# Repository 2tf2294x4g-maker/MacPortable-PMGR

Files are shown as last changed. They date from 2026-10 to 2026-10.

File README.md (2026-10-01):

# Macintosh Portable PMGR replacement

An open replacement for the **Mitsubishi M50753 power manager (PMGR)** in the Macintosh Portable.
The original chip is irreplaceable when it fails; this is a small two-board stack that solders onto
its footprint and runs open firmware on a Microchip **AVR128DB64**, reproducing the original's
behaviour toward the Mac.

| | |
|---|---|
| **Interposer** | 16.3 mm square, castellated — solders onto the M50753's footprint on the logic board |
| **MCU board** | 20.0 × 23.5 mm — carries the AVR, plugs onto the interposer through a Hirose DF12 connector |
| **J21 breakout** *(optional)* | sits between the two for development, bringing every PMGR signal out to 2.54 mm Dupont headers |

## Photos

<table>
<tr>
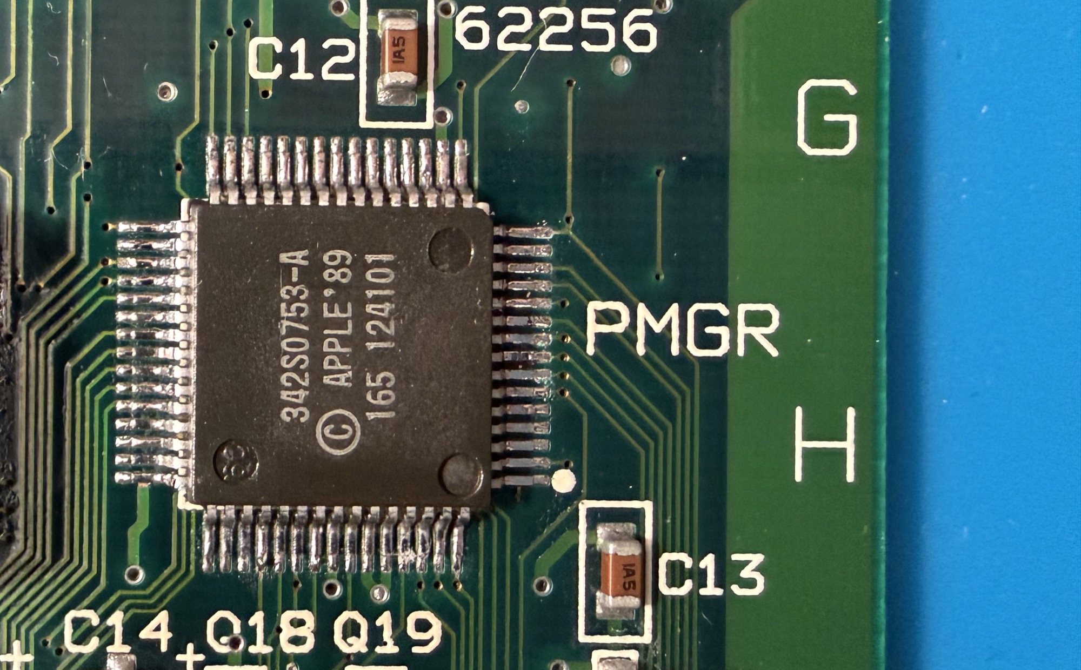
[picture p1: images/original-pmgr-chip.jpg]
The original M50753 power manager on the logic board
<td width="50%"><br><b>Before:</b> the original M50753 (Apple 342S0753-A) at the PMGR position.</td>
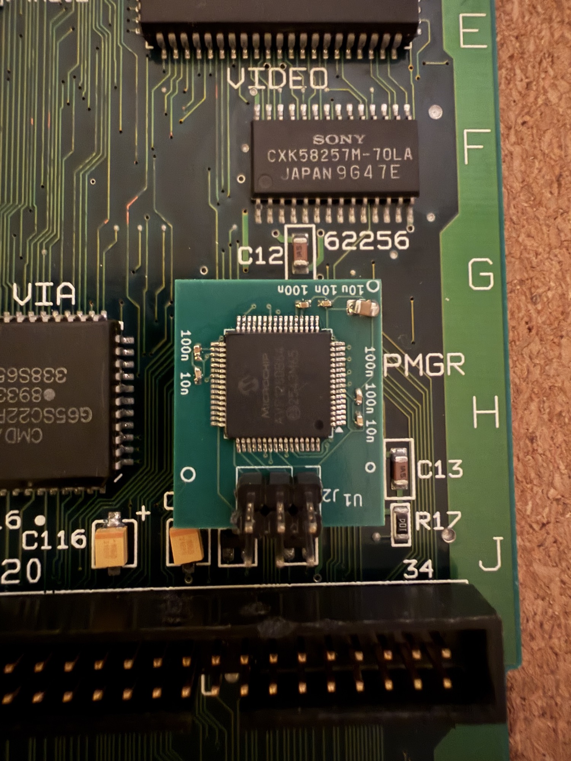
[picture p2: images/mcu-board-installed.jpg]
The replacement MCU board installed at the PMGR position
<td width="50%"><br><b>After:</b> the replacement stack at the same position.</td>
</tr>
<tr>
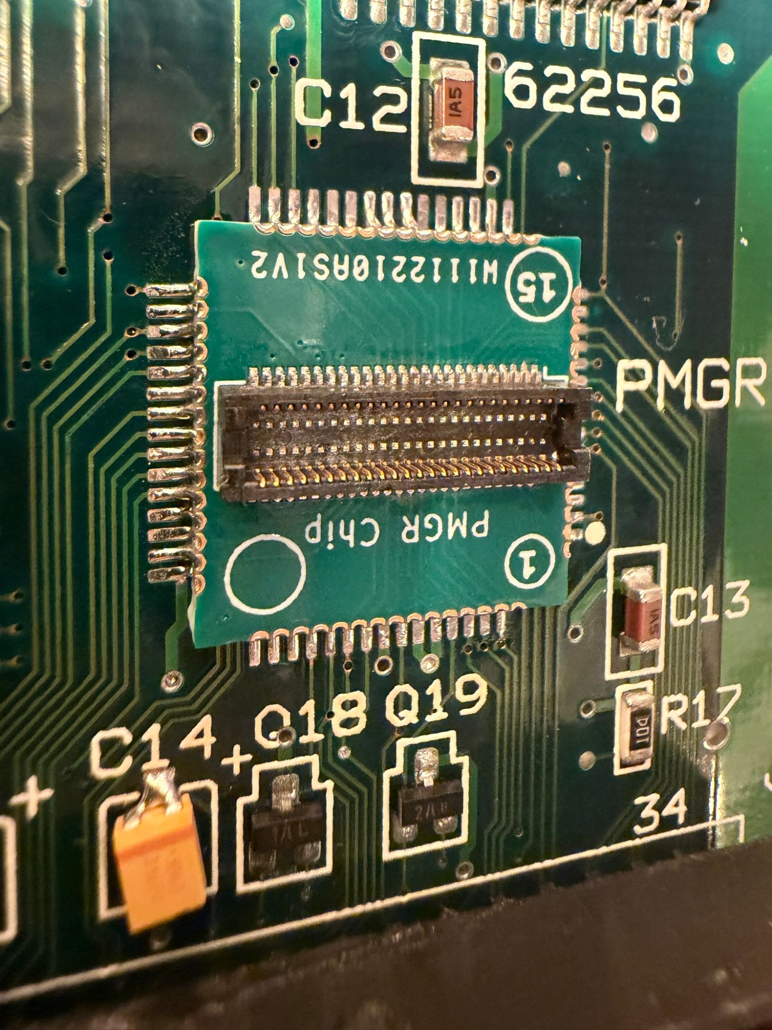
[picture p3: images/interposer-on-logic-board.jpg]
The interposer soldered to the M50753 footprint
<td><br>The interposer soldered to the original footprint. This first batch is labelled <code>PMGR Chip</code>; boards made from the current files say <code>J1</code>.</td>
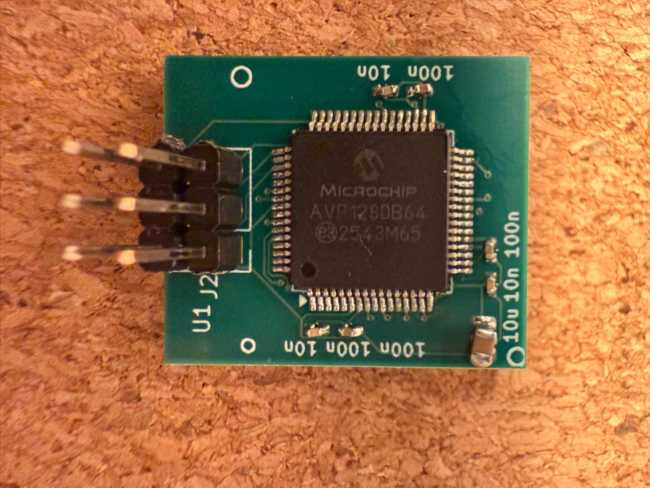
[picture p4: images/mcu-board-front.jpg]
MCU board, top side
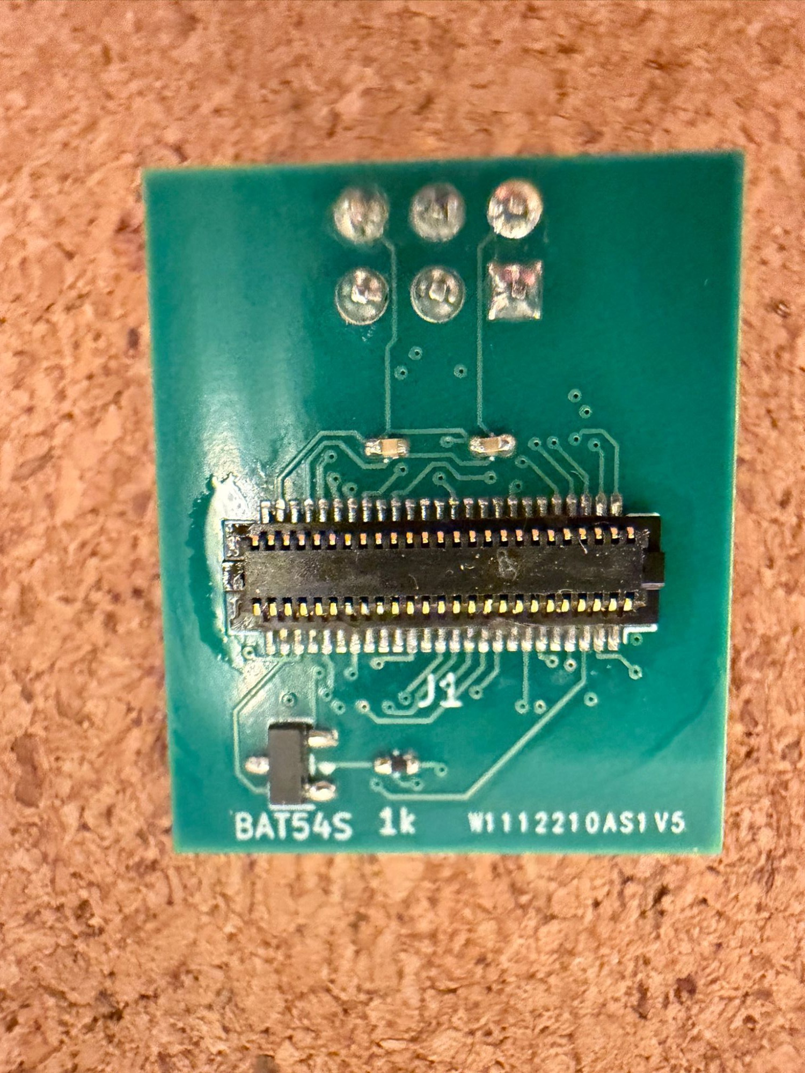
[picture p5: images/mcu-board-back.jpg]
MCU board, underside
<td><br>MCU board, top: the AVR128DB64 and the UPDI programming header <code>J2</code>.<br><br><br>Underside: the DF12 socket <code>J1</code>, and the <code>BAT54S</code> + 1 kΩ clamp on the battery-sense line.</td>
</tr>
</table>

## Status — version 0.1, prototype

**Working in a Macintosh Portable.** It boots, sleeps and wakes, shuts down and honours the reset
switch under System 6.0.8 and 7.5.3, and a supervised fast charge terminates correctly.

It has **only been installed and tested in a Macintosh Portable M5120** (the original, non-backlit
model), with a second, unmodified Portable kept as the reference. **The backlit Portable (M5126) has not
been tried.**

It is a **prototype**. Some parts of the charging behaviour have not been characterised on
hardware yet, and the PowerBook 100 (which uses the same PMGR) has not been tried. Read
[`docs/VERIFIED.md`](docs/VERIFIED.md) for exactly what has and has not been shown — before relying
on it unattended.

## Before you start: this is fine-pitch soldering

Building and fitting this needs **experienced surface-mount work** — it is not a beginner's kit:

- a **0.5 mm-pitch TQFP-64** (the AVR) and two **50-pin, 0.5 mm-pitch** Hirose DF12 connectors;
- **0402** resistors and capacitors (about 1 × 0.5 mm), several on the board's **underside**;
- removing the original **60-lead power manager** from the Mac's logic board, then soldering the
  interposer's **castellated edges** onto that footprint.

You'll want a hot-air station with preheat, a fine-tip iron, flux, solder wick, and magnification —
a stereo microscope makes this far easier. Having the fab assemble the MCU board removes most of the
0.5 mm work; removing the original chip and fitting the interposer still has to be done by hand.
See [`docs/BUILD.md`](docs/BUILD.md).

## ⛔ Safety — read before you start

- **The battery-sense input of an ORIGINAL M50753 is unprotected.** On a machine still carrying
  the original chip, never put more than **6.5 V** on the battery input while probing; over-driving
  that pin is a documented way to destroy the chip. (This design adds a clamp on that line.)
- **Never take power from the floppy connector (J15)** for accessories such as an LCD controller.
  It destroyed a PMGR during development.
- **Supervise the first charge.** The charger was designed for the original Gates/EnerSys Cyclon
  cells, which accept an unlimited initial current. Many modern substitute packs are rated far lower.
- **Every flash must re-write the calibration record** (see [`docs/BUILD.md`](docs/BUILD.md)).
  Without it the firmware deliberately refuses to fast-charge.
- **After any programmer operation — flash, fuses, even just reading the device ID — unplug the
  programmer and power-cycle the machine** (supply or battery disconnected) before expecting it to
  start. Otherwise a machine that is shut down may not wake from the keyboard. While the programmer
  is connected it **back-feeds the board**, so switching off is not a power cycle.

## Repository

```
docs/BUILD.md             start here: order, assemble, program, calibrate, install
docs/PROGRAMMING.md       building the firmware and flashing the AVR, step by step
docs/VERIFIED.md          what has been shown on hardware, and what has not
docs/REFERENCE-MEASUREMENTS.md  known-good voltages and pin references to check against
docs/ASSEMBLY.md          the detailed, bench-tested assembly procedure
docs/PINOUT.md            M50753 pin -> interposer -> AVR mapping
docs/MCU-BOARD-SCHEMATIC.md
docs/BOM.md, ORDER-LIST.md
hardware/mcu-board/       KiCad board + Gerbers
hardware/interposer-v2/   KiCad board + Gerbers
hardware/breakout-j21/    KiCad board + Gerbers + assembly files
firmware/                 AVR firmware, host-side unit tests, fuse policy
tools/                    flashing and calibration scripts
```

## The ROM image

The M50753 carries a small program ROM that the Mac can read back. **The default build contains a
synthetic image — no Apple code anywhere in this repository.** A byte-exact build is possible if you
supply your own dump of the original ROM; see [`firmware/README.md`](firmware/README.md). Never
commit that dump.

## Licences

- Hardware (`hardware/`): **CERN Open Hardware Licence v2 — Strongly Reciprocal** (`LICENSE`)
- Firmware and tools (`firmware/`, `tools/`): **MIT** (`LICENSE-MIT`)

This repository is the clean release. The full development record — every measurement, the
mistakes and their corrections — is kept separately. Questions and results from other machines are
welcome as issues; readings from original, un-modified Portables are especially useful.

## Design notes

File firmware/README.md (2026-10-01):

# Firmware — AVR128DB64

Open replacement firmware for the Macintosh Portable's M50753 power manager. It serves the Mac's
host protocol, runs the battery and charging logic autonomously, handles sleep, wake and reset, and
keeps PRAM in EEPROM.

## Build

```bash
brew trust osx-cross/avr                       # Homebrew gates third-party taps
brew install osx-cross/avr/avr-gcc@14
export PATH="/opt/homebrew/opt/avr-gcc@14/bin:$PATH"   # keg-only
make
```

`avr128db64` is supported natively by avr-gcc 14 — no Microchip device pack needed. The image size
depends on the compiler version (avr-gcc 14.3.0 builds 10715 bytes); never treat a size difference
between toolchains as a regression.

| target | |
|---|---|
| `make` | build `pmgr.hex` |
| `make fuses` | write and verify the fuses — **once per board, before the first flash** (see `FUSES.md`) |
| `make flash PORT=/dev/tty.…` | flash over SerialUPDI. ⚠️ This does **not** write the calibration record; prefer `../tools/pmgr_flash_with_pram.py` (see `../docs/BUILD.md` §7) |
| `make clean` | |

For wiring the programmer and flashing step by step, see [`../docs/PROGRAMMING.md`](../docs/PROGRAMMING.md).

## Host-side tests

The protocol, PRAM save, ADC handling, calibration and charging logic are compiled natively and
tested on your computer — no hardware needed:

```bash
make -C test run_save run_latch run_adb_latch run_deadline run_adc run_charging run_calib run_calib_cross
```

## Layout

```
src/            main.c and one file per subsystem: bus, proto, handlers, adb, adc, calib,
                pram, pwm, rom, selftest
include/        headers. pmgr_pins.h is GENERATED from the MCU board by gen_pins.py
test/           native test harness and the eight suites
gen_pins.py     regenerates include/pmgr_pins.h from hardware/mcu-board/pmgr_mcu.kicad_pcb
tools_rom2h.py  converts YOUR OWN ROM dump to a header, for the byte-exact build (below)
FUSES.md        the fuse configuration pmgr.hex assumes, and why
```

## The ROM image

The Mac can read back the M50753's program ROM. **The default build uses a synthetic image; there
are no Apple bytes in this repository.** For a byte-exact build, supply your own dump:

```bash
python3 tools_rom2h.py /path/to/pmuv1.bin > include/pmgr_rom_image.h
make EXTRA_CFLAGS=-DPMGR_FAITHFUL_ROM
```

⛔ `include/pmgr_rom_image.h` **is** the ROM image. It is gitignored; never commit or publish it.

## Debug pads

| pad | meaning when high |
|---|---|
| `DBG2` (PF3) | the ADC scale self-check passed. ⚠️ Low until the machine has been switched on once |
| `DBG1` (PF4) | an ADC conversion **timed out** — latched, never cleared until reset |
| `DBG0` (PF5) | the RTC/PIT synchronisation timed out |

`DBG2` high with `DBG1` low is a healthy ADC.

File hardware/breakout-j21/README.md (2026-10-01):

# J21 breakout (development only)

A DF12 pass-through that sits between the interposer and the MCU board and brings every PMGR signal
out to **two 1×25 2.54 mm headers labelled with the Portable's J21 pin numbers** — ready for Dupont
leads, a logic analyser or a scope. Take it out before closing the machine.

| | |
|---|---|
| Size | 27 × 88 mm |
| Fab | 2 layer · 1.6 mm · HASL |
| Parts | `J1` DF12 socket (`DS`, bottom), `J2` DF12 header (`DP`, top), two 1×25 2.54 mm headers |
| Fabrication files | `gerbers/` (with BOM, placement and assembly drawings for a PCBA order) |
| Design | `pmgr_breakout_j21.kicad_pcb` (KiCad 9) — see `BOM.md` |

⚠️ **Vias are 0.20 mm drill with a 0.125 mm annular ring.** PCBWay builds that on their standard
order; JLCPCB's standard process needs 0.30 mm / 0.13 mm.

Hand assembly: **solder `J2` (top) first, `J1` (bottom) last**, with the board raised on standoffs —
they sit back to back. Mate each DF12 pair by hand before soldering: every stack height shares the
footprint, and these must be 3.0 mm.

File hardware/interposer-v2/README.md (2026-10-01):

# Interposer

Solders onto the M50753's footprint on the logic board by 60 castellated half-holes, and carries the
DF12 header (`J1`) the MCU board plugs into. It remaps the original chip's pins to the connector —
see [`../../docs/PINOUT.md`](../../docs/PINOUT.md).

| | |
|---|---|
| Size | 16.3 × 16.3 mm |
| Fab | 4 layer · 1.6 mm · **ENIG (required)** · castellated plating on all 60 half-holes |
| Layers | F.Cu / In1.Cu GND / In2.Cu GND / B.Cu |
| Fabrication files | `gerbers/`, `pmgr_interposer_v2_gerbers.zip` |
| Design | `pmgr_interposer_v2.kicad_pcb` (KiCad 9) |

The Gerbers here were regenerated from the board file. Copper, outline and drill are identical to
the boards built and tested in development; only the silkscreen differs — the connector is labelled
`J1`, where the first batch read `PMGR Chip`.

Assembly: [`../../docs/ASSEMBLY.md`](../../docs/ASSEMBLY.md), Steps 2 and 4.

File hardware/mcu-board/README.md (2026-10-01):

# MCU board

Carries the AVR128DB64, its decoupling, a clamp on the battery-sense input, the DF12 socket that
mates with the interposer (`J1`, bottom), and a 2×3 UPDI programming header (`J2`).

| | |
|---|---|
| Size | 20.0 × 23.5 mm |
| Fab | 4 layer · 1.6 mm · ENIG · two-sided stencil |
| Fabrication files | `gerbers/`, `pmgr_mcu_gerbers.zip` |
| Design | `pmgr_mcu.kicad_pcb` (KiCad 9) |

The Gerbers here are the ones the tested boards were made from, and are checked against
`pmgr_mcu.kicad_pcb` on every layer each time this repository is generated. Assembly: [`../../docs/ASSEMBLY.md`](../../docs/ASSEMBLY.md), Step 1. Connections:
[`../../docs/MCU-BOARD-SCHEMATIC.md`](../../docs/MCU-BOARD-SCHEMATIC.md).

⚠️ For a PowerBook 100, `J2` must not be a vertical header — there is only 9–10 mm of clearance.

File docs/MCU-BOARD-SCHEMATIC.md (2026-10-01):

# PMGR MCU Board — Schematic Specification

Everything needed to draw the MCU board in KiCad. All library names verified present in KiCad 9.

---

## Components

| Ref | Value | KiCad symbol | Footprint |
|---|---|---|---|
| **U1** | AVR128DB64-I/PT | `MCU_Microchip_AVR_Dx:AVR128DB64x-xPT` | `Package_QFP:TQFP-64_10x10mm_P0.5mm` *(already set in the symbol)* |
| **J1** | Hirose DF12C3.0-50DS-0.5V | `Connector_Generic:Conn_02x25_Odd_Even` | `Connector_Hirose:Hirose_DF12_DF12C3.0-50DS-0.5V_2x25_P0.50mm_Vertical` — **stock KiCad 9, no custom lib** |
| **J2** | UPDI header 2×3 | `Connector_Generic:Conn_02x03_Odd_Even` | `Connector_PinHeader_2.54mm:PinHeader_2x03_P2.54mm_Vertical` |
| C1–C4 | 100 nF | `Device:C` | 0402 or 0603 |
| C5–C7 | 10 nF | `Device:C` | 0402 or 0603 |
| C8 | 10 µF | `Device:C` | 0805 |
| R1 | 1 kΩ | `Device:R` | 0402/0603 — A/D series resistor |
| D1 | BAT54S | `Diode:BAT54S` | SOT-23 — A/D clamp |

---

## AVR128DB64 pin numbers (TQFP-64, from the KiCad symbol)

| Port | Pin numbers |
|---|---|
| **PORTA** | PA0=**62** PA1=**63** PA2=**64** PA3=**1** PA4=**2** PA5=**3** PA6=**4** PA7=**5** |
| **PORTB** | PB0=8 PB1=9 PB2=10 PB3=11 PB4=12 PB5=13 PB6=14 PB7=15 |
| PORTC | PC0=16 PC1=17 PC2=18 PC3=19 PC4=22 PC5=23 PC6=24 PC7=25 |
| **PORTD** | PD0=26 PD1=27 PD2=28 PD3=29 PD4=30 PD5=31 PD6=32 PD7=**33** *(VREFA/PD7)* |
| **PORTE** | PE0=36 PE1=37 PE2=38 PE3=39 PE4=40 PE5=41 PE6=42 PE7=43 |
| PORTF | PF0=**44** PF1=**45** PF2=46 PF3=47 PF4=48 PF5=49 PF6=**50** *(RESET, input only)* |
| **PORTG** | PG0=52 PG1=53 PG2=54 PG3=55 PG4=58 PG5=59 PG6=60 PG7=61 |
| Power | VDD=**6** GND=**7** AVDD=**34** AGND=**35** VDDIO2=**20** |
| Program | UPDI=**51** |

⚠️ **PA0/PA1 (62/63) are the XTALHF pins** and **PF0/PF1 (44/45) are XTAL32K** — all fine as GPIO here since we use the internal oscillator, but don't fit crystals.

---

## Net list

> **Connector positions updated 2026-08-25** for the routing remap (`ROUTING-ANALYSIS.md`). AVR port grouping is unchanged — it is preserved by MCU-board routing, not by connector numbering. Previous version: `MCU-BOARD-SCHEMATIC.md.bak-perimeter`.

### Data bus — PORTA

**All eight on one port — required.** The protocol handshake depends on reading the bus in a single instruction.

| Net | AVR pin | TQFP | J1 |
|---|---|---|---|
| VIAD0 | PA0 | 62 | **30** |
| VIAD1 | PA1 | 63 | **29** |
| VIAD2 | PA2 | 64 | **28** |
| VIAD3 | PA3 | 1 | **27** |
| VIAD4 | PA4 | 2 | **26** |
| VIAD5 | PA5 | 3 | **33** |
| VIAD6 | PA6 | 4 | **34** |
| VIAD7 | PA7 | 5 | **35** |

### Handshake and control — PORTB

| Net | AVR pin | TQFP | J1 |
|---|---|---|---|
| PMREQ_N | PB0 | 8 | **31** |
| PMACK_N | PB1 | 9 | **32** |
| PMINT_N | PB2 | 10 | **1** |
| SYS_RST_N | PB3 | 11 | **5** |
| RESET_N | PB4 | 12 | **6** |
| PMGR_RESET_N | PB5 | 13 | **8** |
| VIA_TEST | PB6 | 14 | **4** |
| ONESEC_N | PB7 | 15 | **2** |

### Power control — PORTG

| Net | AVR pin | TQFP | J1 |
|---|---|---|---|
| SYS_PWR_N | PG0 | 52 | **17** |
| MINUS5_EN | PG1 | 53 | **16** |
| SOUND_PWR_N | PG2 | 54 | **46** |
| SERIAL_PWR_N | PG3 | 55 | **45** |
| MODEM_PWR_N | PG4 | 58 | **44** |
| HD_PWR_N | PG5 | 59 | **43** |
| SCC_CNTRL | PG6 | 60 | **42** |
| IWM_CNTRL | PG7 | 61 | **41** |

### Status inputs — PORTE

| Net | AVR pin | TQFP | J1 |
|---|---|---|---|
| AKD | PE0 | 36 | **18** |
| STOP_CLK | PE1 | 37 | **19** |
| CHRG_ON_N | PE2 | 38 | **20** |
| KBD_RST_N | PE3 | 39 | **21** |
| HICHG | PE4 | 40 | **22** |
| RING_DETECT | PE5 | 41 | **15** |
| MODEM_AB | PE6 | 42 | **14** |

### ADB, display, misc — PORTD

| Net | AVR pin | TQFP | J1 |
|---|---|---|---|
| PMGR_ADB | PD1 | 27 | **13** |
| FDB | PD2 | 28 | **12** |
| DISP_BLANK_N | PD3 | 29 | **11** |
| MODEM_INS_N | PD4 | 30 | **10** |
| SOUND_OFF | PD5 | 31 | **3** |
| PMGR_PWM | PD6 | 32 | **36** |

### Analogue and remaining — PORTD/PORTC

> `PMGCLK_F` is **monitor-only**. It is M50753 pin 19 (Xin) and the AVR runs from its internal 24 MHz oscillator. It is wired to PC4 so firmware can observe it, but the AVR accepts an external clock **only on PA0**, which is VIAD0 — so it can never be used as a clock source.

| Net | AVR pin | TQFP | J1 |
|---|---|---|---|
| AD_FILTER | PD0 | 26 | **38** |
| PMGR_IN0 | PD7 | 33 | **37** |
| SOUND_LATCH | PC0 **⚠️ MVIO** | 16 | **39** |
| OFF_HOOK | PC1 **⚠️ MVIO** | 17 | **40** |
| SIXTYHZ | PC2 **⚠️ MVIO** | 18 | **7** |
| PMGCLK_F | PC4 **⚠️ MVIO** | 22 | **9** |

### Debug indicators — PORTF ⭐ ADDED 2026-08-28

| Net | AVR pin | TQFP | J1 |
|---|---|---|---|
| DBG0 | PF5 | 49 | *(test pad)* |
| DBG1 | PF4 | 48 | *(test pad)* |
| DBG2 | PF3 | 47 | *(test pad)* |

⚠️ **These were missing from this document while the firmware already drove
them.** Found by cross-checking `firmware/include/pmgr_pins.h` against this net
list, 2026-08-28. PF3-PF5 are free (only PF0/PF1 and PF6 are reserved), so there
is no conflict — but there were no PADS, and that defeats the purpose.

**They must be brought out to test pads.** The whole design intent is that they
are readable with a DMM the instant the AVR is programmed — no host, no
analyser, no ADB (see the header comment in `firmware/src/pmgr_adc.c`). On a
20 x 23.5 mm board inside a closed Portable, an un-padded TQFP pin cannot be
probed, so the diagnostic path simply does not exist.

What they report in the NORMAL build:

| Pin | HIGH means |
|---|---|
| DBG2 | ADC scale self-check PASSED (`ref5V_Level` ≈ **113**) |
| DBG1 | ⛔ an ADC conversion TIMED OUT — every reading since is a stand-in |
| DBG0 | ⛔ RTC/PIT sync timed out |

⛔ **DBG2 is LOW until the machine has been switched on at least once**, and
that is correct, not a fault. AD_Ref sits on the switched `(5/0)` rail and reads
~0 V while the machine is off, so the scale cannot be verified at power-on — the
check is deferred to the 1 Hz tick and latches its pass the first time the rail
is up. ⚠️ This supersedes the claim that the check is *"measurable the instant
the AVR is programmed"*: with no machine attached, DBG2 stays low forever.
`MEASUREMENTS.md` 2.56.

DBG2 high with DBG1 low is a healthy ADC. The SELFTEST build reuses all three as
a 3-bit result code instead — see `pmgr_selftest.h`.

1 mm round pads on the top side are enough; they are probed with a meter tip,
not clipped.

### Power — plane connections

**GND is a plane on both inner layers** — each pad simply vias down to it. **+5V is routed as ordinary traces** (only five connection points on the interposer).

| Net | J1 positions | How carried |
|---|---|---|
| +5V | **47, 48** | routed traces |
| GND | **23, 24, 25, 49** | In1.Cu + In2.Cu planes |
| *spare* | **50** | — |

---

## Power supply

```
+5V (always-on rail, from J1 pins 47/48)
 ├── VDD    (pin 6)   ── C1 100nF ── GND    + C5 10nF
 ├── AVDD   (pin 34)  ── C2 100nF ── GND    + C6 10nF
 ├── VDDIO2 (pin 20)  ── C3 100nF ── GND    + C7 10nF
 └── bulk             ── C8 10µF  ── GND
GND ── AGND (pin 35), GND (pin 7)
```

**Datasheet requirements (§4.2, §5.3):**
- All VDD/AVDD pins at the **same voltage**; AVDD must **ramp with VDD**
- In single-supply mode **VDDIO2 must rise with VDD** — tie it to +5V even though PORTC is lightly used
- One decoupling pair **per supply pin**, same side of the board, shortest possible traces, capacitors first in the power chain

---

## A/D clamp — the one improvement over Apple's design

The M50753 dies when the battery-sense line exceeds Vcc+0.3 V. Protect the input:

```
J1 pin 38 (AD_FILTER) ──[ R1 1k ]──┬── PD0 (pin 26, ADC)
                                    │
                                 D1 BAT54S
                              (dual Schottky)
                     pin 1 GND · pin 2 +5V · pin 3 ADC_IN
                     (one diode GND→ADC_IN, one ADC_IN→+5V)
```

R1 limits fault current; the BAT54S clamps to the rails. ⛔ Corrected 2026-09-14: this drawing said "anode→+5V, cathode→GND",
which is the reverse of a clamp; the layout was always right (MEASUREMENTS 2.192 correction). Measured the same day: pin 40 and the
reported level agree within 1 level, so R1 and D1 cost nothing. Sized so a hybrid swinging toward battery voltage can't damage the ADC input.

---

## UPDI header (J2, 2×3)

Datasheet §4.4.1 recommends a 2×3 100-mil header even though only three pins are used, because programming tools ship with 2×3 connectors.

| J2 pin | Net |
|---|---|
| 1 | UPDI → U1 pin 51 |
| 2 | +5V |
| **3** | ⭐ **`DBG0`** → U1 pad **49** (`PF5`) |
| **4** | ⭐ **`DBG1`** → U1 pad **48** (`PF4`) |
| **5** | ⭐ **`DBG2`** → U1 pad **47** (`PF3`) |
| 6 | GND |

> ⛔⛔ **CORRECTED 2026-09-09 FROM THE FABRICATED BOARD FILE.** This table said
> *"3, 4, 5 — no connect"*. **It was wrong.** `mcu-board/pmgr_mcu.kicad_pcb`
> routes all three to the `DBG` nets, pad for pad.
>
> ⚠️ **The error propagated the wrong way.** `ASSEMBLY.md` correctly said *"`J2`
> carries UPDI plus `DBG0/1/2`"*, and on 2026-09-08 that correct statement was
> **overridden** on the strength of this table — sending the operator to hunt for
> test pads that do not exist. ⭐ There are **no `TP` footprints on this board**;
> the header *is* the debug access.
>
> ⛔ **The lesson: the board file outranks the prose.** Both were available; the
> prose was believed.

Pins 2 and 6 are the standard VCC/GND positions on the AVR 6-pin header. **Confirm pin 1 for UPDI against your programmer** — Atmel-ICE and SNAP differ, and some tools expect UPDI on pin 5 (the RESET position).

---

## Not fitted

- **No crystal.** Internal oscillator does 24 MHz. Leave PA0/PA1 and PF0/PF1 as GPIO or unused.
- **No external RESET pull-up** — internal pull-up is sufficient (§4.3). Add a switch only if wanted: 330 Ω in series, 100 nF to GND.
- **PF6 (50) is RESET, input only** — leave it.

---

## J1 — board-to-board connector (RESOLVED 2026-08-25)

**Hirose DF12(3.0) series, 0.5 mm pitch, 50 position, 3.0 mm mated stack height.**

| Board | Part | KiCad footprint |
|---|---|---|
| **MCU board** (J1) | **DF12C3.0-50DS-0.5V** — socket | `Connector_Hirose:Hirose_DF12_DF12C3.0-50DS-0.5V_2x25_P0.50mm_Vertical` |
| **Interposer** (J1) | **DF12E3.0-50DP-0.5V** — header | `Connector_Hirose:Hirose_DF12_DF12E3.0-50DP-0.5V_2x25_P0.50mm_Vertical` |

Both footprints ship with KiCad 9 — nothing to source or draw.

### Land pattern — verified against the Hirose datasheet (doc A306, p.10)

Read directly from the *Recommended PCB Footprint* drawing and cross-checked against the KiCad footprints; **every value agrees**:

| Dimension | Datasheet | KiCad |
|---|---|---|
| Pitch (P) | 0.5 ± 0.02 | 0.5 ✓ |
| Pad width | 0.3 ± 0.02 | 0.3 ✓ |
| Pad length | 1.6 ± 0.02 | 1.6 ✓ |
| Gap between rows | 2.0 ± 0.05 | (3.6 − 1.6) = 2.0 ✓ |
| Row centre-to-centre | 3.6 (derived) | 3.6 ✓ |
| Contact span (B) | 12.0 | 12.0 ✓ |
| Body length (A) | 14.6 (DS) / 14.7 (DP) | — |
| Boss holes | ⌀0.6 +0.05/−0.03, D = 14.1 apart | not present — **these variants have no guide boss** |

### Pin numbering — confirmed

**Pins 1–25 run along one row, 26–50 along the other** (not odd/even staggered). The DP footprint is mirrored relative to DS, so when the two boards are stacked the pins mate **1↔1 … 50↔50** with no renumbering. The net list above can be used verbatim on both boards.

### Height budget — OK

DF12(3.0) adds **3.0 mm** between the two board faces. Total stack above the logic board:

```
interposer PCB (0.8–1.6) + 3.0 mm connector + MCU PCB (0.8–1.6)  ≈ 4.6–6.2 mm
```

The M50753 it replaces is ~2.0 mm tall, so this adds ~3–4 mm over stock.

**Available clearance = 15 mm — measured.** Datum: **logic board surface → the underside of the keyboard / top plastic** on the Macintosh Portable. That is the same datum the stack above is built from, so the comparison is direct:

```
                    Portable   PowerBook 100
available            15.0 mm      10.4 mm     <- measured 2026-09-06
needed                6.2 mm       6.2 mm     (worst case, 1.6 mm boards)
margin                8.8 mm       4.2 mm
                       2.4x         1.7x
```

⭐ **Both machines measured.** The PowerBook 100 is the **binding** one vertically
and still clears by 1.7×.

**Height is not a constraint on this design.** DF12(3.0) confirmed **on both
machines**; no need to consider the shorter stack heights. ⭐⭐ That matters beyond
height: `CLEARANCE-MEASUREMENTS.md` notes the Portable's 4.1 mm VIA clears by only
0.5 mm at DF12(3.0) and **collides at every shorter stack**, so a PB100 that had
needed a 2.5 or 2.0 mm connector would have forced the outline in on that side.
It does not.

*(If a future revision ever does need to come down, DF12 is made in 2.0 and 2.5 mm stack heights with an **identical land pattern** — part number only, never the layout.)*

---

## Checks before ordering

1. ~~Verify **J1 pin numbering**~~ — **done**, see above
2. Confirm the **AIN channel number for PD0** in the ADC chapter (needed for firmware, not layout)
3. ~~Re-check M50753 pin numbers on the interposer side against sheet 12~~ —
   ✅ **ALREADY DONE 2026-08-26, on two independent sources.** Castellation
   numbering validated against the **PowerBook 100 silkscreen**; signal names
   from the annotated photograph of the actual M50753 **cross-checked against
   Apple sheet 12** and the firmware disassembly. See `PIN-MAPPING-PERIMETER.md`
   and `PIN-AUDIT.md`.
   ⚠️ This box sat unticked and on 2026-08-28 sent someone to re-verify it. See
   the warning in `PORT-AUDIT.md`: **a document can be stale even when the
   project's knowledge is not — before treating an item here as open, check
   whether another file has since closed it.**
5. ⭐ **Add test pads for DBG0/DBG1/DBG2 (PF5/PF4/PF3)** — see the net list
   above. Without them the power-on diagnostics cannot be read on an assembled
   board, which is the only reason they exist.
6. ✅ **Firmware pin map cross-checked against this net list 2026-08-28** — all
   43 shared nets agree on port, bit and TQFP number, and all 39 J1 positions
   agree with `PIN-MAPPING-PERIMETER.md`. Re-run that check if either file
   changes; it is the mapping the firmware silently depends on
4. ~~Measure vertical clearance over the U15H footprint~~ — **done: 15 mm measured vs 6.2 mm needed**, 2.4× margin

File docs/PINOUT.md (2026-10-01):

> ⚠️ **2026-08-26:** `FDB` (M50753 pin 27) is **`ADB_In`** — Port 4 bit 1, the ADB
> receive line. ADB is two pins: `ADB_Out` (P40, our `PMGR_ADB`) and `ADB_In`
> (P41, our `FDB`). See `PORT-AUDIT.md`.

# Interposer Pin Mapping

M50753 footprint pin → signal → interposer connector position → AVR port.

Chip pin numbers from Apple schematic 050-0219 sheet 12. Signal names and unused pins confirmed against the PMU firmware disassembly.

> ⚠️ **Verify every chip pin number against sheet 12 before routing.** These were transcribed from a scan.

---

## Design principles

**VIAD0–7 must land on one complete AVR port, in bit order.** The data bus is read and written as a whole byte in the hottest path of the handshake; splitting it across ports costs instructions on every transfer.

**PMREQ must be on an interrupt-capable pin** — the host asserting PMREQ is what drives the whole exchange.

**Group the handshake outputs** (PMACK, PMINT) on one port so they can be updated without read-modify-write races.

**Connector positions are grouped by function**, not by chip pin order — it makes both the interposer routing and the MCU board routing cleaner than a straight 1:1 mapping.

---

> ⛔ **2026-08-28 — THE PER-GROUP TABLES BELOW ARE STALE IN TWO COLUMNS.**
> Only the **Chip pin** and **Signal** columns are current. Both the **Conn** and
> the **AVR** columns are superseded drafts and will send you to the wrong pad and
> the wrong AVR pin:
>
> | Column | Superseded by | Example of the error |
> |---|---|---|
> | **AVR** | the *Revised assignment (final)* table further down this file, and `firmware/include/pmgr_pins.h` | handshake + control is on **PORTB**, not PORTC. PORTC is the **MVIO** port and is left spare. VIA_TEST is **PB6**, not PC6 |
> | **Conn** | `PIN-MAPPING-PERIMETER.md` / `ROUTING-ANALYSIS.md` ("Conn (new)") | VIA_TEST is connector position **4**, not 15 |
>
> The file already warns, below the final table, that *"two earlier drafts of this
> table were wrong."* These are those drafts. They are kept because the chip-pin ↔
> signal transcription against sheet 12 is still the record; the routing is not.
> **`firmware/include/pmgr_pins.h` is authoritative for AVR pins.**

## Signals to route (45 of 60)

### Data bus — 8 lines · AVR PORTA (contiguous, bit order)
⛔ **`Conn` and `AVR` below are STALE DRAFTS** — see the warning at the top. Current: connector = `PIN-MAPPING-PERIMETER.md`, AVR pin = `MCU-BOARD-SCHEMATIC.md`.

| Chip pin | Signal | Conn | AVR |
|---|---|---|---|
| 5 | VIAD0 | 1 | PA0 |
| 4 | VIAD1 | 2 | PA1 |
| 3 | VIAD2 | 3 | PA2 |
| 2 | VIAD3 | 4 | PA3 |
| 1 | VIAD4 | 5 | PA4 |
| 60 | VIAD5 | 6 | PA5 |
| 59 | VIAD6 | 7 | PA6 |
| 58 | VIAD7 | 8 | PA7 |

### Handshake and system control — 8 lines · AVR PORTC
⛔ **`Conn` and `AVR` below are STALE DRAFTS** — see the warning at the top. Current: connector = `PIN-MAPPING-PERIMETER.md`, AVR pin = `MCU-BOARD-SCHEMATIC.md`.

| Chip pin | Signal | Dir | Conn | AVR | Note |
|---|---|---|---|---|---|
| 6 | PMREQ* | in | 9 | **PC0** | **interrupt-capable pin required** |
| 7 | PMACK* | out | 10 | PC1 | |
| 8 | PMINT* | out | 11 | PC2 | pulsed, not held |
| 12 | SYS_RST* | out | 12 | PC3 | releases CPU + gates ROM overlay |
| 13 | RESET* | out | 13 | PC4 | |
| 18 | PMGR_RESET* | in | 14 | PC5 | system can reset the PMGR |
| 11 | VIA_TEST | — | 15 | PC6 | |
| 9 | 1SEC* | out | 16 | PC7 | → VIA CA2 |

### Power control outputs — 8 lines · AVR PORTD
⛔ **`Conn` and `AVR` below are STALE DRAFTS** — see the warning at the top. Current: connector = `PIN-MAPPING-PERIMETER.md`, AVR pin = `MCU-BOARD-SCHEMATIC.md`.

| Chip pin | Signal | Conn | AVR |
|---|---|---|---|
| 37 | **SYS_PWR*** | 17 | PD0 |
| 38 | −5_EN | 18 | PD1 |
| 39 | SOUND_PWR* | 19 | PD2 |
| 40 | SERIAL_PWR* | 20 | PD3 |
| 41 | MODEM_PWR* | 21 | PD4 |
| 42 | HD_PWR* | 22 | PD5 |
| 43 | SCC_CNTRL | 23 | PD6 |
| 44 | IWM_CNTRL | 24 | PD7 |

### Status inputs — 7 lines · AVR PORTE/F
⛔ **`Conn` and `AVR` below are STALE DRAFTS** — see the warning at the top. Current: connector = `PIN-MAPPING-PERIMETER.md`, AVR pin = `MCU-BOARD-SCHEMATIC.md`.

| Chip pin | Signal | Conn | Note |
|---|---|---|---|
| 35 | AKD | 25 | any key down |
| 34 | STOP_CLK | 26 | |
| 33 | CHRG_ON* | 27 | charger present |
| 32 | KBD_RST* | 28 | resets keyboard M50740 |
| 31 | HICHG | 29 | |
| 30 | RING_DETECT | 30 | |
| 29 | MODEM_A/B | 31 | |

### ADB, display, misc — 6 lines
⛔ **`Conn` and `AVR` below are STALE DRAFTS** — see the warning at the top. Current: connector = `PIN-MAPPING-PERIMETER.md`, AVR pin = `MCU-BOARD-SCHEMATIC.md`.

| Chip pin | Signal | Conn |
|---|---|---|
| 28 | PMGR_ADB (out) | 32 |

> ⛔⛔ **MEASURED 2026-09-05 (`MEASUREMENTS.md` 2.48): `PMGR_ADB` is INVERTED,
> ~1 V, and OUTPUT-ONLY.**
>
> | `PMGR_ADB` | ADB bus |
> |---|---|
> | **LOW (0 V)** | **RELEASED** (high) — also the state while listening |
> | **HIGH (~0.6–1.0 V)** | **PULLED LOW** |
>
> ⭐ The ~1 V maximum is not a valid CMOS high: pin 28 drives a **transistor base
> or open-drain stage**, not a logic input. Confirmed output-only — when the
> keyboard drives the bus low, pin 28 stays at **0.00 V** rather than following
> it.
>
> ⛔ **Driving this push-pull with active-high = bus-high holds the ADB line low
> permanently.** That presents as a dead keyboard and mouse, with no obvious
> electrical fault to find.
| 27 | FDB (ADB in) | 33 |
| 26 | DISP_BLANK* | 34 |
| 25 | MODEM_INS* | 35 |
| 10 | SOUND_OFF | 36 |
| 57 | PMGR_PWM | 37 |

### Analogue and clocks — 6 lines
⛔ **`Conn` and `AVR` below are STALE DRAFTS** — see the warning at the top. Current: connector = `PIN-MAPPING-PERIMETER.md`, AVR pin = `MCU-BOARD-SCHEMATIC.md`.

| Chip pin | Signal | Conn | Note |
|---|---|---|---|
| 52 | **A/D_FILTER** | 38 | **ADC pin. Clamp on MCU board.** |
| 54 | PMGR_IN0 | 39 | |
| 51 | SOUND_LATCH | 40 | |
| 50 | OFF_HOOK | 41 | |
| 15 | 60HZ | 42 | → INT1 |
| 19 | PMGCLK_F | 43 | original Xin — **not needed**, AVR uses internal osc |

### Power — 2 lines
| Signal | Conn |
|---|---|
| VCC (always-on 5V) | 44, 45 |
| GND | 46, 47, 48 |

Spare / unrouted: 49, 50

---

## Pins deliberately NOT routed (15)

| Chip pin | Why |
|---|---|
| 36 (P10) | Firmware comments it **"NC — not connected, probably for testing"** |
| 49 (IN4) | PMGR_IN4 — unused by firmware |
| 48, 47, 46 (IN5–7) | unused |
| 20 (Xout) | crystal out — AVR uses internal oscillator |
| 22 (RSTout) | not needed |
| 14 (CNTR), 21, 24 (2PH) | timer/counter pins, unused in this application |
| 16 (INT2) | tied to RESET*, already routed as pin 13 |
| 23, 45, 53, 55, 56 | Vcc/Vss duplicates and no-connects — **verify against sheet 12** |

⚠️ **Route the castellation pads for these anyway** (mechanically they still land on the Mac's footprint) — just leave them unconnected on the interposer. Do **not** omit the physical pads.

---

## Connector

**50 positions used of 50.** Suggests the **0.4 mm Hirose DF40** (10 mm long) over the 0.5 mm part, since it opens the routing channel from 1.9 mm to 3.15 mm — enough for 15 traces per side on two layers at standard 6/6 mil rules.

Order positions so each functional group is contiguous, as above. That keeps interposer routing short and makes the MCU board's port assignment fall out naturally.

---

## AVR port assignment — REVISED against the datasheet (2026-08-24)

Verified from AVR128DB28/32/48/64 datasheet DS40002247B.

**AVR128DB64 ports:** PA[7:0], PB[7:0], PC[7:0], PD[7:0], PE[7:0], PF[6:0], PG[7:0] — **55 GPIO** (54 usable as outputs).

### Three datasheet findings that change the plan

**1. "External interrupt on all general purpose pins."** Any pin can take PMREQ — no constraint at all. My earlier note about needing an interrupt-capable pin was wrong.

**2. PF7 is dedicated UPDI, not a GPIO.** The port list is PF[**6**:0], so PF7 never appears as I/O. Nothing to "reserve" — it simply isn't available. **PF6 is RESET and is input-only.**

**3. ⚠️ PORTC is the MVIO port** — powered from a separate **VDDIO2** pin. If VDDIO2 is not connected, **PORTC does not work.** The datasheet requires it to be treated as a full supply pair with its own decoupling.

**4. ⚠️ The ADC is on PORTD.** The Power Domain Overview (datasheet Figure 5-1, §5.1) shows **PD[7:0] → ADC**. PE[7:0] feeds the DAC / AC / OPAMP block; PF[1:0] goes to XOSC32K. So the analogue input must land on **PORTD**, not PORTF.

### Revised assignment (final)

| AVR port | Use | Notes |
|---|---|---|
| **PORTA[7:0]** | **VIAD0–7** | contiguous, bit order — whole-byte bus access |
| **PORTB[7:0]** | **handshake + control** | PMREQ, PMACK, PMINT, SYS_RST, RESET, PMGR_RESET, VIA_TEST, 1SEC. VDDIO domain — no MVIO dependency |
| **PORTG[7:0]** | power control outputs | written as a group |
| **PORTE[7:0]** | status inputs | AKD, STOP_CLK, CHRG_ON, KBD_RST, HICHG, RING_DETECT, MODEM_A/B |
| **PD0** | **A/D_FILTER** | **ADC input — PORTD is the ADC port.** Confirm the AIN channel number in the ADC chapter |
| PD1–PD7 | ADB, display, misc | PMGR_ADB, FDB, DISP_BLANK, MODEM_INS, SOUND_OFF, PMGR_PWM |
| PORTC | **spare** | MVIO port — usable, but requires VDDIO2 |
| PF[6:0] | mostly unused | PF[1:0] = XOSC32K, PF6 = RESET (input only) |
| PF7 | UPDI | not GPIO |

⚠️ Two earlier drafts of this table were wrong: the handshake was on PORTC (MVIO) and then on PORTD (the ADC port). **This version is the one to build from.**

**45 signals into 55 GPIO** — comfortable margin, and PORTC stays free as spare.

### Hardware requirements from §4 of the datasheet

- **Decoupling per supply pin pair:** 100 nF primary + 1–10 nF HF, optional 1 µF. Same side of the board as the MCU, traces as short as possible, capacitors first in the power chain.
- **All VDD pins are internally connected** and must all see the same voltage.
- **AVDD** is internally tied to VDD on this device but still needs its own decoupling.
- **VDDIO2** — tie to VDD (5V) and decouple it, even if PORTC is unused. The datasheet is explicit (§5.3): *"If the device is configured in single-supply mode, the VDDIO2 voltage must also rise closely to VDD."*
- **AVDD must ramp with VDD** (§5.3): *"The AVDD voltage must ramp up closely with the VDD voltage during power-up to ensure proper operation."* Tie them together at the board level.
- GND is common to VDD, AVDD and VDDIO2.
- **RESET** has an internal pull-up; an external one is not required. If you fit a reset switch, use 330 Ω in series with the switch and 100 nF to ground.
- ⚠️ **UPDI can be enabled via a high-voltage pulse on RESET** — so keep anything fragile off that pin.

### UPDI header

The datasheet recommends **UPDI Connection v1: a 2×3 100-mil header**, even though only three pins are used, because most programming tools ship with 2×3 connectors. On a 25–30 mm MCU board that fits easily — use it rather than bare pads.

(UPDI v2 adds RESET to the connection; v1 is fine for this.)

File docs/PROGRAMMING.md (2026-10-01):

# Programming the AVR

How to build the firmware, connect a programmer, and flash the AVR128DB64 on the MCU board — on the
bench, or later with the stack fitted in the Mac.

## What you need

- **A USB-serial adapter used as a "SerialUPDI" programmer.** UPDI is a one-wire serial protocol, so
  any USB-UART adapter works if its **TX and RX are joined through a resistor**. Use a **5 V-capable**
  adapter: the board runs at 5 V, and a 3.3 V-only adapter is marginal.
- **A resistor of 470 Ω to 1 kΩ** (1 kΩ is a good default). ⚠️ The widely copied 4.7 kΩ is too
  high. ⚠️ Adapters such as the Tigard have **no** built-in UPDI resistor — fit one.
- **`pymcuprog`** (Microchip's programming tool): `pip3 install pymcuprog`
- **avr-gcc 14** to build the firmware — see [`../firmware/README.md`](../firmware/README.md).

## The programming header, J2

`J2` is the 2 × 3 header on the MCU board:

```
  J2-1  UPDI      J2-2  +5 V      J2-3  DBG0
  J2-4  DBG1      J2-5  DBG2      J2-6  GND
```

⛔ **`J2-2` is the board's +5 V, and it connects through the stack to the Mac's +5 V always-on
rail.** So:

| situation | power the board from | connect |
|---|---|---|
| **MCU board on its own**, on the bench | the programmer | UPDI (J2-1), +5 V (J2-2), GND (J2-6) |
| **Stack fitted in the Mac** | **the Mac** (bench supply or battery at the battery input) | **UPDI (J2-1) and GND (J2-6) only — leave J2-2 off** |

Never let the programmer try to power the Mac's always-on rail through `J2`.

## Wiring the adapter

```
  adapter TX ──[ 1 kΩ ]──┬── J2-1  UPDI
  adapter RX ────────────┘
  adapter GND ───────────── J2-6  GND
  adapter 5 V ───────────── J2-2  +5 V      (bench only — see the table above)
```

⚠️ **On a dual-port adapter (FT2232-based, e.g. the Tigard), use the FIRST port.** It appears as
two serial ports; only the first (channel A) answers. The second reports "UPDI initialisation failed".

## Step by step

**1. Build.**
```bash
make -C firmware
```

**2. Read the device ID first — before writing anything.**
```bash
pymcuprog ping -t uart -u /dev/tty.usbserial-XXXX -d avr128db64
```
It must answer **`1E970B`**. That one reply proves the chip is alive, is the right part, and that
UPDI, power and ground are all connected. If it fails here, nothing has been written yet.

**3. Fuses — once per board, before the first flash.**
```bash
make -C firmware fuses PORT=/dev/tty.usbserial-XXXX
```
See [`../firmware/FUSES.md`](../firmware/FUSES.md) for what is set and why.

**4. Flash.** Use the flash tool, so the board's calibration record is written at the same time:
```bash
export PMGR_UPDI_PORT=/dev/tty.usbserial-XXXX
python3 tools/pmgr_flash_with_pram.py firmware/pmgr.hex <md5-prefix> - calib.args
```
- `<md5-prefix>` is the first 8 characters of `md5 -q firmware/pmgr.hex` (on Linux: `md5sum`). The
  tool **refuses** a hex whose checksum doesn't match, so you can't flash the wrong file.
- `-` means "write no PRAM image"; the Mac initialises PRAM itself.
- `calib.args` is the board's calibration record — see [`BUILD.md`](BUILD.md) §7. On a brand-new
  board without one yet, leave the last argument off; the firmware then simply won't fast-charge.
- ⭐ **The tool checks every input file before it erases anything** — the record's length, checksum
  and values. A missing or bad file stops it with "NOTHING HAS BEEN FLASHED", so the board keeps its
  existing record.
- Look for **`write: OK | verify: matches`** and **`calibration record at 464 read back identical:
  True`**.

`make -C firmware flash PORT=…` also works, but it **does not** write the calibration record.
⛔ **Every flash erases the EEPROM**, so flashing that way leaves the board without its record.

**5. Unplug the programmer and do a real power cycle.** Disconnect the supply or battery, wait a
few seconds, reconnect. ⛔ Do this after **any** programmer operation — even step 2's ID read. Without
it, a machine that is shut down may not wake from the keyboard (seen 7 times out of 7; cause not
established). A programmer left plugged in back-feeds the board, so switching off alone is not
enough.

## Resetting PRAM

**Pulling the battery does not reset PRAM on this board** — PRAM is kept in the AVR's EEPROM and
survives power removal. Try `Cmd-Opt-P-R` at startup first. If PRAM holds settings that stop the
Mac booting at all, **re-flash through the flash tool** (step 4), with the same `calib.args`:

- every flash **erases the whole EEPROM**, which clears PRAM, and the Mac writes fresh defaults on
  the next start;
- the tool then **writes the calibration record back**.

⛔ **Don't erase the EEPROM any other way.** The calibration record lives there too (bytes 464–479),
and losing it silently disables fast charge. Then unplug the programmer and power-cycle, as always.

## Troubleshooting

| symptom | likely cause |
|---|---|
| `UPDI initialisation failed` | **The board isn't powered.** A connected programmer back-feeds only about 1.65 V, below the AVR's 2.85 V brown-out, so it can't be programmed that way. Power it properly. |
| `UPDI initialisation failed`, board powered | Wrong port on a dual-port adapter (use the first); TX/RX not joined through the resistor; UPDI not reaching `J2-1`. |
| Ping answers, but not `1E970B` | Wrong part fitted. |
| The flash tool refuses the file | The MD5 prefix doesn't match the hex — rebuild, or check you're flashing the file you meant. |
| Boots normally but never fast-charges | No valid calibration record — flash again through the tool with `calib.args`. |
| Machine won't wake from the keyboard after flashing | No real power cycle yet — unplug the programmer and disconnect power. |
| Bad settings survive pulling the battery | Expected — PRAM is kept in EEPROM. See "Resetting PRAM" above. |

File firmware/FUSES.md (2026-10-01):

# Fuse policy — the configuration `pmgr.hex` assumes

> ⛔⛔ **Written 2026-09-07 after review. Nothing here has been programmed yet.**
> `make flash` writes the flash image and **nothing else**, so every board built
> before this document runs on **factory fuse defaults** — which are wrong for
> this design in at least one way that would be hard to diagnose.

⭐ **All values below are taken from the device header shipped with the
toolchain** (`avr/ioavr128db64.h`, avr-gcc 14.3.0), not from memory — the enum
names and shifts are quoted so any reader can re-derive the bytes.

---

## ⛔⛔⛔ `SYSCFG0` WAS `0x08` AND WOULD HAVE BRICKED THE BOARD

> ⛔ **Caught by review 2026-09-07, before any hardware existed to suffer it.**
> The first version of this document specified `SYSCFG0 = 0x08`.

```
  CRCSRC is bits [7:6]      CRCSRC_NOCRC_gc = (0x03<<6) = 0xC0
  so leaving them ZERO   =  CRCSRC_FLASH_gc = CRC over the ENTIRE flash,
                            checked at every reset
```

⛔⛔ **`pmgr.hex` carries no such checksum.** The CRCSCAN would fail and the part
would be held before it ever reached `main()`. ⚠️ **The board would have looked
completely dead** — and on a first article the first suspect is a `DF12` joint or
`U1` alignment, so this would have cost a rework of a perfectly good board.

### ⭐⭐ Root cause, which matters more than the fix

Each byte was composed **from the bits being set**, leaving every other field at
zero on the assumption that zero is the neutral value. ⛔ For `CRCSRC`, zero is
the **enabled** value.

⭐⭐⭐ **The factory default is `0xC0`, which already selects `CRCSRC_NOCRC`.**
This project deliberately changes **only `RSTPINCFG`**, producing **`0xC8`**.

```
  0xC0   factory default   CRCSRC = NOCRC, reset pin = GPIO, EESAVE clear
  0xC8   ours              the same, plus RSTPINCFG = RST
  0x08   what was written  ⛔ CRCSRC CLEARED to 00 = CRC on full flash
```

⛔⛔ **So the defect was writing a byte that silently *undid* a safe default.**
Leaving the fuse completely alone would have booted; the hand-composed
"deliberate" value would not. ⚠️ This document argues that a fuse left at its
default is an unmade decision — still true — and the correction is that a
hand-composed value which clears an unrelated field is worse than either.

> ⛔ **The rule that follows: start from the factory default and change only the
> fields you intend.**

⭐ **`RSTPINCFG = RST` is a real choice, not a leftover.** `PF6` is reserved as
`RESET` on this board and is **not used as a GPIO** — `MCU-BOARD-SCHEMATIC.md`:31
lists it as *"RESET, input only"*. The default would leave it a floating input
pin with no reset function.

⚠️ **This section said the default was `0xC8` until 2026-09-07.** The conclusion
was right and the number was wrong — which is its own small lesson, since the
number was the part that could have been checked and was not. ⭐ The datasheet
states it directly (DS40002247, the `SYSCFG0` fuse table: default `0xC0`), along
with the failure mode: *"Normal code execution does not start. The CPU will hang
executing no code."*

### ✅ The other four were audited when this was found

| fuse | is zero neutral for every unset field? |
|---|---|
| `WDTCFG` | ✅ `PERIOD`/`WINDOW` are both `OFF` at 0 |
| `BODCFG` | ✅ default `SAMPFREQ` (128 Hz) is 0, intended; `SLEEP` is set explicitly (`SAMPLED`, since 2026-09-14) |
| `SYSCFG1` | ✅ only `MVSYSCFG` and `SUT`; both explicitly set |
| `CODESIZE`/`BOOTSIZE` | ✅ 0 means no boot/app split |

⭐⭐ **And the arithmetic is now executed, not trusted.** `tools/check_docs.py`
`check_fuses()` names **every field of every fuse** and recomputes each byte; a
value that does not equal the OR of its named fields fails the build, and so does
a `FUSES.md` that disagrees with the Makefile. ⛔ That check exists because this
defect was arithmetic done in prose.

---

## ⛔⛔ THE ONE THAT WOULD ACTUALLY BITE IN THE FIELD: `MVSYSCFG`

```
  MVSYSCFG_DUAL_gc   = (0x01<<3)     <- FACTORY DEFAULT
  MVSYSCFG_SINGLE_gc = (0x02<<3)     <- what this board is
```

⭐ **This board is single-supply.** `MCU-BOARD-SCHEMATIC.md`:187 already says so
and ties `VDDIO2` (pin 20) to +5 V with its own decoupling pair. ⛔ **The
hardware was done right and the fuse was never chosen** — it is still at the
factory `DUAL` value, which tells the MVIO block to treat `VDDIO2` as an
independent supply with its own detection.

⛔⛔ **`PORTC` is not spare on this board.** It carries four real signals:

| pin | signal | why it matters |
|---|---|---|
| **PC2** | ⛔⛔ **`SIXTYHZ`** | **the 60 Hz tick** — the heartbeat behind `pmgr_tick_1s()`, the battery logic, and the two-edge wait in `pmgr_system_release()` |
| **PC4** | `PMGCLK_F` | the host clock input |
| PC0 | `SOUND_LATCH` | |
| PC1 | `OFF_HOOK*` | |

⚠️⚠️ **The failure mode is "boots but subtly wrong", which is the worst kind.**
The firmware has a *nominal-period fallback if `SIXTYHZ` is absent*, so a
`PORTC` problem does not stop the machine — it silently degrades the timebase,
and the 1 Hz tick that drives all battery behaviour goes with it. ⛔ No amount of
solder inspection finds a fuse.

⭐ **Set it deliberately.** Even if `DUAL` happens to work with `VDDIO2` tied to
`VDD`, leaving a supply-topology fuse at a value that contradicts the schematic
is an unmade decision on the port carrying the heartbeat.

---

## The full policy

| fuse | offset | value | why |
|---|---|---|---|
| `WDTCFG` | `0x00` | **`0x00`** | ⛔ **watchdog OFF, deliberately** — see below |
| `BODCFG` | `0x01` | **`0x66`** | BOD on at **2.85 V while active**, and **sampled (128 Hz) in sleep** - the park sleeps since 2026-09-14 (MEASUREMENTS 2.199). ⛔ Was `0x64` (disabled in sleep) until then |
| `OSCCFG` | `0x02` | *leave* | the design runs from the internal high-frequency oscillator configured in software; no fuse dependency |
| `SYSCFG0` | `0x05` | **`0xC8`** | ⛔⛔ **`CRCSRC = NOCRC`** (the `0xC0`), reset pin = `RST`, ⭐ `EESAVE` **clear** on purpose |
| `SYSCFG1` | `0x06` | **`0x14`** | ⛔ **`MVSYSCFG = SINGLE`** + **8 ms startup** |
| `CODESIZE` | `0x07` | **`0x00`** | no boot/app split; single application section |
| `BOOTSIZE` | `0x08` | **`0x00`** | same |

### How each byte is built

```
  BODCFG  0x66 = LVL_BODLEVEL3_gc (0x03<<5 = 0x60)   2.85 V
               | ACTIVE_ENABLE_gc  (0x01<<2 = 0x04)   continuous while running
               | SLEEP_SAMPLED_gc  (0x02<<0 = 0x02)   sampled while the park sleeps - see the note below

  SYSCFG0 0xC8 = CRCSRC_NOCRC_gc   (0x03<<6 = 0xC0)  ⛔⛔ NO startup CRC scan
               | RSTPINCFG_RST_gc  (0x02<<2 = 0x08)   PF6 is RESET, not GPIO
               | CRCSEL            (bit 5)            don't-care once NOCRC
               | EESAVE clear      (bit 0 = 0)        chip erase WIPES EEPROM

  SYSCFG1 0x14 = MVSYSCFG_SINGLE_gc (0x02<<3 = 0x10)  single supply
               | SUT_8MS_gc        (0x04<<0 = 0x04)   8 ms startup delay
```

---

## ⛔ Watchdog: OFF, and this is a decision, not a default

⭐⭐ **A watchdog reset turns the Macintosh off.** `SYS_PWR*` is released on
reset, so a WDT firing while the machine is running and healthy is
indistinguishable to the user from the power switch being pulled.

⚠️ And the firmware's parked loop is **an intentional busy loop polling 60 Hz
edges**, so a watchdog would have to be petted from inside it — meaning any
legitimate long operation risks a reset that costs the user their session.

⛔ **The trade is bad in this application.** A hung PMGR leaves a machine that
will not respond; a spurious WDT reset powers off a machine mid-use. ⭐ Revisit
only with a specific hang in evidence, and then with the pet points chosen
against a captured trace, not by inspection.

## ⭐⭐ Brownout: ON — and here is why it is NOT the same trade as the watchdog

⚠️ The obvious objection is that a BOD reset also turns the machine off. ⭐ **It
does not, in the case that matters**, and the distinction is clean:

```
  WATCHDOG fires   while VDD is perfectly healthy   -> causes a shutdown that
                                                       would NOT have happened
  BOD fires        only when VDD < 2.85 V           -> the machine's own 5 V
                                                       rail has already failed
```

⭐⭐⭐ **At 2.85 V the Macintosh is going off regardless.** What BOD buys is that
the AVR stops executing rather than running undefined code while driving
`SYS_PWR*`, the rail-enable lines and `PMGR_ADB` — outputs that reach transistor
bases directly (2.58). ⛔ **Undefined execution on a collapsing rail is the one
state where this chip can do something the original never would.**

⚠️ **What BOD does NOT buy, stated so nobody over-reads it:** 24 MHz operation
requires **VDD ≥ 4.5 V**. A BOD at 2.85 V is far below that, so there is a band
between 2.85 V and 4.5 V where the part is out of spec and BOD is silent. ⛔ BOD
is protection against *collapse*, not a guarantee of valid operation.

✅ **REVISITED 2026-09-14 (MEASUREMENTS 2.199):** the park now sleeps in POWER-DOWN between 60 Hz ticks, so `BODCFG` is
`0x66` - `SLEEP_SAMPLED`. Written and verified on Portable #1's board the same day (was `0x64`); the text below is the original
reasoning, kept. ⚠️ A board still carrying `0x64` runs the sleeping park with no brownout detection while parked - reprogram the fuse.

~~⭐ `SLEEP_DISABLE` is chosen because **the firmware does not yet sleep**~~ — the
parked loop ran at full speed. ⛔⛔ **This is the fuse to revisit the moment real
sleep lands** (see the parked-current stage in `BRING-UP.md`): with a genuine
Power-Down mode, `SLEEP_SAMPLE_gc` (`0x02`) trades a little current for keeping
brownout coverage while parked, and leaving `DISABLE` there would remove
protection during the state the PMGR spends most of its life in.

## ⭐ Startup delay: 8 ms, and it is board-specific

⛔ Factory default is `SUT_0MS`. ⭐ At power-on this AVR starts driving the
Macintosh's control lines as soon as it executes, and `pmgr_handlers_init()`
establishes rail states immediately. **8 ms gives the +5 V always-on rail time to
settle before the PMGR begins asserting anything into the machine.**

⚠️ Not a large number and not a magic one — it is one oscillator-settling
multiple above the smallest useful value. ⛔ **If first power-on shows anything
odd in the first instants, this is a knob**, and a captured `SYS_PWR*` trace
should set it rather than taste.

## ⭐ `EESAVE`: clear, on purpose

⚠️ Clearing it means **a chip erase takes EEPROM with it**, so `make flash`
wipes PRAM. ⭐ That is deliberate and already reasoned in `ROADMAP-V2.md`:
because our PRAM lives in EEPROM rather than volatile RAM, **"reflash the
firmware" is the PRAM-zap of last resort** — the replacement for pulling the
battery, which no longer clears anything.

⛔ Setting `EESAVE` would preserve settings across a firmware update and
**remove the only recovery path** from a PRAM state that prevents booting. The
two cannot both be true; this is the side chosen.

---

## Programming, with verification

⛔⛔ **Write-then-verify, never write-and-assume.** A fuse that did not take is
silent, and every consequence above is a silent one.

### ⛔⛔ IF YOU PROGRAM WITH THE XGecu / Xgpro INSTEAD, EVERY GUARD HERE IS BYPASSED

⭐ The `T48` is a legitimate second path and is the **known-good** programmer of
the two — worth having when a Tigard-as-UPDI rig is improvised. ⚠️ But it does not
go through `make fuses`, and therefore not through **any** of the protection this
project built:

| guard | protects the Makefile path | protects Xgpro |
|---|---|---|
| `check_docs.py` `check_fuses()` — recomputes every byte from named fields | ✅ | ⛔ **no** |
| `make fuses` write-then-**verify** with a non-zero exit | ✅ | ⛔ **no** |
| `FUSES.md` and the Makefile forced to agree | ✅ | ⛔ **no** |

⛔⛔ **AND THE P0 LIVES IN A FUSE FIELD A GUI WILL PRESENT AS A DROPDOWN.**
`SYSCFG0`'s `CRCSRC` must be **`NOCRC`**. Left at the value a tool happens to
default to, it selects **CRC over the entire flash**, `pmgr.hex` carries no such
checksum, and the part **hangs before `main()`** — a board that looks completely
dead while every joint is perfect.

⭐⭐ **So if you set fuses in Xgpro, read back the raw bytes and compare them to
this table by eye**, whatever the GUI calls the fields:

```
  WDTCFG   0x00        SYSCFG0  0xC8      <- the 0xC0 is CRCSRC=NOCRC. NOT optional.
  BODCFG   0x66        SYSCFG1  0x14
  CODESIZE 0x00        BOOTSIZE 0x00
```

⚠️ A GUI that shows "CRC: enabled/disabled" is doing the same arithmetic this
document does — but nothing checks that your reading of it matches.

### First, the tool

```bash
pip3 install --user pymcuprog
```

⚠️ **pip installs the script somewhere that is usually NOT on `PATH`** — on this
Mac, `~/Library/Python/3.11/bin` — and says so in a warning most people scroll
past. ⭐ `make fuses` and `make flash` both check for it first and print the fix,
because a bare *"command not found"* reads like a broken Makefile.

```bash
pymcuprog --version        # confirm before you need it
```

### Then

```bash
make -C firmware fuses PORT=/dev/tty.wchusbserial-XXXX
make -C firmware flash PORT=/dev/tty.wchusbserial-XXXX
```

⭐ `fuses` writes each value, then verifies **each one against the device** and
fails loudly on any mismatch, then prints all nine fuse bytes for the record.
Run it **once per board, before `make flash`**, and paste the output into that
board's bring-up notes.

⚠️ **Order matters:** fuses first, then flash. `make flash` performs a chip erase,
which does not clear fuses — but doing fuses first means the very first code the
part ever runs is running under the intended configuration.

### ⛔ How the verification works, and one way it was already wrong

⭐⭐ Verification uses **`pymcuprog verify -l`**, which reads the device and
compares in-tool — `utils.compare()` raises on mismatch and the process exits
non-zero. ⛔ **No output parsing is involved, deliberately.**

⚠️ **The first version of this target parsed `pymcuprog read` output and was
broken.** `showdata()` prints:

```
  0x001280: xx 64 xx xx xx xx ...
```

⛔ The **address** carries the `0x` prefix; the **data byte does not**. A regex
looking for `0x` followed by two hex digits matches `0x00` out of the *address*,
so every fuse would have reported a mismatch — a verify step that always fails is
as useless as one that always passes. ⭐ Found 2026-09-07 by rendering
`showdata()` directly, since there is no hardware here to run it against.

---

## ⛔ What has and has not been executed

| | |
|---|---|
| `pymcuprog` installed, runs, version reported | ✅ 3.19.4.61 |
| `-m fuses`, `-o`, `-l`, `-b` are real flags | ✅ checked against its own `--help` |
| non-zero exit on failure, so `\|\| exit 1` works | ✅ verified |
| `verify -l` raises on a wrong value | ✅ verified against `utils.compare()` |
| the target aborts on a failed write | ✅ verified with an absent device |
| both guard paths (no tool, no adapter) | ✅ verified |
| ⛔ **the happy path, against a real AVR** | ⛔⛔ **NEVER RUN — there is no hardware yet** |

⚠️ **Treat the first real `make fuses` as part of bring-up, not as a tested
step.** Everything above is verified as far as it can be without a chip on the
end of the wire, and no further.

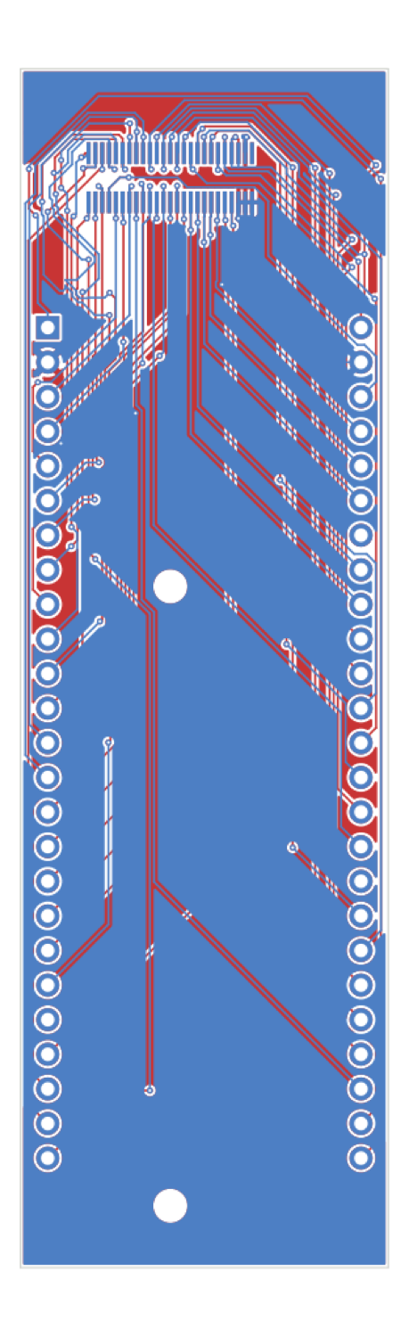
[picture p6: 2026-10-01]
hardware/breakout-j21/copper-preview.png

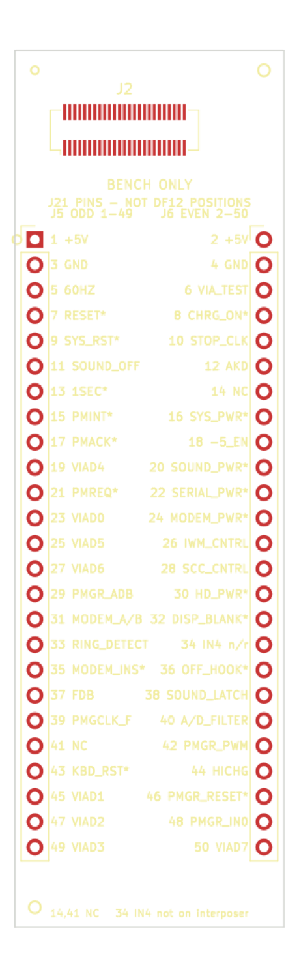
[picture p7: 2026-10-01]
hardware/breakout-j21/silk-preview.png

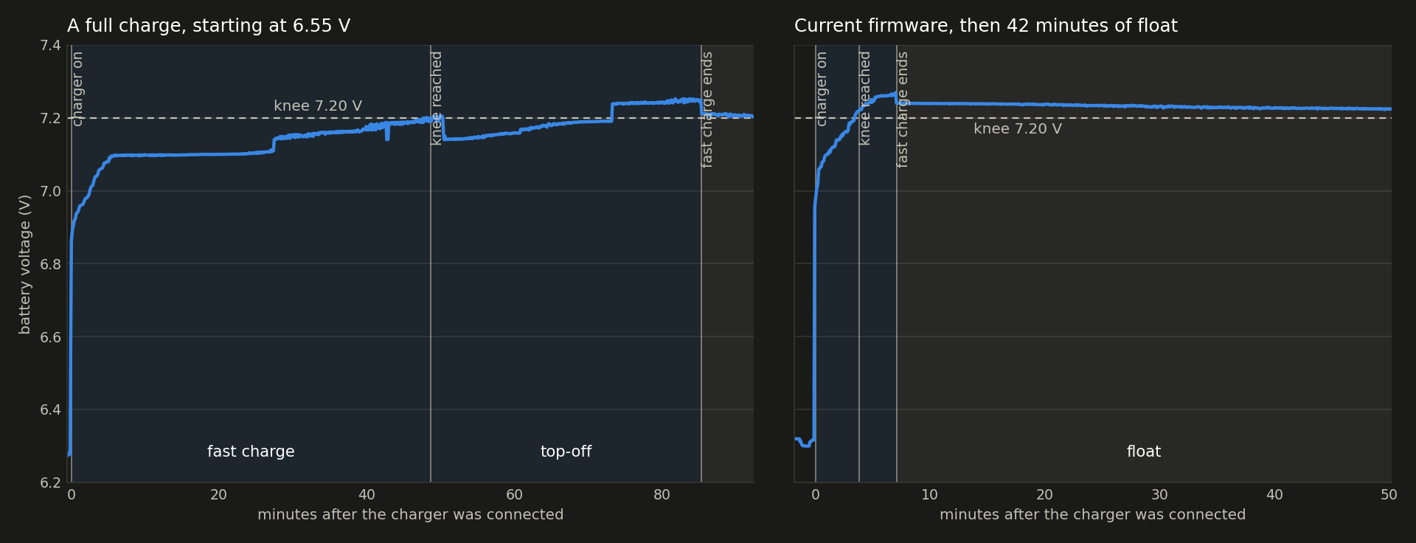
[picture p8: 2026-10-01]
images/charge-curve-dark.png

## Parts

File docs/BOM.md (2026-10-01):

# PMGR Recreation — Bill of Materials

Generated from the board files, not from the design docs — `pmgr_mcu.kicad_pcb`, `pmgr_breakout.kicad_pcb`, `pmgr_interposer_v2.kicad_pcb`. Reference designators, packages and side-of-board are what will actually be fabricated.

Quantities are **per board** and **for 3 assemblies** (PowerBook 100 bring-up, Portable, spare).

---

## Board 1 — MCU board (`pmgr_mcu`)

4 layer · 1.6 mm · ENIG · 20.0 × 23.5 mm · two-sided assembly

| Ref | Value | Package | Side | Qty/bd | Qty ×3 | Note |
|---|---|---|---|---|---|---|
| U1 | AVR128DB64-I/PT | TQFP-64 10×10 P0.5 | Top | 1 | **4** | DigiKey 12807611. Order a spare — awkward to rework. |
| J1 | **DF12NC(3.0)-50DS-0.5V(51)** | Hirose DF12N 50-pos | **Bottom** | 1 | **3** | Socket. Mates the interposer header. Original DF12C is obsolete — see Connectors below. |
| J2 | 2×3 header 2.54 mm THT | PinHeader_2x03 | Top | 1 | **3** | UPDI + DBG0/1/2. **Trim pins after soldering.** |
| D1 | BAT54S | SOT-23 | **Bottom** | 1 | **3** | Dual Schottky, ADC clamp. |
| R1 | 1 kΩ | 0402 | **Bottom** | 1 | 3 | |
| C1, C2, C3 | 100 nF X7R | 0402 | Top | 3 | 9 | Decoupling |
| C4 | 100 nF X7R | 0402 | **Bottom** | 1 | 3 | Decoupling |
| C5, C6, C7 | 10 nF X7R | 0402 | Top | 3 | 9 | Decoupling |
| C9 | 10 nF X7R | 0402 | **Bottom** | 1 | 3 | Added after the pin audit found pins 56/57 unconnected |
| C8 | 10 µF X5R | 0805 | Top | 1 | 3 | Bulk |

**14 placements per board, 5 of them on the bottom side** — the board needs a two-sided stencil and two reflow passes, or bottom-side hand work. C4, C9, D1, R1 and the DF12 socket are all underneath.

**Four decoupling pairs, not three.** The AVR128DB64 has two VDD/GND pairs (6/7 and 56/57) plus AVDD and VDDIO2 — four supply pins.

---

## Board 2 — Interposer (`pmgr_interposer_v2`)

4 layer · 1.6 mm · ENIG · 16.3 × 16.3 mm · **castellated plating on all 60 half-holes**

| Ref | Value | Package | Side | Qty/bd | Qty ×3 | Note |
|---|---|---|---|---|---|---|
| J1 | **DF12NC(3.0)-50DP-0.5V(51)** | Hirose DF12N 50-pos | Top | 1 | **3** | Header. Mates the MCU board socket. |
| U1 | — (land pattern only) | PMGR_Castellation_60 | Top | 0 | 0 | Not a part. The 60 castellations that solder to the Portable's PMGR pads. |

> ℹ️ **Reference designator fixed 2026-08-26.** It was `PMGR Chip` (invalid — contains a space) and is now `J1`. The change was made AFTER the boards were ordered, so **boards from this run are silkscreened `PMGR Chip`**; a future run will read `J1`. Nothing electrical differs. The as-fabricated files are frozen in `interposer-v2/as-built-2026-08-26/`.

Only **one part** is placed on the interposer. Everything else about it is copper.

---

## Board 3 — Debug breakout (`pmgr_breakout`) — bench tool, optional

**2 layer** · 1.6 mm · **HASL** · 27 × 40 mm

> ⭐ **Order this one HASL, not ENIG.** The 2026-08-27 order specified ENIG and
> paid **$42.41** instead of **$5.00** — specifying it dropped the board out of
> PCBWay's $5-for-5 promotional tier. Nothing on this board needs ENIG: no
> fine-pitch parts, only through-hole 1.27 mm headers. See `ORDER-LIST.md`.

| Ref | Value | Package | Side | Qty/bd | Qty ×1 | Note |
|---|---|---|---|---|---|---|
| J1 | **DF12NC(3.0)-50DS-0.5V(51)** | Hirose DF12N 50-pos | **Bottom** | 1 | **1** | Socket — receives the interposer |
| J2 | **DF12NC(3.0)-50DP-0.5V(51)** | Hirose DF12N 50-pos | Top | 1 | **1** | Header — receives the MCU board |
| J3 | **FTS-113-01-L-D** | 2×13 1.27 mm **THT** | Top | 1 | **1** | Signals at positions 1–26 |
| J4 | **FTS-113-01-L-D** | 2×13 1.27 mm **THT** | Top | 1 | **1** | Signals at positions 27–50 (24 used, 2 spare) |
| H1 | 2.2 mm mounting hole | — | — | 1 | — | Not a part |

Build **one**. It comes out before the machine is closed.

---

## Consolidated order

### Semiconductors
| Qty | Part | Package |
|---|---|---|
| 4 | AVR128DB64-I/PT | 64-TQFP |
| 3 | BAT54S | SOT-23 |

### Connectors — order the mated pair together
| Qty | Part | Goes on |
|---|---|---|
| **4-5** | Hirose **DF12NC(3.0)-50DP-0.5V(51)** — header | Interposer ×3, breakout ×1 |
| **4-5** | Hirose **DF12NC(3.0)-50DS-0.5V(51)** — socket | MCU board ×3, breakout ×1 |
| 3-5 | **PRPC003DAAN-RC** 2×3, 2.54 mm THT (DK `35-PRPC003DAAN-RC-ND`) | MCU board J2 |
| 2 | **FTS-113-01-L-D** 2×13, 1.27 mm THT (Mouser `200-FTS11301LD`) | Breakout J3, J4 |
| — | 1.27 mm → 0.1″ IDC cables | Logic analyser |

> ⚠️ **Stack height must match on both halves, and must be (3.0).** The land pattern is identical across 3.0/3.5/4.0/5.0, so a wrong-height part solders down perfectly and silently fails to mate. **Mate one socket to one header by hand before reflowing anything** — while they are still two loose parts.

### Passives — buy in 100s, they cost nothing
| Qty | Value | Package |
|---|---|---|
| 12 | 100 nF X7R | 0402 |
| 12 | 10 nF X7R | 0402 |
| 3 | 10 µF X5R | 0805 |
| 3 | 1 kΩ | 0402 |

### Not a part, but required before first fit
**Kapton tape**, cut to the interposer outline — the third mitigation against shorting to the logic board, and the only one not solved in the PCB itself. The Portable's U15H footprint has live traces and vias inside it.

### Programming
One of: USB-serial adapter + 4.7 kΩ (cheapest, `Makefile` flash target already uses `pymcuprog`), MPLAB SNAP, or Atmel-ICE.

> ⚠️ Confirm your programmer's UPDI pin position against J2: **pin 1 = UPDI, pin 2 = +5 V, pin 6 = GND.** Pins 2 and 6 are standard; tools differ on UPDI — some expect pin 5.

---

## ⚠️ Connectors — RESOLVED 2026-08-26, do not re-derive

The original Hirose parts are **obsolete**. Ordering these three, and only these three:

| Role | Part | Distributor | Qty |
|---|---|---|---|
| Socket — MCU ×3, breakout J1 | **DF12NC(3.0)-50DS-0.5V(51)** | Mouser | 4-5 |
| Header — interposer ×3, breakout J2 | **DF12NC(3.0)-50DP-0.5V(51)** | Mouser | 4-5 |
| Breakout J3, J4 | **FTS-113-01-L-D** (Mouser 200-FTS11301LD) | Mouser | 2 |

### Why DF12**NC** and not DF12**NB**

`DF12C(3.0)-50DS-0.5V(81)` and `DF12E(3.0)-50DP-0.5V(81)` both went obsolete. General sources name **DF12NB** as the DF12 successor. **That is wrong for these boards.**

- **NB = *with* metal fitting** — its recommended pattern adds two lands (`0.8`, `1.8`). Our footprint has 50 copper pads and nothing else, so the fitting legs would land on bare soldermask.
- **NC = *without* metal fitting** — matches exactly. The obsolete parts were specified "W/O BOS,**FIT**" (without boss, without fitting), so NC is the true equivalent.

Verified against the DF12N catalog's *Recommended PCB mounting pattern*, "without metal fitting" variant:

| | Board (from `pmgr_mcu.kicad_pcb`) | DF12N w/o fitting |
|---|---|---|
| Pitch | 0.50 mm | 0.5 ±0.02 |
| Pad size | 0.30 × 1.60 mm | 0.3 ±0.02 × 1.6 ±0.02 |
| Row spacing | 3.60 mm | 2 + 1.6 = 3.6 |
| Span | 12.00 mm | B = 12.0 |
| Extra lands | none | none |

Keep **(3.0)** stack height — every clearance figure in `CLEARANCE-MEASUREMENTS.md` assumes it. 4.0 mm would also fit vertically (and improves VIA clearance from 0.5 to 1.5 mm) but invalidates the measured numbers.

### Why FTS-113-01-**L-D**

J3/J4 are **through-hole** (0.65 mm drills; the 113 PTH holes in the drill file are 61 vias + 26 + 26). Two wrong turns worth recording:

- **FTSH series is SMT-only** — its catalog is titled *Surface Mount Micro Header*. `-DV`/`-DH`/`-MT` are tail *orientations*, not mounting types.
- **In FTS, the Row Option decides mounting**: `-D` = Double **Through-hole**, `-DV` = Double Vertical **SMT**. `-P` (Pick & Place Pad) is an SMT-assembly option and indicates a surface-mount part.

Lead style matters too: **-01 = 3.05 mm post, mates FFSD** (the 1.27 mm IDC ribbon socket a logic analyser uses). `-03` = 1.65 mm mates CLP, a board-mounted socket strip — too short to hold a cable.

> Confirm your analyser's cable is an FFSD-style IDC socket. If it uses flying leads with micro-clips, post length is irrelevant and `-03` would do.

---

## Actual spend — PAID 2026-08-27

Not an estimate. What it cost.

| | |
|---|---|
| Boards (5 pcs each, 3 designs, ENIG 1U) | $175.91 |
| Freight | $6.04 |
| Bank handling | $10.97 |
| **Duty & tax** | **$48.38** |
| **PCBWay total** (order YH1796480) | **$241.30** |
| Parts — Mouser, 9 lines | $84.39 |
| **PROJECT TOTAL** | **$325.69** |

### Why the original "$80-150" estimate was wrong

It counted board and part prices only. Three things it missed:

1. **Duty & tax ~25%** — $48.38. The single largest omission.
2. **Bank handling fee** — $10.97 on an international order.
3. **ENIG** — the finish was originally quoted HASL. Correcting it added ~$94 to the
   products line. The breakout jumped 8x ($5.00 to $42.41) not because ENIG is expensive
   on 2 layers, but because specifying it dropped the board out of PCBWay's $5-for-5
   promotional tier.

**For future boards: budget roughly 2x the raw board+parts figure** once ENIG, duty,
freight and bank fees are included.

### What the money bought

5 pcs of each board rather than 3 — enough for the Portable, the PowerBook 100, a spare,
and two assembly failures without re-ordering. Worth having, given a hand-placed 0.5 mm
pitch TQFP-64 is the hardest step in the build.

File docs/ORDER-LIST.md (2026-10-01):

# PMGR Recreation — What To Order

Everything needed to build the PMGR replacement — two boards for the machine, plus an optional bench breakout. Quantities assume **3 assemblies** (one for the PowerBook 100 bring-up, one for the Portable, one spare).

---

## 1. PCBs — PCBWay

| Board | Spec | File |
|---|---|---|
| **Interposer** | 4 layer · 1.6 mm · ENIG · 16.3 × 16.3 mm · **castellated plating on all 60 half-holes** | `interposer-v2/pmgr_interposer_v2_gerbers.zip` |
| **MCU board** | 4 layer · 1.6 mm · ENIG · 20.0 × 23.5 mm · two-sided stencil | `mcu-board/pmgr_mcu_gerbers.zip` |
| **Debug breakout** | **2 layer** · 1.6 mm · **HASL** · 27 × 40 mm · two-sided stencil | `breakout/pmgr_breakout_gerbers.zip` |

The breakout is a **bench tool** — it sits between the interposer and the MCU board so a logic analyser can reach all 50 signals, and comes out before the machine is closed. Optional, but it is the only way to see the bus.

Minimum order is usually 5 of each.

### ⭐ Do not copy this order verbatim — ENIG only matters on two of the three

**The breakout above is specified HASL, and the 2026-08-27 order got this wrong.**
Ordering it in ENIG cost **$42.41** instead of **$5.00** — an 8× jump, and not
because ENIG is expensive on a 2-layer board. Specifying it simply dropped the
board out of PCBWay's $5-for-5 promotional tier.

| Choice | Boards line |
|---|---|
| All three ENIG (what was actually paid) | $175.91 |
| **Breakout in HASL** | **~$138.50** |
| Breakout omitted entirely | ~$133.50 |

⭐ **So the breakout costs about $5 if you order it in HASL — omitting it saves
almost nothing.** Order it. It has no fine-pitch parts, only through-hole
1.27 mm headers, and no long-term contact-reliability requirement, so ENIG buys
it nothing.

⛔ **ENIG is NOT optional on the interposer.** 0.40 mm castellated half-holes at
the fab's stated minimum, alongside a 0.5 mm-pitch TQFP-64 pad ring, is exactly
what ENIG exists for. This is the one board in the set with no process margin.

**Building just one set?** You still pay for 5 of each — the minimum dominates,
the marginal board is nearly free. Budget **~$140–150 of boards**, before
freight and duty. Duty is jurisdictional (it was ~25%, $48.38, on this order)
and is the single largest cost nobody estimates.

### ⚠️ Two questions to send with the interposer

1. **The 0.40 mm castellated hole sits exactly at PCBWay's stated minimum** — no margin. Most likely thing to come back as an engineering query.
2. **How do they want traces approaching castellation pads handled?** Three were rerouted perpendicular to satisfy edge clearance; worth confirming that matches their preference.

The MCU board needs no such conversation — nothing on it is near a process limit.

---

## 2. Semiconductors

| Qty | Part | Package | Note |
|---|---|---|---|
| **4** | **AVR128DB64-I/PT** | 64-TQFP 10×10 | DigiKey **12807611**. 1.8–5.5 V native, so no level shifters. |
| **3** | **BAT54S** | SOT-23 | Dual Schottky, ADC clamp. Any manufacturer. |

Order a spare AVR — it is the one part that is awkward to rework off a 0.5 mm TQFP if a joint goes bad.

---

## 3. Connectors — the mated pair

**These must be ordered together and they are not interchangeable.**

| Qty | Part | Goes on |
|---|---|---|
| **4** | **Hirose DF12E(3.0)-50DP-0.5V(81)** — header | **Interposer** top face ×3, **breakout** top face ×1 |
| **4** | **Hirose DF12C(3.0)-50DS-0.5V(81)** — socket | **MCU board** bottom ×3, **breakout** bottom ×1 |

The breakout needs one of each — a socket underneath to mate the interposer, a header on top to receive the MCU board.

3.0 mm mated stack height. Both footprints came from KiCad's stock library and the land pattern was verified against Hirose datasheet A306.

⚠️ **Verify the pair physically mates before assembling anything.** The `(81)` suffix is the variant KiCad's footprint cites; confirm the distributor's suffix matches on both halves.

| Qty | Part | Note |
|---|---|---|
| **3** | 2×3 pin header, 2.54 mm, through-hole | UPDI + 3 debug outputs. **Trim the pins after soldering** — 1.6 mm clearance untrimmed vs 3.6 mm trimmed. |
| **2** | 2×13 pin header, **1.27 mm**, through-hole | Breakout debug headers (positions 1–26 and 27–50) |
| — | 1.27 mm → 0.1″ IDC cables | for the analyser |

---

## 4. Passives — MCU board

Per board; buy in 10s or 100s, they cost nothing.

| Qty/board | Value | Package | Ref |
|---|---|---|---|
| 4 | 100 nF | 0402 | C1–C4 |
| 4 | 10 nF | 0402 | C5–C7, C9 |
| 1 | 10 µF | 0805 | C8 |
| 1 | 1 kΩ | 0402 | R1 |

X7R or better for the decoupling. C8 can be X5R.

**Four pairs, not three.** The AVR128DB64 has **two** VDD/GND pairs (pins 6/7 and 56/57) plus AVDD and VDDIO2 — four supply pins, so four 100 nF + 10 nF pairs. C9 exists because pins 56/57 were found unconnected during the pin audit.

---

## 5. Programming — ✅ ORDERED

**USB UPDI programming adapter, CH340E** — ordered 2026-08-27, **$18.35**,
in transit. (Shenzhen Module Studio; ref 8213565528431578.)

⛔ **It enumerates as `/dev/tty.wchusbserial*`, not `/dev/tty.usbserial-*`.**
The `flash` target originally hard-coded the FTDI pattern, which would have
failed in a way that looks like a dead programmer. `firmware/Makefile` now
auto-detects CH340, FTDI, CP210x and CDC names and prints what it can see if
none match. Override with `make flash PORT=/dev/tty.something`.

⚠️ macOS 11+ carries a built-in CH34x driver, so no vendor kext should be
needed. If the device never appears, that is the first thing to check.

Alternatives, if it disappoints: MPLAB SNAP (official, UPDI capable),
Atmel-ICE (more than needed), or an AVR128DB48 Curiosity Nano — which would
also allow firmware work without the PCBs.

⚠️ **Confirm your programmer's UPDI pin position** against the board's J2: pin 1 = UPDI, pin 2 = +5V, pin 6 = GND. Pins 2 and 6 are standard, but tools differ on where UPDI sits — some expect pin 5.

---

## 6. ✅ On hand — needed before first fit

**Kapton tape** — already in the collection (confirmed 2026-09-01). Cut to the
interposer outline. This is the third of the three mitigations against shorting to the logic board, and the only one not solved in the PCB design itself. The Portable's U15H footprint has live traces and vias inside it.

---

## Total new spend

**ACTUAL, paid 2026-08-27: $325.69** — PCBWay $241.30 (incl. $48.38 duty, $10.97 bank fee), Mouser $84.39.

The earlier "$80-150" estimate was wrong: it omitted ~25% duty, the international bank fee, and the ENIG correction. See `BOM.md` for the breakdown. **Budget ~2x raw board+parts cost on future orders.**

---

## Elsewhere in the collection (separate orders, unrelated to PMGR)

- **PowerBook 100 recap — second order for the SMD positions.** The through-hole order (DigiKey #100885534) is complete, but several board positions are surface-mount. Two values still need a live parametric search: **10 µF 16 V SMD** (the obvious Nichicon part is obsolete) and **3.3 µF 35 V low-profile**. See `project_powerbook100_repair` memory.
- **Newark NFS-26A-0110BF** — LCD cable, logic-board end. Ordered; shipped 2026-09-15 (qty 4), ahead of the ~Nov 2026 estimate. The scarce part.

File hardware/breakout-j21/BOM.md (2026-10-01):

# breakout-j21 — BOM

Build **one**. It is a bench jig and comes out before the machine is closed.

| Ref | Value | Package | Side | Qty | Note |
|---|---|---|---|---|---|
| J1 | **DF12NC(3.0)-50DS-0.5V(51)** | Hirose DF12N 50-pos, 0.5 mm | **Bottom** | 1 | Socket — receives the interposer |
| J2 | **DF12NC(3.0)-50DP-0.5V(51)** | Hirose DF12N 50-pos, 0.5 mm | Top | 1 | Header — receives the MCU board |
| J5 | 1×25 **2.54 mm** pin header | THT | Top | 1 | J21 **ODD** 1–49 |
| J6 | 1×25 **2.54 mm** pin header | THT | Top | 1 | J21 **EVEN** 2–50 |
| H1, H2 | 2.2 mm mounting hole | — | — | — | Not parts |

⚠️ **The footprints say `DF12C` / `DF12E`; the parts to buy are `DF12N`.** The
KiCad footprint names are inherited from `../breakout`, and `design/BOM.md`
records that **the original DF12C is obsolete** — the DF12N series is the
replacement. Same 0.5 mm pitch, same 50 positions, same 3.0 mm stack height, so
the footprint is unchanged; only the ordering part number differs. ⛔ Confirm
the `(51)` suffix matches on BOTH halves before ordering, and verify the pair
physically mates — `design/ORDER-LIST.md` raises the same warning.

⭐ The 2.54 mm headers are the whole point of this board: `../breakout` uses
1.27 mm, which will not take Dupont jumpers. Ordinary 0.1 in strip works; you
can cut two 25-way lengths from a 40-way strip.

## Board spec

```
  2 layer · 1.6 mm · HASL · 27 × 88 mm · two-sided stencil
```

⭐ **2 layers is what shipped** (ordered from PCBWay 2026-09-28, quoted at the
$5.00 promo PCB tier, which confirms the 2-layer entry). The board routed on two
layers with 594 segments, 89 vias and DRC 0/0. Its one deviation is the via
annular ring — see README.md's SHIPPING section. ⚠️ **This block previously said
4 layer**, describing the alternative in README.md's "⬜ The 4-layer alternative
— available, NOT built" rather than the board that was actually cut and ordered.

⚠️ **HASL, not ENIG.** `design/ORDER-LIST.md` records that specifying ENIG on
the original breakout cost **$42.41 instead of $5.00**, purely by dropping out
of PCBWay's promotional tier. Nothing here needs ENIG: no castellations, and no
long-term contact-reliability requirement.

## Assembly

```
  J1   BOTTOM   0.5 mm pitch, 50 pads   <- machine placement earns its money here
  J2   TOP      0.5 mm pitch, 50 pads   <- and here
  J5   TOP      THT, 25 pins            <- trivial by hand
  J6   TOP      THT, 25 pins            <- trivial by hand
```

⚠️ J1 and J2 are on **opposite faces**, so machine assembly of both is
**double-sided** — two reflow passes, and the dominant cost. The stencil data is
present and correct: `F.Paste` and `B.Paste` carry 50 apertures each, for the
two DF12s only. The THT headers correctly have no paste.

Files for a PCBA quote are in `gerbers/`:

```
  pmgr_breakout_j21_gerbers.zip     fabrication
  pmgr_breakout_j21-cpl.csv         placement (centroid), both sides
  this file                         BOM
```

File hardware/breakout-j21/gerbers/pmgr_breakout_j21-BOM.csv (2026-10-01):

Designator | Qty | Manufacturer Part Number | Manufacturer | Description | Package | Mount | Side | Assembly | Notes
J1 | 1 | DF12NC(3.0)-50DS-0.5V(51) | Hirose | Board-to-board SOCKET, 50 position, 0.5mm pitch, 3.0mm stack height | DF12N 50-pos | SMD | BOTTOM | PLACE | SOCKET = DS. BOTTOM side. See assembly drawing for pin 1. Do not substitute the DP header.
J2 | 1 | DF12NC(3.0)-50DP-0.5V(51) | Hirose | Board-to-board HEADER, 50 position, 0.5mm pitch, 3.0mm stack height | DF12N 50-pos | SMD | TOP | PLACE | HEADER = DP. TOP side, directly above J1. See assembly drawing for pin 1. Do not substitute the DS socket.
J5 | 1 | 1x25 2.54mm pin header | - | Pin header, 1x25, 2.54mm, vertical | 1x25 P2.54mm | THT | TOP | DO NOT POPULATE | Customer-fitted. Do not source or place.
J6 | 1 | 1x25 2.54mm pin header | - | Pin header, 1x25, 2.54mm, vertical | 1x25 P2.54mm | THT | TOP | DO NOT POPULATE | Customer-fitted. Do not source or place.

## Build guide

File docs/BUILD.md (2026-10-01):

# Building one

This is the route from bare boards to a working machine. Each step points to the detailed
document; **[`ASSEMBLY.md`](ASSEMBLY.md) is the bench-tested procedure and wins wherever the two
disagree.** Some detailed documents mention entries in the development log, which is not part of
this repository.

Read the safety notes in the top-level [`README`](../README.md) first.

## 0. Skills and tools

This is **fine-pitch surface-mount work on an irreplaceable machine.** Be comfortable with:

| part | where | what it takes |
|---|---|---|
| AVR128DB64, TQFP-64, **0.5 mm** pitch | MCU board, top | drag soldering with plenty of flux; inspect every side for bridges |
| Hirose DF12, 50 pins, **0.5 mm** pitch | one on each board — the MCU board's is on the **underside** | no mechanical key: verify rotation with a meter before soldering |
| **0402** passives (×8) and a SOT-23 diode | MCU board, both sides | tweezers and magnification |
| the original M50753, 60 leads | the Mac's logic board | **removal** with hot air and preheat, without lifting pads or overheating the board |
| interposer, 60 castellated edges, 0.8 mm | onto that footprint | aligning and soldering all four sides in place |

**Tools:** hot-air station with preheat, fine-tip iron, flux, solder wick, tweezers, a multimeter,
and magnification — a stereo microscope is strongly recommended.

⭐ **Ordering the MCU board assembled** (two-sided, from the files in `hardware/mcu-board/`) takes the
0.5 mm and 0402 work off your bench. Removing the original chip and fitting the interposer can't be
outsourced. If you haven't removed a fine-pitch QFP from a board you care about before, practise on
scrap first.

## 1. Order the boards

| Board | Specification | Files |
|---|---|---|
| Interposer | 4 layer · 1.6 mm · **ENIG** · 16.3 × 16.3 mm · **castellated plating on all 60 half-holes** | `hardware/interposer-v2/` |
| MCU board | 4 layer · 1.6 mm · ENIG · 20.0 × 23.5 mm · two-sided stencil | `hardware/mcu-board/` |
| J21 breakout *(optional)* | 2 layer · 1.6 mm · HASL · 27 × 88 mm | `hardware/breakout-j21/` |

- ⛔ **ENIG is not optional on the interposer** — its 0.4 mm castellated half-holes need it.
- The breakout is only for development. Ordering it in HASL keeps it in most fabs' cheapest tier.
- ⚠️ The breakout's vias are 0.20 mm drill with a 0.125 mm annular ring. PCBWay builds that on their
  standard order; **JLCPCB's standard process does not** (0.30 mm / 0.13 mm minimum).

## 2. Order the parts

[`BOM.md`](BOM.md) and [`ORDER-LIST.md`](ORDER-LIST.md). Three things catch people out:

- **The two halves of each DF12 connector are not interchangeable.** The socket (`DS`) and header
  (`DP`) go on specific boards — see "Which part goes where" in [`ASSEMBLY.md`](ASSEMBLY.md).
- **Both halves must be the 3.0 mm stack height.** Every height shares the same footprint, so a
  wrong-height part solders down perfectly and then won't mate. **Mate a pair by hand before
  soldering either.**
- Order a spare AVR128DB64. Reworking a 0.5 mm TQFP-64 is the hardest repair on this board.

## 3. Assemble the MCU board — [`ASSEMBLY.md`](ASSEMBLY.md), Gate 0 and Step 1

- ⛔ **Resolve orientation (Gate 0) before any solder.**
- **Read the AVR's device ID before fitting the programming header `J2`** (step 4 below). A dead
  part and a bad joint look identical; this separates them while rework is still easy.
- `J1` (the DF12) has **no mechanical key** — verify its rotation with a meter.
- **Three adjacent pin pairs are supposed to be shorted.** Don't "fix" them when hunting bridges.

## 4. Program the AVR — before it goes anywhere near a machine

**Full step-by-step guide: [`PROGRAMMING.md`](PROGRAMMING.md).** The short version:

1. Build: `make -C firmware`.
2. Programmer: any USB-UART adapter used as SerialUPDI, with a **1 kΩ series resistor** on the
   data line.
3. ⭐ **First, read the device ID** — not a flash:
   `pymcuprog ping -t uart -u <port> -d avr128db64` must answer `1E970B`.
   ⚠️ If it reports "UPDI initialisation failed", check the board is actually powered: a programmer
   alone back-feeds only ~1.65 V, below the AVR's brown-out, so it cannot be programmed that way.
4. **Fuses, once per board, before the first flash:** `make -C firmware fuses`
   (see [`../firmware/FUSES.md`](../firmware/FUSES.md)).
5. Flash — see step 7 for why it should go through the flash tool once a record exists.
6. ⛔ **Then unplug the programmer and do a real power cycle** — supply or battery disconnected.
   This applies after **any** programmer operation, even a device-ID read with nothing written:
   without it, a machine that is shut down failed to wake from the keyboard every time it was
   tried (7 of 7). A power-on start always works. The cause has not been established.

⛔ **`J2` pin 2 is +5 V and it reaches the machine.** Mind it when wiring the programmer.

## 5. Fit the interposer — [`ASSEMBLY.md`](ASSEMBLY.md), Steps 2 and 4

The original M50753 has to come off the logic board first. **Keep it** — it is irreplaceable, and
the reference for everything this replaces. Then solder the interposer to the footprint by its
castellated edges, and check it before stacking.

## 6. Stack and first power-on — [`ASSEMBLY.md`](ASSEMBLY.md), Steps 5 and 6

Interposer on the logic board, then (optionally) the J21 breakout, then the MCU board.
Bench power first, at a modest voltage, with the battery out.
Check the voltages and pin references in [`REFERENCE-MEASUREMENTS.md`](REFERENCE-MEASUREMENTS.md).

## 7. Calibrate the battery reading

Each machine's hybrid reads the battery slightly differently. The firmware uses a **per-unit
calibration record** (16 bytes, EEPROM address 464) to correct for it, and **refuses to fast-charge
without a valid one.** The machine works without a record — it just charges slowly.

1. **Collect pairs from an UNCALIBRATED board.** Flash the firmware **without** a record first
   (leave `calib.args` off — see [`PROGRAMMING.md`](PROGRAMMING.md)). Only then is the level the PMGR
   reports the raw, uncorrected reading. ⛔ Readings taken from a board that already has a record are
   corrected values, and fitting them would undo the correction.
   Record the pack voltage (DMM, at the pack terminals) against that level, across **at least
   0.80 V** — roughly 5.8–7.2 V — in both directions.
2. **Fit and judge it**: `python3 tools/pmgr_calib_fit.py <pairs.csv>`. It **refuses**, with a
   non-zero exit, a fit whose worst residual exceeds **2 counts** or whose span is under **0.80 V** —
   the same limits the firmware enforces. When it passes, it prints the exact command for step 3,
   with the slope, intercept, residual and span filled in.
3. **Build the record** with that command, adding the +5 V rail you measured at J21-1 and any
   pairing number for this hybrid/board pair:
   `python3 tools/pmgr_calib_image.py --a <slope> --b <offset> --resid <worst> --span <volts> --rail <+5V> --id <n> > calib.args`
4. **Flash with it**:
   `tools/pmgr_flash_with_pram.py firmware/pmgr.hex <md5-prefix> - calib.args`
   — it refuses a hex whose MD5 doesn't match, writes the record and reads it back.

⛔ **Every flash erases EEPROM.** Always flash through the tool with the record, or the board
silently returns to "no fast charge".
As after any programmer operation, **unplug the programmer and power-cycle** before starting the
machine (step 4).

⚠️ **Honest limitation:** step 1 currently needs the level the PMGR reports, which in development
was read by decoding the PMGR's battery reply with a logic analyser. A simpler way to read it is
an open problem — contributions welcome.

## 8. First charge — supervised

Pack voltage on a DMM, the machine in sight, and a limit you will act on. The original 3-cell Cyclon
pack should stay below **7.5 V**; abort at 7.6 V. See [`VERIFIED.md`](VERIFIED.md) for what charging
behaviour has and has not been measured.

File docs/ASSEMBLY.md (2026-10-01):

# Assembly — from bare boards to a stack ready for `BRING-UP.md`

Boards arrive **bare**. This is the order to put them together in, what to check
between steps, and where the irreversible mistakes are.

> ⚠️ **Written 2026-09-07, before the boards arrived. Being performed for the
> first time from 2026-09-08.**
>
> | step | status |
> |---|---|
> | **Step 2 — interposer** | ✅ **ONE COMPLETE, 2026-09-08** — the first assembled board in this project |
> | Step 1 — MCU board | ⏳ in progress |
> | Steps 3–6 | ⛔ not started |
>
> ⭐ Every step is derived from this repository's own measurements and board files
> — none of it is generic SMD advice. ⛔ **Treat a surprise as evidence about the
> procedure, not only about the hardware**, and amend the text as you go: three
> corrections already came from the bench on day one (the Gate 0 circles, the
> `DF12` naming, and the legitimate adjacent shorts).

---

## ⛔⛔ GATE 0 — ORIENTATION. Resolve this BEFORE any solder.

**This is the one mistake that cannot be undone.** The pad ring is symmetric, so
a wrongly-rotated interposer fits perfectly and is wrong by 90° or 180°.

> ⛔⛔ **CORRECTED 2026-09-08, ON THE DELIVERED BOARDS (2.76).** The section
> below describes **three circles with the smallest at pin 1**. ⚠️ **That is not
> what was fabricated.** The interposer carries **two NUMBERED circles — ① and
> ⑮ — plus one large plain circle.**
>
> ⭐⭐ **Use the numbers.** On the PowerBook 100 they read directly against
> Apple's own silkscreen: interposer **①** to `U22`'s **1** (bottom edge),
> interposer **⑮** to its **15**. Confirmed by placement on the real footprint.
>
> ⭐ **The delivered scheme is the better one** — a number cannot be mistaken for
> another number, where "smallest of three" needs all three in view and
> comparable. ⛔ Kept below because the *reasoning* about Apple's marks still
> holds; only the description of **our** board was wrong.

### ⭐⭐ THE CIRCLES ARE THE METHOD — ours match the chip's and the board's

⭐ The three circles on our boards were placed **deliberately, to match the ones
on the M50753 package and on Apple's `U15H`/`U22` footprint**. So aligning
circle-to-circle is correct, and it is the intended way to seat the interposer.

⭐⭐ **Three marked corners with the fourth blank is not rotationally symmetric**,
so the pattern alone fixes the orientation — there is no 90° or 180° ambiguity
left once the circles line up. ⭐ `interposer-v2/README.md` adds a second,
independent check: the **smallest** circle sits at pin 1.

> ⚠️ **An earlier draft of this section had this backwards.** It claimed ours and
> Apple's were two different systems that merely looked alike, and warned against
> aligning them — the opposite of the truth. Recorded because a procedure that
> invents a hazard wastes as much attention as one that misses a real one.

⭐ What 2.63 established still holds and is worth knowing, because it explains
*why* the circles work: Apple's three are an **orientation key matching the chip's
mould marks**, and pin 1 is separately marked by a **filled white dot**. Two
independent markings, both usable.

### ⛔ THE TWO MACHINES MARK IT DIFFERENTLY — use the right check for each

⚠️ **They are complementary: each has what the other lacks.** Do not carry a
method from one board to the other.

| machine | what the footprint carries | how to verify the interposer |
|---|---|---|
| **PowerBook 100 `U22`** | ⭐⭐ **pin numbers printed right around the pad ring, every 5 pins on all four sides** — `1 5 10 15` · `16 20 25 30` · `31 35 40 45` · `46 50 60` — plus a **pin-1 mark**. ⛔ **NO circles** | ⭐ verify from **any** edge, and cross-check on a second — four-sided numbering means orientation is over-determined, not a single mark to find. ⛔ Do not look for circles to align; there are none |
| **Macintosh Portable `U15H`** | ⭐ **three circles** + the **filled pin-1 dot**. ⛔ **NO printed numbers** — a plain box marked `V15H` with `PMGR` beside it | **circles line up**, and the smallest sits at the dot |

⭐⭐ **Confirm on the PB100 first even though the Portable is fitted first.** Its
four-sided numbering is the strongest reference either machine offers — you can
read the answer off two independent edges — and checking there tells you what
"correct" looks like before doing it on a board that prints nothing at all.

⭐ **And buzz it either way before committing:** interposer castellation **1**
carries net `VIAD4`, and chip pin 1 is `P24`/`VIAD4` on Apple sheet 12 — an
electrical check that needs no silkscreen at all.

---

## Step 1 — MCU board (`pmgr_mcu`), 20.0 × 23.5 mm

**14 placements, 5 of them bottom-side.**

| side | parts |
|---|---|
| **Top** | `U1` AVR128DB64 TQFP-64 · `J2` 2×3 UPDI header · `C1–C3` 100 nF · `C5–C7` 10 nF · `C8` 10 µF 0805 |
| **Bottom** | `J1` DF12 socket · `D1` BAT54S · `R1` 1 kΩ · `C4` 100 nF · `C9` 10 nF |

### ⭐ Hand assembly — the chosen route for the first article

⛔ **BOTTOM SIDE FIRST**, and for hand work the reason is mechanical: once `U1`
and the top-side passives are on, working the bottom means resting the board on
them. Do the bottom while the top is still flat and bare.

⭐⭐⭐ **AND DO `J1` BEFORE ANYTHING ELSE IF AN INTERPOSER IS ALREADY BUILT** —
a second reason, learned 2026-09-08 once interposer #1 was finished (2.78). With
its header in hand you can **mate the two immediately**, which is the only way to
catch a stack-height mismatch: the land pattern is identical across
3.0/3.5/4.0/5.0 mm, so a wrong-height part solders down perfectly and fails
silently. ⭐ Catch it with **one part** on the board rather than fourteen.

⭐ Practical: it is also the **same joint you have just done**, 50 pins at 0.5 mm,
so do it while the technique is warm rather than after a break. ⚠️ Expect it to be
harder to *inspect* — the socket's contacts are recessed where the header's sit on
the outside of its box.

**Within each side, hardest first, while nothing is in the way:**

```
  BOTTOM   1. J1  DF12 socket    50 pins at 0.5 mm — the hardest joint here
           2. D1  BAT54S SOT-23
           3. R1, C4, C9         0402
  TOP      4. U1  AVR128DB64     TQFP-64, 0.5 mm — drag-solder, flux, wick
           5. C1-C3, C5-C7, C8   0402 and one 0805
           6. J2  2x3 header     LAST — through-hole and the tallest thing
```

⚠️ **`J2` last, and trim its pins after** (`BOM.md`). It is through-hole on a
board with a 3.0 mm gap beneath, so untrimmed pins foul the stack.

### ⭐⭐⭐ CHECKPOINT — read the device ID at step 5, BEFORE fitting `J2`

⛔ **Do not wait until the board is finished to find out whether `U1` is alive.**
Once `U1` and the top-side passives are on, the chip has everything it needs to
answer: `VDD`, `GND`, decoupling, and `UPDI` on pin 51.

```
  clip test leads onto the J2 PADS  (through-hole, easy to reach while empty)
     J2-1  UPDI     J2-2  +5V     J2-6  GND
  read the device ID
```

⭐⭐ **One response proves the hardest part of the build:**

| ✅ | |
|---|---|
| `U1` survived the drag-solder | the 0.5 mm joints conduct |
| it is the right part | signature reads `AVR128DB64` |
| `UPDI` reached pin 51 | that trace and joint are good |
| power and ground are sound | it could not answer otherwise |

⚠️ **This matters more without a socket adapter** (none is on hand — see below):
there is no way to pre-screen a chip, so this is the *first* moment the part can
be shown alive. ⛔ **A dead chip and a bad drag-solder look identical**, and
finding out here — with `J2` not yet committed and the board otherwise finished —
is the cheapest place to start telling them apart.

⚠️ **`C9` is easy to miss.** It was added late, after the pin audit found
AVR pins **56/57** unconnected — it is not in older BOM prints.

### ⭐ WHICH PART GOES WHERE — `DS` vs `DP`

#### ⭐⭐⭐ TELLING THEM APART BY EYE — observed on the parts, 2026-09-08

```
  HEADER  (DP)   an OPEN BOX, with the contacts on the OUTSIDE of the box
  SOCKET  (DS)   contacts in the MIDDLE, which reach out and meet the box's
                 outside when the two are placed together
```

⭐ **That is the reliable identification** — it needs no part number and no
male/female vocabulary, both of which mislead here. ⚠️ Neither part looks like the
usual "posts vs holes" picture, which is why two earlier attempts to describe them
in this document were wrong.

⭐ **One inference worth having, flagged as inference:** the header's contacts sit
on the *outside* of its box and are therefore the more visible and reachable of
the two. ⛔ The **MCU board gets the socket** — the recessed one — **on its
underside**, so that is the joint that is hardest to inspect *and* the one you
cannot see once the top is populated. Budget the magnification accordingly.

⛔⛔ **PLACEMENT STILL GOES BY THE PART-NUMBER SUFFIX, NOT BY APPEARANCE.**
`DS` and `DP` are **Hirose's suffixes**, not a description of the physical form —
observed at the bench 2026-09-08, the part called the *header* is the one with the
**opening the other sits into**, which is the opposite of the usual mental image.
⚠️ An earlier version of this table glossed them as *"receptacle"* and *"posts"*
and that gloss is **withdrawn**; it would have someone sorting parts by eye
against the wrong picture.

```
  MCU board     J1   ...-50DS-...   BOTTOM, facing DOWN
  interposer    J1   ...-50DP-...   TOP,    facing UP
  breakout      J1   ...-50DS-...   bottom   (receives the interposer)
                J2   ...-50DP-...   top      (receives the MCU board)
```

⭐⭐⭐ **And the check that settles it without any naming at all: MATE THEM BY
HAND.** If the two parts you are about to fit click together, you have the right
pair *and* the right stack height. ⭐ That test does not care what anything is
called, which is exactly why it is the one to trust.

⭐⭐ **The rule in one line: every board presents `DP` upward and `DS` downward.**
The interposer is the bottom of the stack, so it carries only the up-facing `DP`;
the MCU board is the top, so it carries only the down-facing `DS`; the breakout is
an insert and has both.

⛔⛔ **THE EXPENSIVE MISTAKE IS NOT `DS` vs `DP` — IT IS THE STACK HEIGHT.**
`BOM.md`: the land pattern is **identical across 3.0 / 3.5 / 4.0 / 5.0 mm**, so a
wrong-height part solders down perfectly and **silently fails to mate**.

```
  confirm (3.0) AND the (51) suffix on BOTH halves
  MATE ONE SOCKET TO ONE HEADER BY HAND      <- while they are still loose parts
```

⚠️ Thirty seconds, and it is the only check that catches a height mismatch
**before it is permanent**.

### ⛔⛔ `J1` HAS NO MECHANICAL KEY — VERIFY THE ROTATION WITH A METER

⚠️ **`DF12NC` means "without boss, without fitting"** (`BOM.md`). ⛔ **Nothing
physically prevents soldering it 180° round.** The obsolete `DF12C`/`DF12E` parts
were specified the same way, so there is no guide boss to seat and no metal
fitting to align — the **footprint's pin-1 marking is the only guide**, on the
board's hardest joint, on the side you cannot see once the top is populated.

⭐⭐⭐ **So check it electrically, right after tacking and before soldering all
50 pins.** Power and ground make this trivial and need **no chip fitted**:

```
  CORRECT     GND at 23, 24, 25, 49      +5V at 47, 48
  180 deg     GND at  2, 26, 27, 28      +5V at  3,  4
```

⭐ A 180° rotation maps pin **N → 51−N**, so the two cases share no pins at all —
there is no ambiguous middle. ⚠️ **Buzz `23`, `24`, `25` and `49` to the ground
plane.** Four pins, one meter setting, and the answer is yes or no.

⛔ **Do this while only two corners are tacked.** Reworking a 50-pin 0.5 mm
connector after all 50 are down, on the underside of a board you then have to
rebuild, is the most expensive mistake available in Step 1.

### ⛔⛔⛔ HUNTING BRIDGES: THREE ADJACENT PAIRS ARE *SUPPOSED* TO BE SHORTED

⚠️ **Reported from the bench 2026-09-08: this joint is slow and produces plenty
of bridges.** That is expected — the table above already calls bridges *"normal,
expected, not rework"*. ⛔ **But do not go looking for them with a meter without
knowing this first:**

```
  23 - 24    both GND     <- reads as a dead short, and is CORRECT
  24 - 25    both GND     <- correct
  47 - 48    both +5V     <- correct
```

⭐⭐⭐ **Every OTHER adjacent pair should be open.** Without this list an operator
finds three "shorts", concludes the joint failed, and reworks pins that were
perfect — adding heat cycles to a 4-layer board to fix nothing.

⭐ **Technique, in the order that usually works:** more **flux**, not more heat —
nearly every fine-pitch bridge is a flux problem, and flux that has already been
through a heat cycle has spent its activator. **Flux the braid too**; dry wick
needs more dwell and dwell is what lifts pads. **Work a whole edge in one pass**
rather than chasing bridges individually. ⛔ **Let the board cool between
passes** — cumulative heat on a ground-planed 4-layer board is what does damage,
not any single pass.

### ✅ WHAT "DONE" MEANS FOR `J1`

```
  [ ] no adjacent shorts  EXCEPT  23-24, 24-25, 47-48
  [ ] GND present at 23, 24, 25, 49        (also the rotation check)
  [ ] +5V rail at 47, 48
  [ ] inspect under magnification NOW, while the top side is still bare
```

⭐ The last line is free at this moment and impossible once `U1` is on.

⛔ **`D1` BAT54S is the ADC clamp**, and `BOARD-DESIGN-BRIEF.md` calls it *"the
design's one genuine improvement over Apple's"*. ⚠️ It is a bottom-side part, so
it goes on in step 2 and is invisible afterwards. Do not defer it.

### ⛔ `U1` — prevention, because rework on this board is genuinely bad

`U1` is the **AVR128DB64-I/PT**, TQFP-64, 10×10 mm, **0.5 mm pitch**, top side.
`BOM.md` says "order a spare — awkward to rework". Here is why, and what to do
instead.

⛔ **Why removal is worse here than on a typical board:** by the time `U1` goes
on, the **bottom side is already populated** — `J1`, `D1`, `R1`, `C4`, `C9`. Hot
air on the top means the board resting on those parts, heat conducting through a
**4-layer 1.6 mm board with ground plane**, and a real chance of shifting or
losing bottom-side 0402s you cannot see. ⭐ Expect to lose neighbouring top-side
passives too.

⭐⭐ **So the plan is prevention, in this order:**

```
  1. tack pin 1 and the DIAGONALLY OPPOSITE pin only
  2. STOP. Inspect alignment under magnification, all four sides
  3. only then drag-solder the rest
```

⭐ Two tacked corners can be reflowed and nudged freely. Sixty-four cannot.

**If it does go wrong, by severity:**

| symptom | response |
|---|---|
| **bridges** | ⭐ flux and wick — normal, expected, not rework |
| **one or two lifted/unwetted pins** | more flux, re-drag that edge |
| **misaligned by a pin, or rotated** | ⛔ full removal. Hot air with **preheat**, plenty of flux, lift straight up. Budget the spare `U1` and expect passive collateral |
| **chip dead** | replace with a spare. ⛔ **With no socket adapter you cannot pre-verify the replacement either**, so this is where the 3 spares matter more than any tool |

✅ **Four `U1` on hand** — Mouser `579-AVR128DB64-I/PT`, $2.31 ea, shipped
2026-08-31. That matches `BOM.md`'s quantity for three boards plus a spare.
⚠️ Note the BOM cites a **DigiKey** part number (12807611); same MPN, different
distributor — no issue, but the BOM is not the only source used.

⭐⭐ **BUILD ONE FIRST, not the whole lot** — the chosen approach, and it is the
right one twice over:

```
  build all at once   1 spare across 3 boards    thin
  build ONE first     3 spares for that board    generous
```

⭐ It also means learning the process — drag-soldering a 0.5 mm TQFP, the
bottom-side `DF12` — on an article you can afford to lose, before committing
parts to the rest. ⚠️ An earlier note here warned that "one spare across the
build" left no margin. That assumed building all of them at once; it does not
apply to building one.

⛔⛔ ~~**Verify the chips in the `T48` before the boards arrive**~~ — **NOT
AVAILABLE. Corrected 2026-09-08: there is NO TQFP-64 socket adapter.** This said
*"the socket adapter is on hand"*, which was never true, and the pre-screen was
recommended repeatedly on that basis.

⭐ **It changes less than it sounds like.** The pre-screen was insurance against
a **DOA part from an authorised distributor** — a low-probability event. What
replaces it costs nothing:

| | |
|---|---|
| ⭐⭐ **build ONE board first** | already the plan, and now load-bearing rather than merely sensible: 4 chips, 1 board, **3 spares** |
| ⭐⭐⭐ **device ID as the FIRST command** | before fuses, before flash — see Step 3 |
| ⚠️ the failure you must not make | a dead chip **looks exactly like a bad drag-solder**. With three spares you can afford to find out which |

⭐ A socket adapter is still worth owning eventually — it is the only way to
prove a part *before* committing it — but it is **not** a prerequisite and should
not hold up Step 1.

> ⭐ *If you later move to stencil and reflow: same bottom-first order, for the
> different reason that the DF12 is the alignment-critical part and should not be
> reflowed while the board sits on top-side components.*

⚠️ `J2`'s pins must be **trimmed after soldering** (`BOM.md`) — it is a
through-hole header on a board with a 3.0 mm stack gap beneath it.

⛔ `D1` **BAT54S is the ADC clamp** and the design's one genuine improvement over
Apple's (`BOARD-DESIGN-BRIEF.md`). Do not omit it "for now" — it is what protects
the ADC input the original had no margin on.

### Check before moving on

- ⛔ **`+5V` to `GND` not shorted.** Four decoupling pairs and two 0.5 mm-pitch
  parts make a bridge easy and invisible
- ⭐⭐ **Meter every `J1` pin against its neighbour**, not just eyeball it. 50 pins
  at 0.5 mm hand-soldered is where a bridge will be, and it is underneath where
  you cannot see it once stacked
- `U1` pin 1 orientation against the silkscreen
- ⚠️ **`C9` placed** — the late addition above
- ⭐ Continuity `J1` → `U1` on a couple of known pairs, using the generated map in
  `README.md` (e.g. `PMGR_IN0` → `PD7`, `SYS_PWR*` → `PG0`). Catches a rotated or
  shifted connector before it reaches a machine

---

## Step 2 — Interposer (`pmgr_interposer_v2`), 16.30 mm square

⭐ **One part only.** `J1`, the **`DF12NC(3.0)-50DP-0.5V(51)` header** (`DP` =
posts), on the **top**, facing **up**. ⚠️ Older text here said `DF12E(3.0)` —
that part is **obsolete** and is not what is in the bag (`BOM.md`). Everything
else on this board is copper: 60 castellations and the connector pads.

⚠️ ⛔ **Boards from this run are silkscreened `PMGR Chip`, not `J1`** — the
designator was fixed after ordering (`BOM.md`). Nothing electrical differs.

### ✅✅ ~~DO THIS BEFORE THE BOARDS ARRIVE~~ — **MEASURED 2026-09-07, IT FITS**

> ✅ **CLOSED by `MEASUREMENTS.md` 2.73.** Caliper across the PowerBook 100's
> **bare `U22` pad ring**: **16.3 mm**, landing on the **middle of the pads**, with
> a **13 × 13 mm** body. The fabricated interposer is right. ⭐ Everything below is
> kept as the reasoning, and the 14-gap check is now **optional** — an independent
> route to the same number, not a prerequisite.

⚠️ **The interposer's geometry traced to a design-time assumption that was
flagged for confirmation and never confirmed.** `BOARD-DESIGN-BRIEF.md`:44 reads
*"matches the M50753 pad ring (~17–18 mm square **if 0.8 mm pitch / 14 mm body —
confirm by measurement**)"*, and the fabricated board is **16.3 mm square, 15
castellations per side at 0.8 mm**.

⛔ **The "it lands on the pad ring" check is circular for SIZE.**
`CLEARANCE-MEASUREMENTS.md` says so plainly — *"reference and subject are the same
object"*. The photogrammetry took 16.30 mm as its scale, so it confirms
**squareness** (axes agree to 0.1 %) and cannot confirm **magnitude**.

⭐⭐⭐ **One caliper measurement settles it, and a chip is on the bench now.**

| measure | expect | why |
|---|---|---|
| ⭐⭐ **lead 1 tip → lead 15 tip, one side** | **11.20 mm** | ⭐ **the sharpest test — 14 gaps, so caliper error divides by 14.** At 0.65 mm pitch this reads **9.10 mm** |
| lead tip → lead tip, across the package | ~**16.3 mm** | the pad-ring figure the interposer is built to |
| body only, across the plastic | ~**13 mm** | `breakout/README.md`'s datum — ⚠️ from a *silkscreen* outline, not a datasheet |

⛔⛔ **Measure across 14 gaps, not one pitch.** A single 0.8 mm gap is inside
caliper reading error; 11.20 mm is not, and it discriminates 0.8 from 0.65 by
**2.1 mm** — unmissable.

⭐ **If it reads 11.2 mm, the interposer fits and this closes.** ⚠️ **If it reads
9.1 mm, the fabricated boards do not fit the chip at all** — and finding that now
rather than with a soldering iron in hand is the entire point of doing it before
they land.

---

## Step 3 — Program the AVR BEFORE it goes near a machine

⭐ **Flash and verify on the bench, with the MCU board unmated.** Reaching `J2`
is easy now and awkward once the stack is in a Mac.

```
  firmware   firmware/pmgr.hex     text 10715 bytes, avr-gcc 14.3.0
             ⭐ byte-identical to baselines/2026-09-30-charging-adc-interlock/
```

### ⛔⛔ BEFORE YOU WIRE ANYTHING — `J2` PIN 2 IS +5V, AND IT REACHES THE MACHINE

⚠️ `J2` pin 2 is the board's **VDD**, which runs through the `DF12` to the
interposer and onto the Macintosh's **`+5V ALWAYS ON`** rail.

⛔⛔ **So powering the board through `J2` while the stack is fitted energises the
Mac's always-on rail from the programmer.** ⭐ Step 3 avoids this by programming
**unmated** — but the risk is not step 3's, it is **later**: the first time you
want to reflash during bring-up, the stack will be in a machine.

```
  reflashing with the stack FITTED:
     power the board from the MACHINE, not the programmer
     -> connect UPDI (J2-1) and GND (J2-6) only.  LEAVE J2-2 OFF.
```

⚠️ A Tigard set to 5 V will happily try to drive a Macintosh's rail through a
0.5 mm connector. It will not source the current, and what happens instead is not
worth finding out empirically.

### ⭐⭐ THE FIRST COMMAND IS NOT A FLASH — READ THE DEVICE ID

⭐⭐⭐ **Before writing anything, ask the part what it is.** It needs no firmware,
no fuses and no image, and a single response proves four things at once:

| ✅ | |
|---|---|
| `U1` is **alive** | it survived the drag-solder |
| it is the **right part** | the signature reads `AVR128DB64` |
| **UPDI is connected** | pin 51 reached `J2`-1 |
| **power and ground are good** | it could not answer otherwise |

⛔ **A dead or mis-soldered `U1` found here costs one chip.** Found after fuses
and flash, it costs the same chip plus the time spent believing the toolchain was
at fault.

### The programmer

⭐ **Serial UPDI adapter (CH340E)** — on order 2026-09-07. That is enough for
Step 3: this step only needs **flashing**.

> ✅✅ **`J2` DOES carry `DBG0/1/2` — confirmed from the board file 2026-09-09.**
>
> ```
>   J2-1  UPDI      J2-2  +5V      J2-6  GND
>   J2-3  DBG0      J2-4  DBG1     J2-5  DBG2
> ```
>
> ⛔⛔ **A "correction" on 2026-09-08 wrongly denied this** and sent the operator
> to look for test pads elsewhere. There are **none** — `pmgr_mcu.kicad_pcb`
> contains no `TP` footprints, and routes `J2` pads 3/4/5 straight to U1 pads
> 49/48/47. ⚠️ The bad edit trusted `MCU-BOARD-SCHEMATIC.md`'s pin table over the
> fabricated board, with both available. ⭐ **The board file outranks the prose.**

⭐⭐⭐ **An XGecu `T48` is also on hand, and it supports UPDI** — so there are two
independent paths and the Dx-support risk is covered. Use whichever proves out;
the serial adapter is the convenient one, the `T48` is the known-good one.

| | |
|---|---|
| ⛔ **In-circuit, not the ZIF socket** | `U1` will already be soldered down, so programming in place means the `T48`'s **ICSP header** wired to `J2` — not the 48-pin socket |
| ⚠️ **Confirm `AVR128DB64` is in the Xgpro device list** | the `T48` supports the Dx family, but the specific part must be present. ⭐ A software lookup — free, and worth doing before the boards land |

⚠️ **The `T48` could verify a chip BEFORE it is soldered — but only with a
TQFP-64 socket adapter, and there is not one.** ⛔ So this path is unavailable
for the first build; the `T48` is an **in-circuit** programmer here, via its ICSP
header wired to `J2`, exactly like the other two.

⭐⭐ **A Tigard is also on hand, and it should work too — possibly best of the
three.** UPDI is a **single-wire half-duplex UART** protocol, and a serial UPDI
adapter is nothing more than a USB-serial port with **TX and RX bridged through
~4.7 kΩ**. The Tigard's UART channel does that as well as anything, and
`pymcuprog` / `avrdude -c serialupdi` do not care what is behind the port.

⭐ **Why it may be the best option:** it has a **voltage selector**, which is
exactly the worry with the cheap adapter — this board runs at **5 V**, and a
3.3 V-only adapter driving a 5 V UPDI line is marginal. The FT2232H is also a
better-behaved part than a CH340E.

✅ **Voltage selection confirmed** — the Tigard can be set to the target's rail,
so the 5 V question that hangs over the cheap adapter does not apply here.

### ⛔⛔ THE TIGARD HAS NO UPDI HEADER — AND THE RESISTOR IS 1 kΩ, NOT 4.7 kΩ

⚠️ **Both halves corrected 2026-09-08, against primary sources.**

**1. You DO need the resistor.** Checked against the Tigard's own repository: its
headers are **UART, SPI/I2C, JTAG, CORTEX, I2C-JST and LA**, and its protocols are
UART, SPI, I2C, JTAG, SWD, AVR ISP and iCE40. ⛔ **There is no UPDI header and no
UPDI circuitry.** ⚠️ Advice circulating that the Tigard has *"current-limiting
built into its UPDI output"* describes hardware the board does not have. Wiring
`TX` and `RX` together directly puts an FT2232H push-pull output against the AVR's
UPDI pin every time the target drives low — tens of mA, limited only by both
drivers' output impedance.

**2. ⛔ The value was wrong here.** This said *"~4.7 kΩ"*, a widely-copied figure.
`pyupdi`'s own README specifies **1 kΩ**, and the working range is **100 Ω – 1 kΩ,
with 470 Ω cited as optimal**.

```
  470 ohm .. 1k     the documented range      <- use this
  4.7k              above it, copied widely
  10k               well above; edge rates suffer at speed
```

⭐ **The constraint that matters is edge rate, not contention current.** A few mA
of contention is what both drivers are expected to survive; **RC on the line is
what breaks programming at higher baud**, and that gets worse as resistance rises.
⚠️ An earlier version of this note had that backwards and rejected a perfectly
good 560 Ω part in favour of 10 kΩ.

⭐⭐ **Recommended order to try:** Tigard at 5 V first (best signal integrity and
the right rail), `T48` via ICSP as the known-good fallback, CH340E adapter last.

⚠️ **Two things to confirm about the serial adapter**, because the listing says
*"ATTINY AVR"* and this is a newer **AVR-Dx** part:

| check | why |
|---|---|
| ⭐ **Toolchain knows `AVR128DB64`** | `pymcuprog` (recent) or `avrdude` **7.x** with `-c serialupdi`. Older avrdude has no Dx support at all |
| ⛔ **Adapter runs at 5 V, not 3.3 V** | UPDI is single-wire referenced to the target's `VDD`, and this board runs at **5 V** — the entire reason for the AVR-DB choice. A 3.3 V-only adapter is marginal into a 5 V target |

⚠️ **No hardware debugger.** `STAGE1-BENCH-PROTOTYPE.md` suggested a Curiosity
Nano or Xplained specifically to get one "for free"; a serial adapter flashes but
does not single-step. ⭐ **That is workable here, and the firmware was built for
it** — the three `DBG` pins on `J2` report state a DMM can read:

```
  DBG1  PF4  TQFP 48   ADC has EVER faulted — LATCHED, so a transient stays visible
  DBG2  PF3  TQFP 47   the scale self-check has PASSED
  DBG0  PF5  TQFP 49   spare
```

⭐⭐ `DBG2` is the one to watch at first power-on: it goes high only when
`pmgr_adc_recheck_scale()` accepts `ref5V`, which is exactly the 113-vs-126
question. A DMM on `J2` answers it without any debugger at all.

⚠️ **Fuses matter here, not later.** 2.54 measured the original taking control of
`HICHG` within **~10 ms** of rail-up, and an AVR128DB64 is **high-Z until firmware
runs** — with default fuses that exceeds 10 ms. ⭐ 2.55 found the board already
biases every net safe, so this is survivable — but set start-up time deliberately
and record what you chose.

---

## Step 4 — Solder the interposer to the footprint

⛔ **Gate 0 must be resolved before this step.** This is the irreversible one.

- ⭐ Castellation pads extend **0.325 mm outside the board outline**
  (`interposer-v2/README.md`) — they are meant to be soldered from the side, like
  a castellated module, not reflowed underneath
- ⛔ **Which machine: `BRING-UP.md` runs EVERY stage on Portable #1** (reversed
  2026-09-07 — it previously sent stage 1 to the PowerBook 100). ⚠️ **So this
  step is preceded by desoldering `#1`'s PMGR** — the one Apple part in the
  project that cannot be replaced. Store it; do not fit it anywhere until the
  replacement is validated
- ⭐ The PowerBook 100 is fitted **last**, once the board is proven. It has never
  been powered and has no working sibling to compare against, so a failure there
  would not point at anything
- ⛔⛔ **On the PowerBook 100, do the `MEASUREMENTS.md` 2.67 TEST-POINT MAPPING
  before this step.** Sony's `TP001`–`TP072` are unmarked on the board and no
  locations drawing exists, so the only way to find them is to buzz from `U22`'s
  bare pads — which this step covers over permanently. ⭐ Map **57 `PMGR_PWM`**
  first, then `37`, `42`, `33`. Photograph what you find. ⚠️ Skipping it leaves
  that machine with no probe access you can locate, for good

### Check before stacking

- ⭐⭐ **Continuity, interposer castellation → the machine's own nets**, using the
  table this project measured: castellation **1** = `VIAD4`; **17, 23, 53** = GND;
  **45, 55, 56** = +5 V always-on (2.64)
- ⛔ **Adjacent castellations not bridged.** 0.5 mm pitch, 60 of them

---

## Step 5 — Stack

```
  MCU board      DF12NC-50DS socket, facing DOWN   (B.Cu)
        |
  interposer     DF12NC-50DP header, facing UP     (F.Cu)
        |
  logic board
```

⭐ The mate is **pin 1 to pin 1** and the boards' coordinate frames align
directly — confirmed from the board files, not assumed. The MCU board's long
face lands over **side D** (pins 46–60).

⚠️ **The debug breakout goes between interposer and MCU board**, and adds **3 mm**.
⛔ **Not on the PowerBook 100** — its CPU daughterboard leaves 9–10 mm and the
stack with the breakout is ~12 mm. See `breakout/README.md`.

---

## Step 6 — First power-on

⛔ **Go to `BRING-UP.md` stage 1.** Do not skip to booting.

⚠️ **≤ 6.5 V on the bench** while any original M50753 is in the machine
(`BENCH-CAPTURE.md`). ⭐ Not a constraint for a board carrying only the
replacement, but the habit is correct.

⭐⭐ **The first number worth having is `ref5V`** — `MEASUREMENTS.md` 2.64/2.65
predicts **~126** if the M50753's input current was the load, or **~113** if the
leakage is on the board. ⛔ Measure it against a DMM-derived expectation, never
against what the AVR itself reports.

---

## What this document does not yet cover

- ⚠️ **Whether you have two-sided stencil and reflow capability.** 5 bottom-side
  parts including a 0.5 mm-pitch 50-position connector is not hand-solder work.
- ✅ ~~Which UPDI programmer~~ — **settled**: XGecu `T48` (UPDI-capable) plus a
  CH340E serial adapter. ⚠️ Neither gives a hardware debugger; the `DBG` pins on
  `J2` are the substitute, and the firmware was written that way.
- ✅ ~~Rework plan if `U1` is misplaced~~ — **written**, in Step 1. Short version:
  tack two opposite corners, stop and inspect, then commit; removal is bad enough
  on this board that prevention is the plan.

---

## ⭐ Building a SECOND MCU board for the PowerBook 100 — J2 must not be a vertical header

**Why this is its own note (2026-09-16).** The PowerBook 100 is the last machine to receive a board, and the operator plans a
**second MCU board** for it so Portable #1 keeps the one that is validated. The stack fits there - interposer + `DF12` + MCU is
**6.2 mm** against **10.4 mm** available (`design/TWO-MACHINES.md`) - but that leaves **~4.2 mm** of headroom, and a standard
2.54 mm **vertical** `J2` is about **8.5 mm** tall (≈2.5 mm of body plus ≈6 mm of pin). ⛔ **On the PB100 the header, not the board,
is what would hit the CPU daughterboard.**

```
  option A  ⭐ NO HEADER: fine wires soldered straight to the J2 pads, dressed sideways   lowest profile, the operator's choice
            keep them long enough to reach a Tigard outside the case; strain-relieve at the board, they are the only UPDI and
            DBG0/1/2 access the PB100 has (no J21, no breakout there - TWO-MACHINES)
  option B  right-angle 2x3 header: ~3 mm above the board, length goes sideways          check the exit direction has room for the
            header AND a plug boot (another 10-15 mm), against the measured per-side clearances
  option C  vertical header                                                              ⛔ do not fit on the PB100 board
```

⚠️ **Whichever is used, the tails underneath must be flush.** `J2` is through-hole on a board with a **3.0 mm gap beneath it**
(the `DF12` stack); protruding tails foul it and can hold the board a fraction proud while it still feels seated - the unresolved
item from 2.83. Solder from the top where possible, trim flush, and check the underside before stacking.

⭐ **Leave Portable #1's board alone.** Its `J2` is fitted and working; changing it means desoldering six pins from the only
validated assembly. Build the difference into the second board instead.

⚠️ **Measure, do not trust this note's numbers:** the height of the actual part, and the free height above the MCU board once the
stack is in the PB100 with its CPU board in place.

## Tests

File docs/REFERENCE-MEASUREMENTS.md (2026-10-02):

# Reference measurements

Known-good values to check your machine against. Everything here was **measured on our own two
Portables**: one fitted with this replacement, and one **unmodified** (original hybrid, original
M50753), which is the reference for anything the hybrid produces.

⚠️ One unmodified machine is a small sample. Expect your readings to differ by tens of millivolts;
a difference of tenths of a volt is worth looking into.

⛔ **On a machine with the ORIGINAL M50753, keep the battery input at or below 6.5 V while probing.**
Its battery-sense pin is unprotected.

## Pin references

**M50753 (U15H) — all 60 leads.** Pin 1 is the filled white dot, lowest lead on the right;
numbering runs counter-clockwise, confirmed by continuity on the board. Each lead is labelled with
its signal and the J21 pin it reaches.

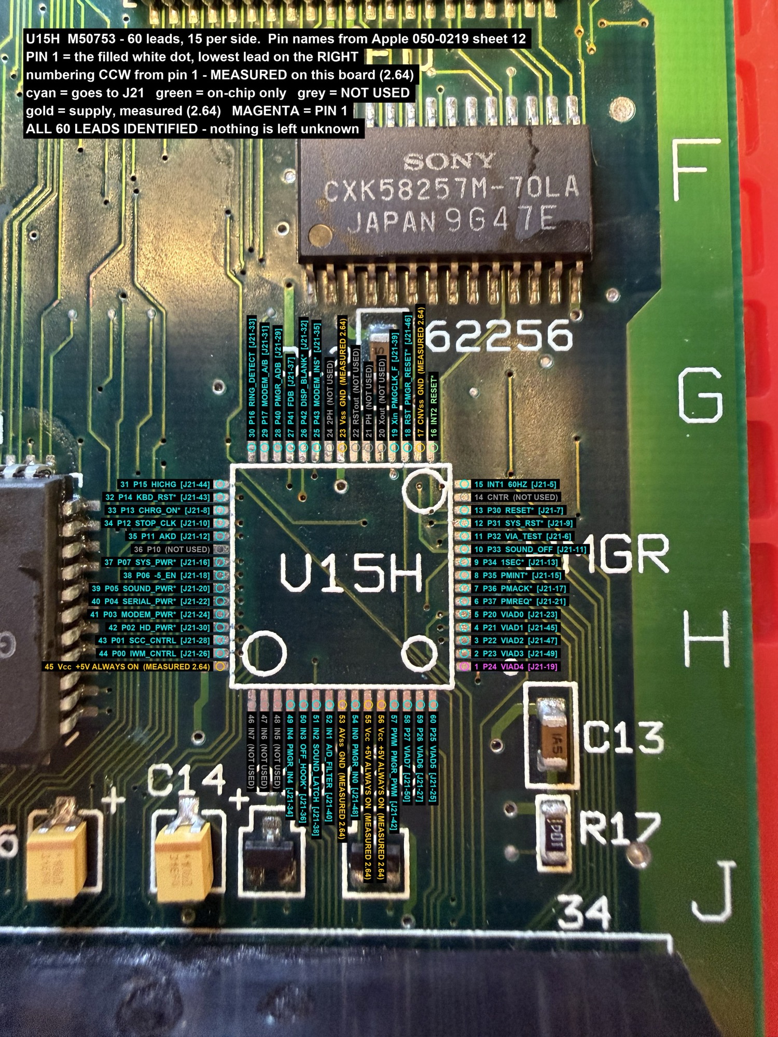
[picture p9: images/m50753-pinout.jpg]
M50753 pinout


**J21 — the 50-pad diagnostic connector** (2 × 25, 1 mm pitch). Bottom row odd, top row even;
**pin 1 is the square pad at the left.** ⚠️ The silkscreen "1" below the pads belongs to J22, not
J21. Each pad shows its signal and the M50753 pin it comes from. The J21 breakout board brings all
of these out to 2.54 mm headers with the same numbers.

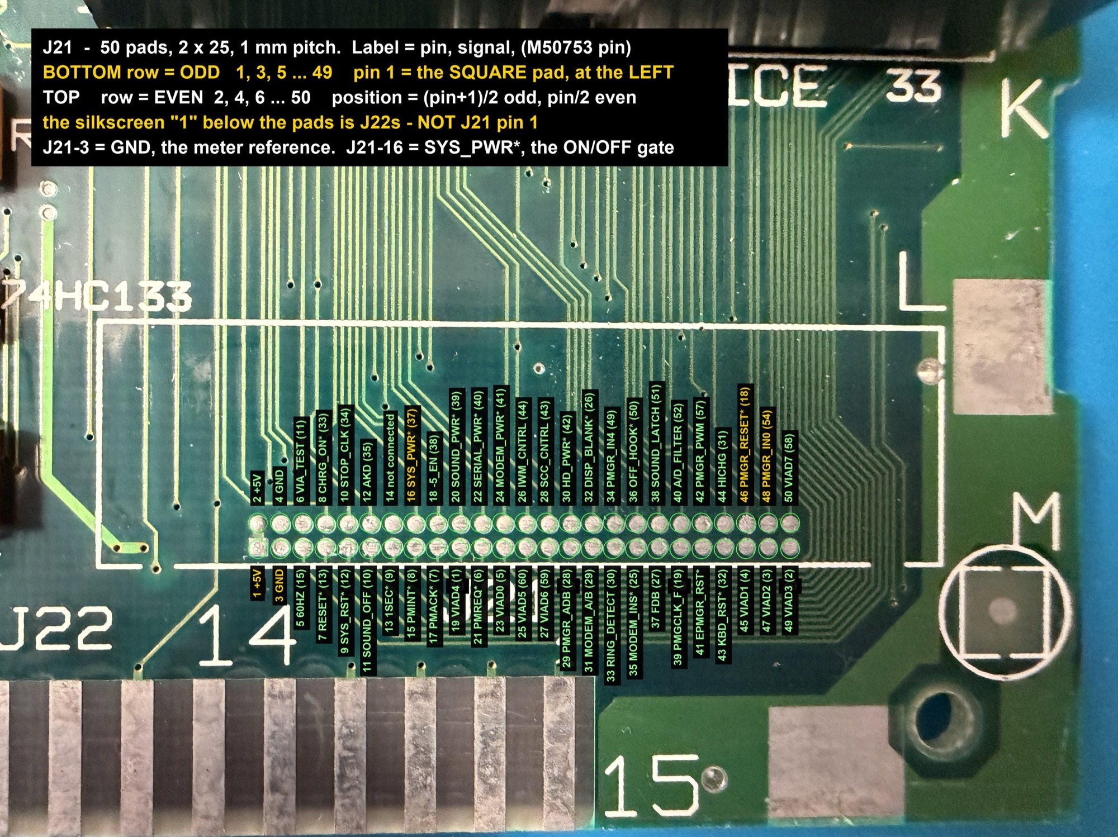
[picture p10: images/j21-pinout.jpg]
J21 pinout


**The bare footprint, for fitting the interposer.** The three circles are an **orientation key, not
pin 1** — the chip carries the same three marks, so they fix rotation only. Pin 1 is the white dot.

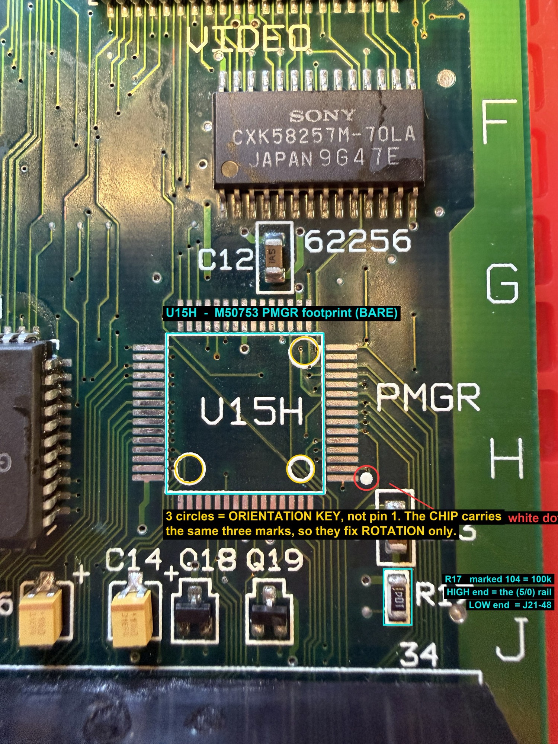
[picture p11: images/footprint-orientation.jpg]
Footprint orientation


**AVR128DB64 (U1 on the MCU board)** — every signal pin, with the M50753 pin and J21 pin it
stands in for. Generated from the MCU board file and checked against the firmware's pin header.

| AVR pin | port | signal | M50753 pin | J21 pin |
|---:|:--|:--|---:|---:|
| 1 | `PA3` | VIAD3 | 2 | 49 |
| 2 | `PA4` | VIAD4 | 1 | 19 |
| 3 | `PA5` | VIAD5 | 60 | 25 |
| 4 | `PA6` | VIAD6 | 59 | 27 |
| 5 | `PA7` | VIAD7 | 58 | 50 |
| 8 | `PB0` | PMREQ* | 6 | 21 |
| 9 | `PB1` | PMACK* | 7 | 17 |
| 10 | `PB2` | PMINT* | 8 | 15 |
| 11 | `PB3` | SYS_RST* | 12 | 9 |
| 12 | `PB4` | RESET* | 13 | 7 |
| 13 | `PB5` | PMGR_RESET* | 18 | 46 |
| 14 | `PB6` | VIA_TEST | 11 | 6 |
| 15 | `PB7` | 1SEC* | 9 | 13 |
| 16 | `PC0` | SOUND_LATCH | 51 | 38 |
| 17 | `PC1` | OFF_HOOK* | 50 | 36 |
| 18 | `PC2` | 60HZ | 15 | 5 |
| 22 | `PC4` | PMGCLK_F | 19 | 39 |
| 26 | `PD0` | A/D_FILTER | 52 | 40 |
| 27 | `PD1` | PMGR_ADB | 28 | 29 |
| 28 | `PD2` | FDB | 27 | 37 |
| 29 | `PD3` | DISP_BLANK* | 26 | 32 |
| 30 | `PD4` | MODEM_INS* | 25 | 35 |
| 31 | `PD5` | SOUND_OFF | 10 | 11 |
| 32 | `PD6` | PMGR_PWM | 57 | 42 |
| 33 | `PD7` | PMGR_IN0 | 54 | 48 |
| 36 | `PE0` | AKD | 35 | 12 |
| 37 | `PE1` | STOP_CLK | 34 | 10 |
| 38 | `PE2` | CHRG_ON* | 33 | 8 |
| 39 | `PE3` | KBD_RST* | 32 | 43 |
| 40 | `PE4` | HICHG | 31 | 44 |
| 41 | `PE5` | RING_DETECT | 30 | 33 |
| 42 | `PE6` | MODEM_A/B | 29 | 31 |
| 47 | `PF3` | debug pad — ADC scale check passed | — | — |
| 48 | `PF4` | debug pad — ADC timeout (latched) | — | — |
| 49 | `PF5` | debug pad — RTC/PIT sync timeout | — | — |
| 52 | `PG0` | SYS_PWR* | 37 | 16 |
| 53 | `PG1` | -5_EN | 38 | 18 |
| 54 | `PG2` | SOUND_PWR* | 39 | 20 |
| 55 | `PG3` | SERIAL_PWR* | 40 | 22 |
| 58 | `PG4` | MODEM_PWR* | 41 | 24 |
| 59 | `PG5` | HD_PWR* | 42 | 30 |
| 60 | `PG6` | SCC_CNTRL | 43 | 28 |
| 61 | `PG7` | IWM_CNTRL | 44 | 26 |
| 62 | `PA0` | VIAD0 | 5 | 23 |
| 63 | `PA1` | VIAD1 | 4 | 45 |
| 64 | `PA2` | VIAD2 | 3 | 47 |

- **Not wired to the AVR:** J21-34 `PMGR_IN4` (M50753 pin 49 — an input the original firmware does
  not read) and J21-41 `EPMGR_RST*` (belongs to the J21 connector, not to the chip).
- **Power and programming pins** (VDD, AVDD, VDDIO2, ground, UPDI, RESET) are in
  [`MCU-BOARD-SCHEMATIC.md`](MCU-BOARD-SCHEMATIC.md).
- All eight VIA data bits sit on `PORTA`, so a bus read is a single instruction — the handshake
  timing depends on it.

The full pin-by-pin mapping, through the interposer to the AVR, is in [`PINOUT.md`](PINOUT.md).

### Footprint checks — power OFF, before fitting anything
```
  M50753 pins 45, 55, 56  ->  J21-1   +5 V always-on      ~0.1 Ω
  M50753 pins 17, 23, 53  ->  J21-3   ground              ~0.0-0.1 Ω
  M50753 pin 54           ->  R17, the end nearer J21-48  ~0.2 Ω   (confirms the pin numbering)
```

## Healthy voltages — unmodified machine

Battery input set to **6.41 V at the pack connection** (by DMM), machine **off and not booted**,
charger and programmer disconnected, **ground at battery negative**.

```
  hybrid pin 16, 17           battery input path      6.41 V   (= the input)
  hybrid pin 19               charger status          5.15 V
  hybrid pin 22               Q1 control              6.33 V   (Q1 gate 6.32 V -> Q1 OFF)
  hybrid pin 37               -5 V enable             ~4 mV
  hybrid pin 39               HICHG                   ~3 mV
  J21-1                       +5 V always-on rail     5.2 V    (measured with 5.70 V in)
  J21-40                      battery sense (A/D)     ~2.61 V  (from the line below)
```

⚠️ **Hybrid pin numbers are their own numbering** — not J21 numbers and not M50753 pins. Match
points by signal name. For where the hybrid's pins are, and for readings from a **replacement
hybrid**, see the documentation from **Androda**, who makes one.

**Q1** is the IRF9Z30 P-channel MOSFET beside the charger jack: the **fast-charge bypass** across
R10 (100 Ω). On, it gives the low-resistance charge path; off, charging continues through R10.
Its gate is driven by hybrid pin 22.

## Battery sense — what the PMGR sees

On the unmodified machine, the voltage at the PMGR's battery-sense input follows the pack:

```
  A/D_FILTER = (V_pack - 5.1249) x 2.0324        11 pairs, scatter 8 mV

  pack 5.90 V  ->  ~1.58 V      pack 6.41 V  ->  ~2.61 V      pack 7.20 V  ->  ~4.22 V
```

Hybrids differ: another machine read **tenths of a volt** lower at the same pack voltage. That
spread is why each board gets its own calibration record ([`BUILD.md`](BUILD.md) §7).

## The firmware's battery levels

The same levels as the original, applied to the calibrated reading:

```
  level         ROM value (pmuv1.bin)                  calibrated   what it does
  knee          208  literal compare, cmp #720-512     7.20 V       below it, fast charge runs; crossing it starts the top-off timer
  LOW           78   lowBatteryLevel  = 590-512        5.90 V       the low-battery condition the Mac warns about
  STAY_ASLEEP   70   computed: (78>>1) + (62>>1)       5.82 V       below it, the machine can no longer be woken
  DEAD          62   deadBatteryLevel = 574-512        5.74 V       the PMGR puts the machine to sleep itself
```

The **values** are Apple's, read from the original M50753 firmware; the ROM stores no voltages.
The **voltages** are our calibration of those values on an unmodified Portable (original PMGR
and original hybrid). `HICHGLevel` (200) is a separate stored setting, not the knee.

## Cut-off

The unmodified machine's hybrid **cuts off between 5.61 and 5.70 V** at the battery input, and
comes back on at the next step up — essentially no hysteresis. If your machine dies well above
this, suspect the hybrid or the battery wiring before the PMGR.

## Charging — measured on the development machine

<picture>
  <source media="(prefers-color-scheme: dark)" srcset="../images/charge-curve-dark.png">
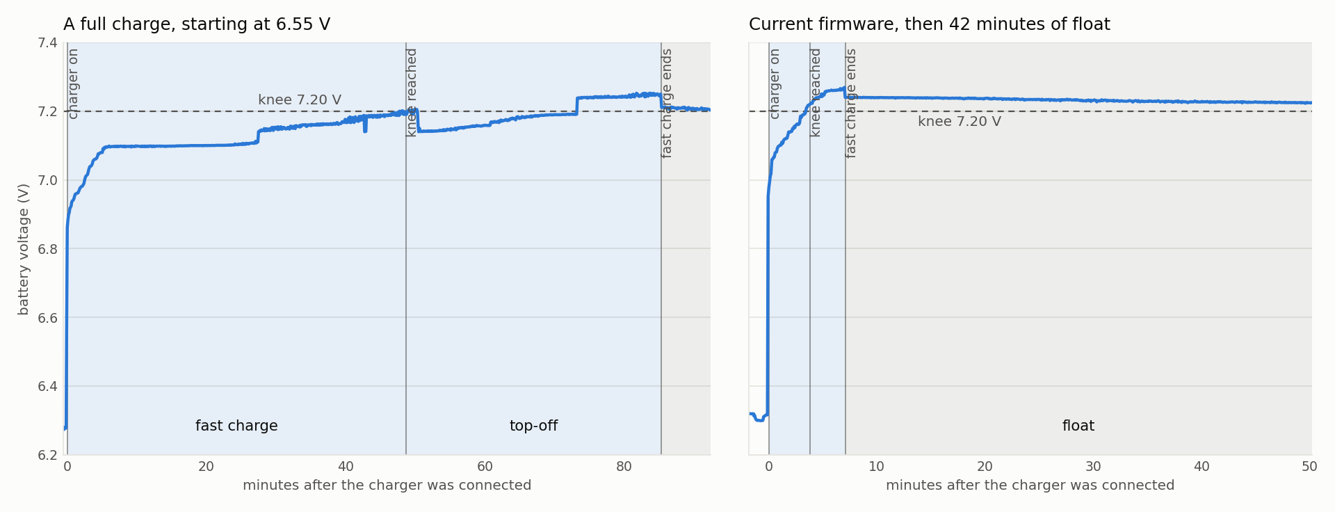
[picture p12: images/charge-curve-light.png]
Battery voltage through two supervised charges: fast charge climbs to the 7.20 V knee, the top-off timer runs, fast charge ends, and the pack floats
  
</picture>

**Left:** a full charge from 6.55 V — fast charge climbs to the knee, the top-off timer then runs
for a further ~37 minutes, and fast charge ends. **Right:** the current firmware, starting close to
the knee, then 42 minutes of float. The left run used the firmware before the battery-reading
interlock was added; the charging logic is otherwise the same. Phases are read from the PMGR's own
flags; the knee marker is where its reported level reached 208 (7.20 V).

> ⚠️ **Not yet confirmed as normal.** Two features of these curves may come from **this particular
> machine** — its **replacement hybrid** or its **logic board** — rather than from a healthy charger:
>
> - **The drop when fast charge ends is small** — about 40 mV. When a charger genuinely falls back to
>   a trickle, the pack voltage should fall noticeably.
> - **The float level is high** — about 7.23 V, or 2.41 V per cell, where the Cyclon float band is
>   2.25–2.30 V per cell (6.75–6.90 V). Held there for long periods, a lead-acid pack ages faster.
>
> The **step changes** in the left panel (around 27, 50 and 73 minutes) are probably the Mac's own
> power use changing while it ran, since the charger supplies both the machine and the pack. That
> has not been checked.
>
> Use the **sequence** — fast charge, knee, top-off, termination — as the reference. Treat the
> **float level** as unconfirmed until it has been measured on a machine with an original hybrid.

A 3-cell Cyclon pack, the machine's own charger, two supervised charges:

```
  fast charge crosses the knee at      7.198 V / 7.220 V
  fast charge terminates at            7.211 V / 7.240 V
  highest pack voltage seen            7.252 V / 7.269 V
  float, 42 min after termination      ~7.23 V  (one observation, voltage only)
```

A DMM at the pack agreed with the logged readings to about 15 mV.

### 🔧 Under active investigation

On the development machine, the fast-charge bypass transistor **Q1** (the IRF9Z30 beside the
charger jack) is held **on** by the replacement hybrid even with no charger connected; on the
unmodified machine it is off. If Q1 also stays on **after fast charge ends**, charging would never
fall back to the slow path through R10 — which would explain both the small termination drop and
the high float above.

**The cause is not yet known, and it may be this machine's logic board rather than the hybrid.**
The board was repaired after earlier damage. The checks so far found Q1's gate pull-up intact and
every line the PMGR drives normal, but they do not rule the board out. It is being followed up with
the hybrid's maker in parallel. Planned checks:

1. **Q1's gate-to-source voltage during fast charge, then again after it ends.** Still about −5 V
   afterwards would mean Q1 never turns off.
2. **The same charge on a machine with an original hybrid**, for a normal curve to compare against.
3. **Charge current through the whole cycle**, with a DC clamp meter — never yet measured.

Results will be added here. If you have a Portable with an original hybrid, a logged charge with
the pack voltage at termination would help.

## Board checks

```
  AVR device ID (pymcuprog ping)       1E970B
  standby current, Mac switched off    ~10 mA  (13 mA from cold)
  DBG2 high, DBG1 low                  healthy ADC   (see ../firmware/README.md)
```

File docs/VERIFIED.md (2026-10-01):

# What has been verified

Everything below was measured on a **Macintosh Portable M5120 fitted with this replacement**, against
a second, **unmodified Portable** used as the reference. **It has not been installed in any other model**
— not the backlit Portable (M5126), and not the PowerBook 100. One machine is a small sample: treat these as
"shown to work here", not "guaranteed to work everywhere".

## ✅ Shown on hardware

**The Mac runs normally.**
- Cold boot, sleep and wake (by keypress), the reset switch, and shutdown — all behave as on the
  original, under **System 6.0.8 and 7.5.3**.
- The soft-reset command parks the machine exactly as the original does; a keypress then boots it.
- The ROM read-back the Mac performs answers correctly (with the synthetic image).
- PRAM is read, written and saved. Host writes to the battery thresholds are stored but not acted
  on — which is what the original chip does too, and was reproduced deliberately.

**Battery sensing.**
- Each machine's hybrid reads the battery slightly differently, so each unit gets a **16-byte
  calibration record** in EEPROM. On the development machine the fitted line held to about
  1.2 ADC counts across a 0.9 V sweep, and to about 0.6 counts on a later, independent battery test.
- **Without a valid record, fast charge is disabled** — confirmed: no fast-charge assertion in 36 of
  36 samples on a board with the record removed. Charging still continues on the slow path.

**Charging.**
- A supervised fast charge on a 3-cell Cyclon pack **entered fast charge, crossed the knee at about
  7.20 V, and terminated** — shown twice, once before and once after the battery-reading interlock
  was added.
- With the interlock, across a full charge and 42 minutes of float that followed, fast charge
  switched off **once**, at the expected point, with no unexpected transitions in 702 decoded samples.

**Other.**
- Current drawn with the Mac switched off: **about 9–11 mA**.
- A cursor flicker seen under 7.5.3 was traced to a system extension, not the PMGR: it disappears
  with extensions off, under 6.0.8, and appears on the unmodified machine too.
- Eight host-side unit-test suites cover the protocol, PRAM save, ADC handling, calibration and the
  charging state machine.

## Deliberate differences from the original

**PRAM survives power removal.** The original keeps PRAM in the chip's RAM, so taking all power away
clears it. This replacement keeps PRAM in the AVR's EEPROM, so it **comes back after the battery has
been pulled.** The clock still behaves like the original: a power loss zeroes it, and the Mac forgets
the date. (Keeping the clock in EEPROM was not an option — writing it every second would wear the
EEPROM out in about a day.)

| PRAM recovery | works? |
|---|---|
| `Cmd-Opt-P-R` at startup | ✅ unchanged |
| blank or corrupt PRAM — the Mac reinitialises it | ✅ unchanged |
| **pulling the battery / removing all power** | ⛔ **no longer clears PRAM** |

The case that is lost is narrow: PRAM that *looks* valid but holds settings that stop the Mac
booting. The fix is then the programmer, not the battery — see "Resetting PRAM" in
[`PROGRAMMING.md`](PROGRAMMING.md).

## ⚠️ Not yet shown — read this before relying on it unattended

- **Charge current has never been measured.** The voltages behave correctly, but the actual current
  profile through a charge is unknown.
- **Float is a single 42-minute observation**, voltage only. In it the pack stayed near 7.23 V
  (about 2.41 V per cell, above the Cyclon float band). Whether that settles lower, and what current
  sustains it, is not known — and it may reflect the development machine — its replacement hybrid or its logic
  board — rather than normal behaviour; see "Under active investigation" in
  [`REFERENCE-MEASUREMENTS.md`](REFERENCE-MEASUREMENTS.md).
- **What switching off fast charge mid-charge does to the current** has not been measured. The design
  assumes it reduces the rate; that is supported by one older observation, on a different battery.
- **A brief battery-reading fault during charging** would not necessarily show in the data that was
  logged; the firmware latches such faults on two test pads (`DBG1`, `DBG2`) for that purpose, but
  they have not yet been watched through a charge.
- **The fast-charge timer's top-off** does not run for exactly as long as the code predicts, by an
  amount that varies between runs. Charging still terminates; the discrepancy is unexplained.
- **Standby current of the original chip** has not been measured for comparison, so whether 9–11 mA
  is acceptable for a machine left unplugged for weeks is open.
- **The PowerBook 100** uses the same power manager and has not been tried.

## About the development machine

The development Portable carries a **third-party replacement hybrid** (the power-supply module the
PMGR works with). Compared with an original hybrid, that one cuts the machine off at a higher
battery voltage (about 5.94 V) and holds the fast-charge bypass transistor (Q1) switched on with no
charger connected. Both **appear not to come from this PMGR** — every PMGR-driven line measured the
same as on the original machine — but **neither is settled**. They may come from the hybrid, or from
that machine's **logic board**, which was repaired after earlier damage. Both possibilities are being
followed up, including with the hybrid's maker. They are
noted here because if your machine has a replacement hybrid, its charging and cut-off may differ
from an original's too.

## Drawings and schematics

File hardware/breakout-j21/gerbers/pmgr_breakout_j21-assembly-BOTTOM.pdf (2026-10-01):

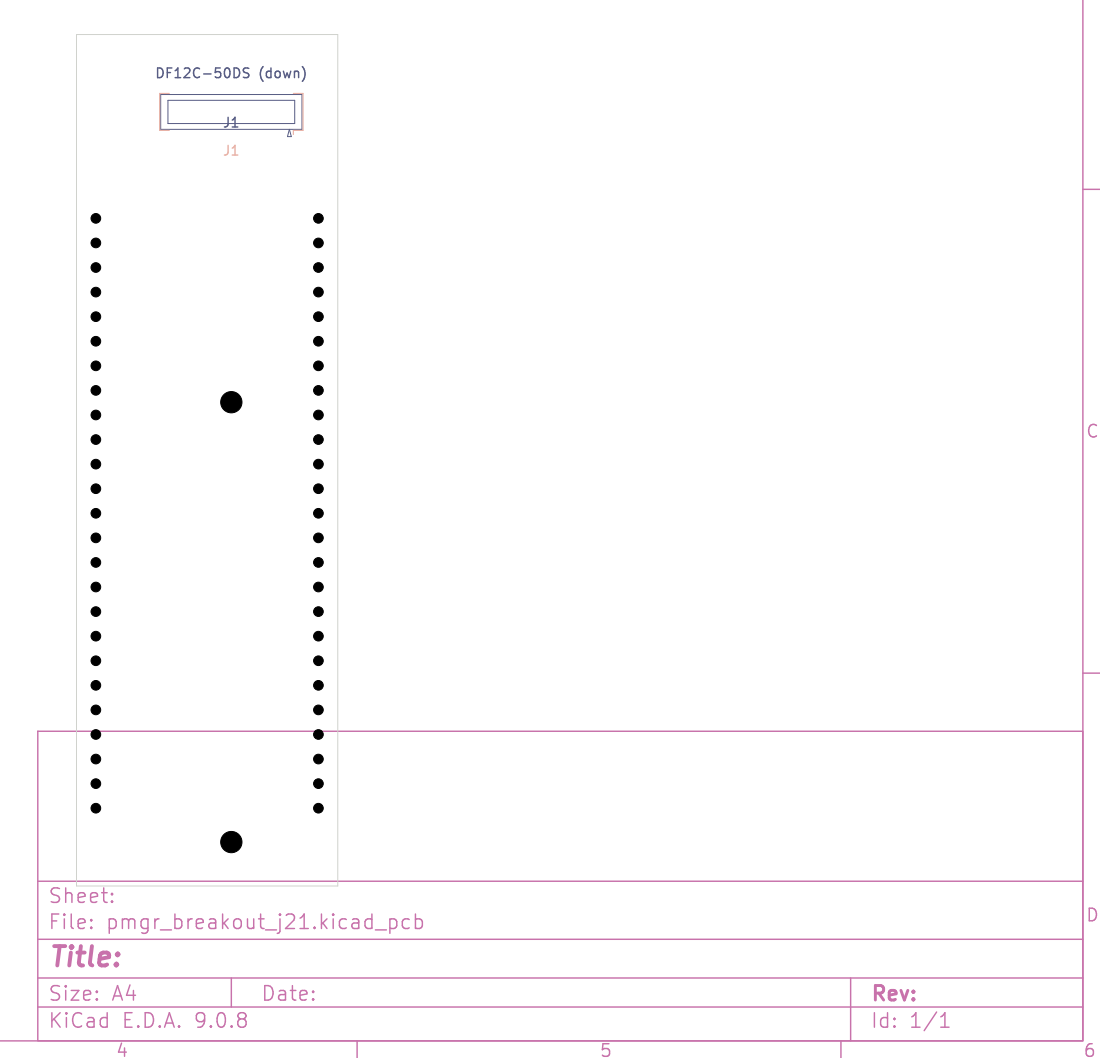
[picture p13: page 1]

Id: 1/1 Title: File: pmgr_breakout_j21.kicad_pcb Sheet:

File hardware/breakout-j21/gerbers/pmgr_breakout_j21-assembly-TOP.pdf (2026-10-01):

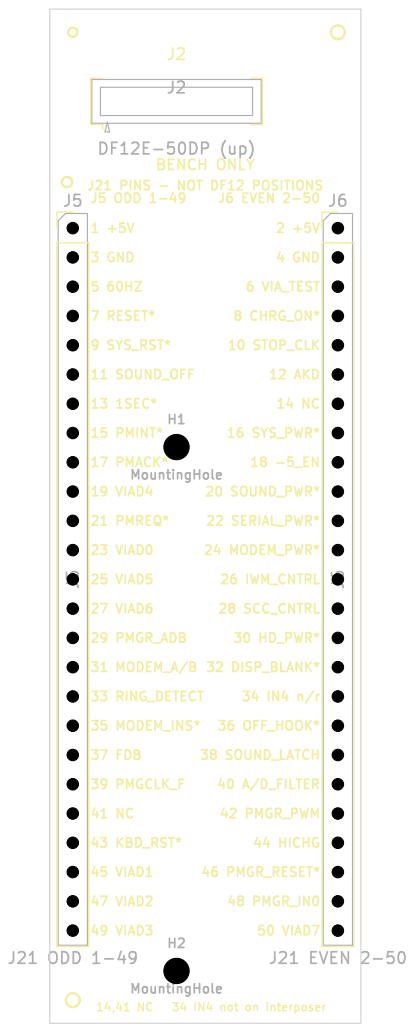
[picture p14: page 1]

Id: 1/1 Title: File: pmgr_breakout_j21.kicad_pcb Sheet:

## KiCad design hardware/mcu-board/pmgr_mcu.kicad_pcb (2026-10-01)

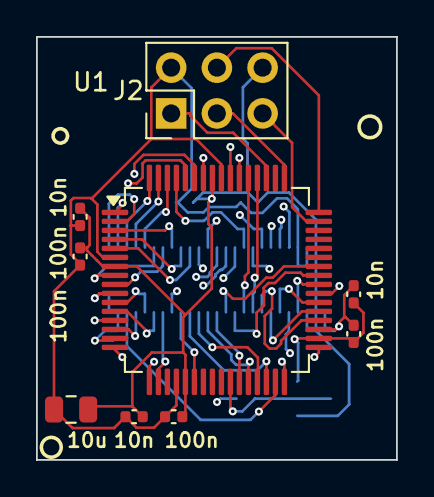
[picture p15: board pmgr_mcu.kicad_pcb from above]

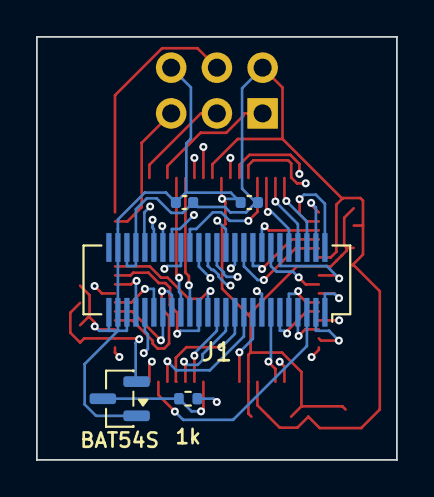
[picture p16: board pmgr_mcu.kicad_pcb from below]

Board: 4 copper layers, 20.0 x 23.5 mm, 14 parts (5 on the bottom side), 50 nets.

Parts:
C1, C2, C3, C4: 100nF; C_0402_1005Metric
C5, C6, C7, C9: 10nF; C_0402_1005Metric
C8: 10uF; C_0805_2012Metric
D1: BAT54S; SOT-23
J1: DF12C3.0-50DS; Hirose_DF12_DF12C3.0-50DS-0.5V_2x25_P0.50mm_Vertical
J2: UPDI; PinHeader_2x03_P2.54mm_Vertical
R1: 1k; R_0402_1005Metric
U1: AVR128DB64; TQFP-64_10x10mm_P0.5mm

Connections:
+5V: C1.1, C2.1, C3.1, C4.1, C5.1, C6.1, C7.1, C8.1, C9.1, D1.2, J1.47, J1.48, J2.2, U1.6, U1.20, U1.34, U1.56
ADC_IN: D1.3, R1.2, U1.26
AD_FILTER: J1.38, R1.1
AKD: J1.18, U1.36
CHRG_ON_N: J1.20, U1.38
DBG0: J2.3, U1.49
DBG1: J2.4, U1.48
DBG2: J2.5, U1.47
DISP_BLANK_N: J1.11, U1.29
FDB: J1.12, U1.28
GND: C1.2, C2.2, C3.2, C4.2, C5.2, C6.2, C7.2, C8.2, C9.2, D1.1, J1.23, J1.24, J1.25, J1.49, J2.6, U1.7, U1.21, U1.35, U1.57
HD_PWR_N: J1.43, U1.59
HICHG: J1.22, U1.40
IWM_CNTRL: J1.41, U1.61
KBD_RST_N: J1.21, U1.39
MINUS5_EN: J1.16, U1.53
MODEM_AB: J1.14, U1.42
MODEM_INS_N: J1.10, U1.30
MODEM_PWR_N: J1.44, U1.58
OFF_HOOK: J1.40, U1.17
ONESEC_N: J1.2, U1.15
PMACK_N: J1.32, U1.9
PMGCLK_F: J1.9, U1.22
PMGR_ADB: J1.13, U1.27
PMGR_IN0: J1.37, U1.33
PMGR_PWM: J1.36, U1.32
PMGR_RESET_N: J1.8, U1.13
PMINT_N: J1.1, U1.10
PMREQ_N: J1.31, U1.8
RESET_N: J1.6, U1.12
RING_DETECT: J1.15, U1.41
SCC_CNTRL: J1.42, U1.60
SERIAL_PWR_N: J1.45, U1.55
SIXTYHZ: J1.7, U1.18
SOUND_LATCH: J1.39, U1.16
SOUND_OFF: J1.3, U1.31
SOUND_PWR_N: J1.46, U1.54
STOP_CLK: J1.19, U1.37
SYS_PWR_N: J1.17, U1.52
SYS_RST_N: J1.5, U1.11
UPDI: J2.1, U1.51
VIAD0: J1.30, U1.62
VIAD1: J1.29, U1.63
VIAD2: J1.28, U1.64
VIAD3: J1.27, U1.1
VIAD4: J1.26, U1.2
VIAD5: J1.33, U1.3
VIAD6: J1.34, U1.4
VIAD7: J1.35, U1.5
VIA_TEST: J1.4, U1.14

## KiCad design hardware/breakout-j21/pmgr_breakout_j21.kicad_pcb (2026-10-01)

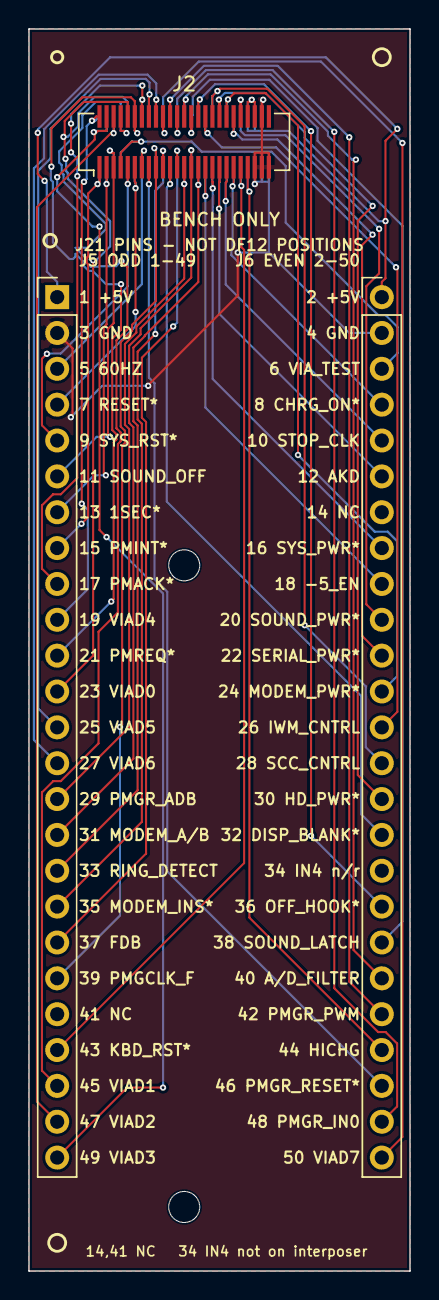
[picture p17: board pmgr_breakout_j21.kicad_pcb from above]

Board: 2 copper layers, 27.0 x 88.0 mm, 6 parts (1 on the bottom side), 45 nets.

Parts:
H1, H2: MountingHole; MountingHole_2.2mm
J1: DF12C-50DS (down); Hirose_DF12_DF12C3.0-50DS-0.5V_2x25_P0.50mm_Vertical
J2: DF12E-50DP (up); Hirose_DF12_DF12E3.0-50DP-0.5V_2x25_P0.50mm_Vertical
J5: J21 ODD 1-49; PinHeader_1x25_P2.54mm_Vertical
J6: J21 EVEN 2-50; PinHeader_1x25_P2.54mm_Vertical

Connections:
+5V: J1.47, J1.48, J2.47, J2.48, J5.1, J6.1
AD_FILTER: J1.38, J2.38, J6.20
AKD: J1.18, J2.18, J6.6
CHRG_ON_N: J1.20, J2.20, J6.4
DISP_BLANK_N: J1.11, J2.11, J6.16
FDB: J1.12, J2.12, J5.19
GND: J1.23, J1.24, J1.25, J1.49, J2.23, J2.24, J2.25, J2.49, J5.2, J6.2
HD_PWR_N: J1.43, J2.43, J6.15
HICHG: J1.22, J2.22, J6.22
IWM_CNTRL: J1.41, J2.41, J6.13
KBD_RST_N: J1.21, J2.21, J5.22
MINUS5_EN: J1.16, J2.16, J6.9
MODEM_AB: J1.14, J2.14, J5.16
MODEM_INS_N: J1.10, J2.10, J5.18
MODEM_PWR_N: J1.44, J2.44, J6.12
OFF_HOOK: J1.40, J2.40, J6.18
ONESEC_N: J1.2, J2.2, J5.7
PMACK_N: J1.32, J2.32, J5.9
PMGCLK_F: J1.9, J2.9, J5.20
PMGR_ADB: J1.13, J2.13, J5.15
PMGR_IN0: J1.37, J2.37, J6.24
PMGR_PWM: J1.36, J2.36, J6.21
PMGR_RESET_N: J1.8, J2.8, J6.23
PMINT_N: J1.1, J2.1, J5.8
PMREQ_N: J1.31, J2.31, J5.11
RESET_N: J1.6, J2.6, J5.4
RING_DETECT: J1.15, J2.15, J5.17
SCC_CNTRL: J1.42, J2.42, J6.14
SERIAL_PWR_N: J1.45, J2.45, J6.11
SIXTYHZ: J1.7, J2.7, J5.3
SOUND_LATCH: J1.39, J2.39, J6.19
SOUND_OFF: J1.3, J2.3, J5.6
SOUND_PWR_N: J1.46, J2.46, J6.10
STOP_CLK: J1.19, J2.19, J6.5
SYS_PWR_N: J1.17, J2.17, J6.8
SYS_RST_N: J1.5, J2.5, J5.5
VIAD0: J1.30, J2.30, J5.12
VIAD1: J1.29, J2.29, J5.23
VIAD2: J1.28, J2.28, J5.24
VIAD3: J1.27, J2.27, J5.25
VIAD4: J1.26, J2.26, J5.10
VIAD5: J1.33, J2.33, J5.13
VIAD6: J1.34, J2.34, J5.14
VIAD7: J1.35, J2.35, J6.25
VIA_TEST: J1.4, J2.4, J6.3

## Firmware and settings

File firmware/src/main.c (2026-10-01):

/* Macintosh Portable / PowerBook 100 Power Manager replacement.
 * Reimplements the M50753 PMGR on an AVR128DB64. See ../PROTOCOL-SPEC.md.
 */
#include "pmgr_pins.h"
#include "pmgr_bus.h"
#include "pmgr_proto.h"
#include "pmgr_handlers.h"
#include "pmgr_calib.h"
#include "pmgr_adb.h"
#include "pmgr_pram.h"
#include "pmgr_pwm.h"
#ifdef PMGR_SELFTEST
#include "pmgr_selftest.h"
#endif
#include "pmgr_adc.h"

#include <avr/interrupt.h>
#include <avr/cpufunc.h>
#include <util/delay.h>

/* The timebase is SIXTYHZ (PC2), not an internal timer. Apple's Int1 runs at
 * 60 Hz and 1SEC* is derived by dividing it by 60 (pmgr.asm 571-585). The
 * machine supplies that reference; generating our own would drift against it. */
/* PENDING 60 Hz ticks - a COUNTER, not a flag.
 *
 * A boolean loses ticks whenever two edges arrive before the main loop
 * services one, and the loop can exceed a 16.6 ms period: pmgr_poll() working
 * through a multi-byte reply allows PMGR_REQ_TIMEOUT_US (2 ms) per byte.
 *
 * Every lost tick is time the Mac never sees, because 1SEC* is DERIVED by
 * dividing this by 60 - the exact mirror of the fallback bug described below,
 * which gained ~96 min/day by injecting ticks. Losing them makes the clock run
 * slow instead.
 *
 * Saturates rather than wrapping: if we are ever starved for four seconds
 * something is badly wrong, and wrapping to 0 would silently discard 256 ticks.
 * Replay is cheap - a divider decrement and, once per 60, a 5 us pulse. */
#define TICK_MAX  255u
static volatile uint8_t s_tick;

/* Fallback arming counter, in PIT periods since the last real SIXTYHZ edge.
 *
 * The PIT runs at 64 Hz and SIXTYHZ at 60 Hz, so the PIT is FASTER: four times
 * a second a PIT period legitimately contains no SIXTYHZ edge. An earlier
 * revision treated any such gap as "SIXTYHZ is dead" and injected a tick,
 * producing 64 ticks/s into the /60 divider - a 1SEC* of 1.0667 Hz, gaining
 * about 96 minutes a day on the Mac's clock while SIXTYHZ was perfectly fine.
 *
 * Requiring several CONSECUTIVE silent periods fixes it: 4 PIT periods is
 * 62.5 ms against a 16.7 ms SIXTYHZ period, so ~46 ms of margin. */
#define SIXTYHZ_LOST_PERIODS  4u
#define SIXTYHZ_TIMEOUT_CAP   8u

static volatile uint8_t s_sixtyhz_timeout;

#ifdef PMGR_PARK_SLEEP
volatile bool g_parked, g_park_edge, g_park_pit;
#endif

ISR(PORTC_PORT_vect)
{
    PORTC.INTFLAGS = SIXTYHZ_bm;        /* clb Int1_Req equivalent */
#ifdef PMGR_PARK_SLEEP
    if (g_parked) { g_park_edge = true; return; }    /* the park counts it by hand */
#endif
    if (s_tick < TICK_MAX) s_tick++;
    s_sixtyhz_timeout = 0;              /* the real source is alive */
}

/* Fallback tick, for a bench board with no host supplying SIXTYHZ. Stands down
 * automatically as soon as real edges reappear. In fallback the rate is the
 * PIT's 64 Hz, so 1SEC* runs ~6.7% fast - fine for bench work, and never used
 * when a machine is attached. */
ISR(RTC_PIT_vect)
{
    RTC.PITINTFLAGS = RTC_PI_bm;
#ifdef PMGR_PARK_SLEEP
    if (g_parked) { g_park_pit = true; return; }
#endif

    if (s_sixtyhz_timeout < SIXTYHZ_TIMEOUT_CAP)
        s_sixtyhz_timeout++;

    if (s_sixtyhz_timeout >= SIXTYHZ_LOST_PERIODS) {
        if (s_tick < TICK_MAX) s_tick++;
    }
}

static void clock_init(void)
{
    /* Internal 24 MHz - no crystal. PA0/PA1 are XTALHF but carry VIAD0/VIAD1. */
    ccp_write_io((void *)&CLKCTRL.OSCHFCTRLA, CLKCTRL_FRQSEL_24M_gc);
    ccp_write_io((void *)&CLKCTRL.MCLKCTRLB, 0);
}

static void tick_init(void)
{
    SIXTYHZ_PORT.PIN2CTRL = PORT_ISC_FALLING_gc;        /* PC2 falling edge */

    /* ⛔ BOUNDED, for the same reason as the ADC poll (see pmgr_adc.c).
     * tick_init() runs BEFORE the cold-entry dispatch, so an RTC that never
     * clears STATUS would hang here and leave the Macintosh held in reset -
     * a dead board with no indication why.
     *
     * The consequence of giving up is mild and worth taking: the PIT is only
     * the FALLBACK tick for a bench board with no host. The real timebase is
     * SIXTYHZ on PC2, configured above and unaffected. So on timeout we skip
     * the PIT and carry on rather than refusing to boot the machine. */
    for (uint16_t us = 0; us < 2000u && RTC.STATUS > 0; us++)
        _delay_us(1);

    if (RTC.STATUS == 0) {
        RTC.CLKSEL     = RTC_CLKSEL_OSC32K_gc;
        RTC.PITINTCTRL = RTC_PI_bm;
        RTC.PITCTRLA   = RTC_PERIOD_CYC512_gc | RTC_PITEN_bm;   /* 64 Hz fallback */
    } else {
        /* No PIT. SIXTYHZ still drives everything when a host is attached;
         * only a host-less bench board loses its fallback tick. DBG0 is the
         * one free debug pin in the normal build - see pmgr_adc.c. */
#ifndef PMGR_LOOP_MARKER            /* marker builds own DBG0 */
        DBG0_PORT.DIRSET = DBG0_bm;
        DBG0_PORT.OUTSET = DBG0_bm;
#endif
    }
}

/* PMGR_RESET* (PB5) is wired to the M50753's own RESET pin on the original
 * board, so asserting it holds the chip in reset and releasing it lands at
 * PMGRResetEntry -> ColdEntry.
 *
 * ⭐ IT IS A LEVEL, NOT AN EDGE. While RESET is low the original executes
 * NOTHING. An earlier revision here treated it as an edge - software-reset the
 * AVR on seeing PB5 low - which was wrong in two compounding ways:
 *
 *   1. after the self-reset the AVR immediately ran again even with PB5 still
 *      low, so a long assertion let the replacement execute substantial
 *      firmware while the original would still be physically held;
 *   2. this service sits at the BOTTOM of the main loop, so each self-reset was
 *      followed by a full cold init - including the park-or-release decision -
 *      before PB5 was looked at again. A held reset therefore produced a reset
 *      LOOP that toggled SYS_RST* at the machine on every pass.
 *
 * Correct behaviour is to WAIT, not to retrigger: hold the machine down and
 * spin until the pin is released, then take one clean cold entry.
 *
 * Nothing is serviced during the wait - no tick, no timekeeping. That is
 * faithful: a chip held in reset does not count seconds either, and the
 * .noinit clock correctly resumes from where it stopped.
 *
 * Distinct from RESET (PB4), the front-panel reset SWITCH, which vectors to
 * Reset_Interrupt and exits via ResetEntry - that one always releases the
 * machine. Same word, two signals, opposite outcomes. */
static void pmgr_reset_pin_wait(void)
{
    if (!PIN_IS_LOW(PMGR_RESET_N_PORT, PMGR_RESET_N_bm))
        return;

    /* Hold the 68000 down for as long as we are held down. */
    ASSERT_LOW(SYS_RST_N_PORT, SYS_RST_N_bm);

    while (PIN_IS_LOW(PMGR_RESET_N_PORT, PMGR_RESET_N_bm))
        { /* held in reset - execute nothing, exactly as the M50753 would */ }
}

/* Asserted while running: hold as above, then take ONE cold entry on release,
 * which is what the release of a real RESET pin does. */
static void pmgr_reset_pin_service(void)
{
    if (!PIN_IS_LOW(PMGR_RESET_N_PORT, PMGR_RESET_N_bm))
        return;

    pmgr_reset_pin_wait();                          /* returns once released */
    /* ⭐ Finish any outstanding PRAM save before the restart (MEASUREMENTS
     * 2.156). The machine is held, so blocking here serves no one less. An
     * unfinished save would be safe anyway (the old slot loads) but would
     * lose the change. */
    (void)pmgr_pram_flush();          /* bounded; proceed either way (2.184) */
    _PROTECTED_WRITE(RSTCTRL.SWRR, RSTCTRL_SWRST_bm);
    for (;;) { }                                    /* not reached */
}

int main(void)
{
    clock_init();

    pmgr_bus_init();
    pmgr_proto_init();
    pmgr_handlers_init();       /* InitPorts: SYS_RST* asserted, machine held */

    /* ⭐ PMGR_RESET* IS A LEVEL. Do not proceed past reset-state
     * initialisation while it is still asserted - see pmgr_reset_pin_wait().
     *
     * Placed HERE, immediately after the ports are configured, because that is
     * the earliest point at which SYS_RST* is asserted and the machine is
     * safely held. Waiting any later would let us initialise ADB, PRAM, the
     * ADC and the PWM while the original M50753 would still be doing nothing
     * at all. Waiting any earlier would spin with the ports undefined. */
    pmgr_reset_pin_wait();

    pmgr_adb_init();
    pmgr_pram_init();

    /* ⭐ Entry2, pmgr.asm 138-166 - and it runs on THIS path too, not just the
     * reset switch: ColdEntry and ResetEntry both `bra Entry2`. Without it a
     * cold boot never tests the PRAM checksum at all, so corrupt PRAM is
     * loaded and kept.
     *
     * ORDER DIVERGES FROM THE ORIGINAL, deliberately. Apple runs Entry2 BEFORE
     * InitPorts; we configure the ports first (above) so SYS_RST* is asserted
     * and the machine is safely held before anything else happens, and our
     * PRAM must be loaded from EEPROM before it can be checksummed - the
     * original's is just RAM that is already there. The two touch disjoint
     * state (ports vs RAM), so the swap is safe; the one thing that does span
     * both, the Port_P0 value, is chosen inside pmgr_ports_init(). */
    pmgr_entry_state();

    /* ⛔⛔ LOAD THE CALIBRATION RECORD. Without this call s_valid is permanently
     * false, so EVERY board runs uncalibrated with fast charge disabled - the
     * record sits correctly in EEPROM and NOTHING EVER READS IT.
     *
     * ⭐ That is exactly what shipped in `e74c7802` and was caught on HARDWARE,
     * 2026-09-28, by reading $300 and finding UNCAL|GATED set on a board whose
     * record had just been written and verified byte-identical (MEASUREMENTS
     * 2.359). ⛔ THIRTY NATIVE ASSERTIONS PASSED OVER IT, because every one of
     * them calls pmgr_calib_load() itself to set up the state under test - a
     * test that ARRANGES a call can never discover that production omits it.
     *
     * Placed after pmgr_pram_init() (both read EEPROM) and BEFORE the first
     * pmgr_tick_1s() can run, so no charging decision is ever taken against an
     * unloaded record. */
    pmgr_calib_load();

    pmgr_adc_init();

    /* AFTER pmgr_ports_init() (inside pmgr_handlers_init above), which leaves
     * PD6 an output driven low. pmgr_pwm_init() configures TCA0 and the CCL
     * route but leaves the output DISABLED - the original does not start the
     * PWM until :201, in pmgr_system_release(). */
    pmgr_pwm_init();

    tick_init();

#ifdef PMGR_SELFTEST
    /* Bench only - drives the ADB control line. Never built into a firmware
     * that goes into a machine; see pmgr_selftest.h for the jumper. Result is
     * latched on DBG0..DBG2 and the board then halts, so the code stays
     * readable instead of being overwritten by normal operation. */
    pmgr_selftest_report(pmgr_selftest_adb_capture());
    for (;;) { }
#endif

    /* ---- ColdEntry dispatch, pmgr.asm 204-207 --------------------------
     *
     * The hardware RESET vector is PMGRResetEntry -> `bra ColdEntry`
     * (:112-113), which sets Y=8. So reaching main() is ALWAYS a cold entry,
     * and the decision reduces to VIA_TEST:
     *
     *     VIA_TEST SET   -> jmp Sleep   : park with the 68000 held in reset
     *     VIA_TEST CLEAR -> release
     *
     * ⚠️ This must NOT be an unconditional release. A real Portable parks at
     * power-on and waits for a keypress - MEASUREMENTS.md 2.5 - and releasing
     * here regardless would start the machine when the original would not.
     *
     * pmgr_sleep() does not return until a wake event has brought the machine
     * up, because `jmp Sleep` never returns either: it falls through the park
     * loop into the wake path and ends at `jmp CommandReceive` (:1410).
     *
     * Interrupts stay DISABLED through either route: Apple's cli is at :221
     * (reset path) and :1409 (wake path), both AFTER SYS_RST is already high.
     * That is why both sequences poll SIXTYHZ directly instead of using it as
     * an interrupt. */
    /* pmgr.asm 190-203 runs on BOTH branches, BEFORE the dispatch at :204-207:
     * contrast validated and applied, PWM on, batteryNow, KBD_RST* released.
     * Doing it inside pmgr_system_release() would skip it whenever we park -
     * i.e. on every normal cold boot. */
    pmgr_pre_dispatch_init();

    if (pmgr_cold_should_park())
        pmgr_sleep();               /* :207 jmp Sleep */
    else
        pmgr_system_release();      /* :208-218 */

    /* Both paths leave the interrupt state as they found it - see the contract
     * at the top of pmgr_handlers.h - so exactly one sei() serves both, here,
     * once the machine is released either way. The original's equivalent is
     * `cli` (6502 ENABLE) at :221 on the reset path and :1409 on the wake
     * path; it can afford one per path because each has a single caller. */
    sei();

#ifdef PMGR_LOOP_MARKER
    /* ⛔ DIAGNOSTIC (MEASUREMENTS 2.161): DBG0 (J2-3) high inside the 60 Hz tick
     * block, DBG2 (J2-5) high inside pmgr_poll(). Finds what runs during the
     * ~3.9 ms of unanswered requests at the start of a save. */
    DBG0_PORT.OUTCLR = DBG0_bm; DBG0_PORT.DIRSET = DBG0_bm;
    DBG2_PORT.OUTCLR = DBG2_bm; DBG2_PORT.DIRSET = DBG2_bm;
#endif
    for (;;) {
#ifdef PMGR_LOOP_MARKER
        DBG2_PORT.OUTSET = DBG2_bm;
        pmgr_poll();
        DBG2_PORT.OUTCLR = DBG2_bm;
#else
        pmgr_poll();
#endif

        /* ⭐⭐ PRAM persistence, ONE EEPROM byte per pass, never waits
         * (MEASUREMENTS 2.155-2.157). Directly after pmgr_poll() so a pass
         * that just took a $31 write starts saving at once, while the bus
         * keeps being served between bytes. */
        pmgr_pram_service();

        /* pmgr.asm 1702-1714, the $FFF4 reset-switch vector. Polled rather
         * than vectored: the handler spends its whole life in tick-paced wait
         * loops, so there is nothing an interrupt would buy. A press ALWAYS
         * releases the machine, even when a cold boot would have parked it,
         * because it exits via ResetEntry (Y=0) and never reaches the
         * VIA_TEST test. */
        pmgr_reset_switch_service();
        pmgr_reset_pin_service();       /* PMGR_RESET* -> full cold restart */

        /* pmgr.asm 463 - the battery path parks the machine itself when the
         * level falls below deadBatteryLevel. Acted on HERE, outside any tick,
         * because pmgr_sleep()'s wait loop calls the tick and re-entering it
         * from inside would recurse. */
        if (pmgr_sleep_requested())
            pmgr_sleep();

        /* Take the whole backlog at once. The read-and-clear must be atomic:
         * the ISR increments s_tick, so a plain read followed by a store would
         * drop any edge landing between them. */
        uint8_t due;
        {
            uint8_t sreg = SREG;
            cli();
            due = s_tick;
            s_tick = 0;
            SREG = sreg;
        }

        if (due != 0u) {
            /* First tick is a full one - .ADBAction included. The rest advance
             * time only, so a starved loop catches up on the clock without
             * firing a burst of autopolls. */
#ifdef PMGR_LOOP_MARKER
            DBG0_PORT.OUTSET = DBG0_bm;
#endif
#ifdef PMGR_ADB_HOST_SERVICE
            pmgr_bus_latch_arm(true);           /* ADB may latch a command byte */
#endif
            pmgr_tick_60hz();
#ifdef PMGR_ADB_HOST_SERVICE
            pmgr_bus_latch_arm(false);
            /* ⭐ FIX A (design/ADB-HOST-SERVICE.md §10, MEASUREMENTS 2.208-2.209): serve a command byte latched during
             * the tick BEFORE anything else - the boot ROM gives up on its count byte after ~1.76 ms. Here in the
             * main loop, never inside the tick: a $70 sleep command parks in pmgr_sleep(), which calls the tick. */
            if (pmgr_bus_has_latched()) pmgr_poll();
            pmgr_tick_run_deferred();
#endif
            while (--due) pmgr_tick_catchup();
#ifdef PMGR_LOOP_MARKER
            DBG0_PORT.OUTCLR = DBG0_bm;
#endif
        }
    }
}

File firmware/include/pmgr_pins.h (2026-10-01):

/* GENERATED by gen_pins.py FROM THE BOARD (mcu-board/pmgr_mcu.kicad_pcb).
 * Do not edit by hand, and do not regenerate from MCU-BOARD-SCHEMATIC.md -
 * the board is what gets fabricated. */
#ifndef PMGR_PINS_H
#define PMGR_PINS_H

#include <avr/io.h>

/* Data bus: all eight bits on PORTA, so a bus read is one instruction.
   The PMGR handshake timing depends on that - never split across ports. */
#define BUS_PORT      PORTA

/*
 * ADB:
 * P4.0 / PD1 PMGR_ADB = control output to an external inverting
 *                       open-collector ADB driver. ⛔ Driven OPEN-DRAIN
 *                       in software - Hi-Z asserts, LOW releases, NEVER
 *                       driven HIGH. See pmgr_adb.c and MEASUREMENTS 2.58.
 * P4.1 / PD2 FDB      = direct ADB bus sense input.
 */

/* ---- PORTA ---- */
#define VIAD0_PORT             PORTA
#define VIAD0_bm               (1U << 0)   /* PA0, TQFP 62 */
#define VIAD1_PORT             PORTA
#define VIAD1_bm               (1U << 1)   /* PA1, TQFP 63 */
#define VIAD2_PORT             PORTA
#define VIAD2_bm               (1U << 2)   /* PA2, TQFP 64 */
#define VIAD3_PORT             PORTA
#define VIAD3_bm               (1U << 3)   /* PA3, TQFP 1 */
#define VIAD4_PORT             PORTA
#define VIAD4_bm               (1U << 4)   /* PA4, TQFP 2 */
#define VIAD5_PORT             PORTA
#define VIAD5_bm               (1U << 5)   /* PA5, TQFP 3 */
#define VIAD6_PORT             PORTA
#define VIAD6_bm               (1U << 6)   /* PA6, TQFP 4 */
#define VIAD7_PORT             PORTA
#define VIAD7_bm               (1U << 7)   /* PA7, TQFP 5 */

/* ---- PORTB ---- */
#define PMREQ_N_PORT           PORTB
#define PMREQ_N_bm             (1U << 0)   /* PB0, TQFP 8 */
#define PMACK_N_PORT           PORTB
#define PMACK_N_bm             (1U << 1)   /* PB1, TQFP 9 */
#define PMINT_N_PORT           PORTB
#define PMINT_N_bm             (1U << 2)   /* PB2, TQFP 10 */
#define SYS_RST_N_PORT         PORTB
#define SYS_RST_N_bm           (1U << 3)   /* PB3, TQFP 11 */
#define RESET_N_PORT           PORTB
#define RESET_N_bm             (1U << 4)   /* PB4, TQFP 12 */
#define PMGR_RESET_N_PORT      PORTB
#define PMGR_RESET_N_bm        (1U << 5)   /* PB5, TQFP 13 */
#define VIA_TEST_PORT          PORTB
#define VIA_TEST_bm            (1U << 6)   /* PB6, TQFP 14 */
#define ONESEC_N_PORT          PORTB
#define ONESEC_N_bm            (1U << 7)   /* PB7, TQFP 15 */

/* ---- PORTC ---- */
#define SOUND_LATCH_PORT       PORTC
#define SOUND_LATCH_bm         (1U << 0)   /* PC0, TQFP 16 */
#define OFF_HOOK_PORT          PORTC
#define OFF_HOOK_bm            (1U << 1)   /* PC1, TQFP 17 */
#define SIXTYHZ_PORT           PORTC
#define SIXTYHZ_bm             (1U << 2)   /* PC2, TQFP 18 */
#define PMGCLK_F_PORT          PORTC
#define PMGCLK_F_bm            (1U << 4)   /* PC4, TQFP 22 */

/* ---- PORTD ---- */
#define ADC_IN_PORT            PORTD
#define ADC_IN_bm              (1U << 0)   /* PD0, TQFP 26 */
#define PMGR_ADB_PORT          PORTD
#define PMGR_ADB_bm            (1U << 1)   /* PD1, TQFP 27 */
#define FDB_PORT               PORTD
#define FDB_bm                 (1U << 2)   /* PD2, TQFP 28 */
#define DISP_BLANK_N_PORT      PORTD
#define DISP_BLANK_N_bm        (1U << 3)   /* PD3, TQFP 29 */
#define MODEM_INS_N_PORT       PORTD
#define MODEM_INS_N_bm         (1U << 4)   /* PD4, TQFP 30 */
#define SOUND_OFF_PORT         PORTD
#define SOUND_OFF_bm           (1U << 5)   /* PD5, TQFP 31 */
#define PMGR_PWM_PORT          PORTD
#define PMGR_PWM_bm            (1U << 6)   /* PD6, TQFP 32 */
#define PMGR_IN0_PORT          PORTD
#define PMGR_IN0_bm            (1U << 7)   /* PD7, TQFP 33 */

/* ---- PORTE ---- */
#define AKD_PORT               PORTE
#define AKD_bm                 (1U << 0)   /* PE0, TQFP 36 */
#define STOP_CLK_PORT          PORTE
#define STOP_CLK_bm            (1U << 1)   /* PE1, TQFP 37 */
#define CHRG_ON_N_PORT         PORTE
#define CHRG_ON_N_bm           (1U << 2)   /* PE2, TQFP 38 */
#define KBD_RST_N_PORT         PORTE
#define KBD_RST_N_bm           (1U << 3)   /* PE3, TQFP 39 */
#define HICHG_PORT             PORTE
#define HICHG_bm               (1U << 4)   /* PE4, TQFP 40 */
#define RING_DETECT_PORT       PORTE
#define RING_DETECT_bm         (1U << 5)   /* PE5, TQFP 41 */
#define MODEM_AB_PORT          PORTE
#define MODEM_AB_bm            (1U << 6)   /* PE6, TQFP 42 */

/* ---- PORTF ---- */
#define DBG2_PORT              PORTF
#define DBG2_bm                (1U << 3)   /* PF3, TQFP 47 */
#define DBG1_PORT              PORTF
#define DBG1_bm                (1U << 4)   /* PF4, TQFP 48 */
#define DBG0_PORT              PORTF
#define DBG0_bm                (1U << 5)   /* PF5, TQFP 49 */

/* ---- PORTG ---- */
#define SYS_PWR_N_PORT         PORTG
#define SYS_PWR_N_bm           (1U << 0)   /* PG0, TQFP 52 */
#define MINUS5_EN_PORT         PORTG
#define MINUS5_EN_bm           (1U << 1)   /* PG1, TQFP 53 */
#define SOUND_PWR_N_PORT       PORTG
#define SOUND_PWR_N_bm         (1U << 2)   /* PG2, TQFP 54 */
#define SERIAL_PWR_N_PORT      PORTG
#define SERIAL_PWR_N_bm        (1U << 3)   /* PG3, TQFP 55 */
#define MODEM_PWR_N_PORT       PORTG
#define MODEM_PWR_N_bm         (1U << 4)   /* PG4, TQFP 58 */
#define HD_PWR_N_PORT          PORTG
#define HD_PWR_N_bm            (1U << 5)   /* PG5, TQFP 59 */
#define SCC_CNTRL_PORT         PORTG
#define SCC_CNTRL_bm           (1U << 6)   /* PG6, TQFP 60 */
#define IWM_CNTRL_PORT         PORTG
#define IWM_CNTRL_bm           (1U << 7)   /* PG7, TQFP 61 */

/* ---- M50753 port -> our port transforms (checked by gen_pins.py) ----
 *
 * Apple operates on whole port BYTES in places (Power_Command; eor Port_P1
 * in BatteryManage; the sleep path). Our bit orders differ per port as a
 * consequence of the interposer routing remap. Any handler consuming a port
 * bitmap MUST apply the right transform - none of them is the identity.
 */
#define PMGR_P0_PORT        PORTG
#define PMGR_P0_EXACT_REVERSAL 1   /* our bit = 7 - P0 bit */

#define PMGR_P1_PORT        PORTE
#define PMGR_P1_SHIFT       (-1)   /* our bit = P1 bit -1 */

/* P3: SPLIT across ports ['B', 'D'] - NO byte-level transform.
 * Byte-wise code for P3 must be written bit-by-bit. */
#define PMGR_P3_SPLIT       1

#define PMGR_P4_PORT        PORTD
#define PMGR_P4_SHIFT       (+1)   /* our bit = P4 bit +1 */

/* Handshake lines are ACTIVE LOW. */
#define ASSERT_LOW(p,m)    ((p).OUTCLR = (m))
#define DEASSERT_HIGH(p,m) ((p).OUTSET = (m))
#define PIN_IS_LOW(p,m)    (((p).IN & (m)) == 0)

#endif /* PMGR_PINS_H */

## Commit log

2026-10-01 Macintosh Portable PMGR replacement - first public release
    An open replacement for the Mitsubishi M50753 power manager in the
    Macintosh Portable: an interposer that solders onto the original
    footprint, an AVR128DB64 MCU board, an optional J21 development
    breakout, the firmware, and a build guide.
    Exported from the development repository at tag public-v0.1. Every
    Gerber layer and drill hole was checked against its board file, and the
    firmware builds standalone to the image validated on hardware.
    [pmgr_breakout_j21-BOM.csv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]
2026-10-01 Mark the release as version 0.1, prototype
    [pmgr_interposer_v2-B_Cu.gbl, pmgr_interposer_v2-B_Mask.gbs, pmgr_interposer_v2-B_Silkscreen.gbo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]
2026-10-01 Power-cycle after any programmer operation
    [pmgr_interposer_v2-B_Cu.gbl, pmgr_interposer_v2-B_Mask.gbs, pmgr_interposer_v2-B_Silkscreen.gbo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]
2026-10-01 Add photos of the boards and the installed stack
    [pmgr_interposer_v2-B_Cu.gbl, pmgr_interposer_v2-B_Mask.gbs, pmgr_interposer_v2-B_Silkscreen.gbo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]
2026-10-01 Add reference measurements and pin diagrams
    [pmgr_interposer_v2-B_Cu.gbl, pmgr_interposer_v2-B_Mask.gbs, pmgr_interposer_v2-B_Silkscreen.gbo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]
2026-10-01 Add the AVR pin table and the charging graph
    [pmgr_interposer_v2-B_Cu.gbl, pmgr_interposer_v2-B_Mask.gbs, pmgr_interposer_v2-B_Silkscreen.gbo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]
2026-10-01 Caveat the charging graph; describe the active investigation
    [pmgr_interposer_v2-B_Cu.gbl, pmgr_interposer_v2-B_Mask.gbs, pmgr_interposer_v2-B_Silkscreen.gbo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]
2026-10-01 Name the logic board as a possible cause, not only the hybrid
    [pmgr_interposer_v2-B_Cu.gbl, pmgr_interposer_v2-B_Mask.gbs, pmgr_interposer_v2-B_Silkscreen.gbo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]
2026-10-01 State it was only installed and tested in a Portable M5120
    [pmgr_interposer_v2-B_Cu.gbl, pmgr_interposer_v2-B_Mask.gbs, pmgr_interposer_v2-B_Silkscreen.gbo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]
2026-10-01 Add a step-by-step guide to programming the AVR
    [pmgr_interposer_v2-B_Cu.gbl, pmgr_interposer_v2-B_Mask.gbs, pmgr_interposer_v2-B_Silkscreen.gbo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]
2026-10-01 PRAM survives power removal: document it and how to reset it
    [pmgr_interposer_v2-B_Cu.gbl, pmgr_interposer_v2-B_Mask.gbs, pmgr_interposer_v2-B_Silkscreen.gbo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]
2026-10-01 Say up front that this is fine-pitch soldering
    [pmgr_interposer_v2-B_Cu.gbl, pmgr_interposer_v2-B_Mask.gbs, pmgr_interposer_v2-B_Silkscreen.gbo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]
2026-10-01 Fix calibration validation, flash input checks and the ROM build command
    - tools/pmgr_calib_fit.py now refuses (exit 1) a residual over 2 counts
    or a span under 0.80 V, and prints the record command with --resid.
    - tools/pmgr_flash_with_pram.py validates every input before erasing.
    - The byte-exact ROM build is make EXTRA_CFLAGS=-DPMGR_FAITHFUL_ROM.
    - Calibration pairs must come from a board flashed without a record.
    [pmgr_interposer_v2-B_Cu.gbl, pmgr_interposer_v2-B_Mask.gbs, pmgr_interposer_v2-B_Silkscreen.gbo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]
2026-10-02 Say where the battery levels come from
    The threshold values are Apple's, read from the original M50753 firmware
    (knee = literal 208, LOW 78, STAY_ASLEEP 70 computed, DEAD 62); the ROM
    stores no voltages. The voltages are our calibration on an unmodified
    Portable. HICHGLevel (200) is a separate setting, not the knee.
2026-10-11 Fix fast charge across sleep; support recreation hybrids
    Fast charge shares a port with lines the firmware restores on wake, and
    the restore also put fast charge back to its pre-sleep state: a charger
    plugged in while asleep did not fast-charge after the wake, and a fast
    charge that finished while asleep was switched back on. The original
    chip updates its saved copy whenever it switches fast charge; this does
    the equivalent. Checked on hardware in both directions.
    The calibration record now says which hybrid is fitted. With a
    recreation hybrid (cut-off ~5.92 V) the warning and sleep points move
    to 6.20 V and 6.05 V and the level reported to the Mac is rescaled onto
    Apple's range, so Mac OS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
2026-10-11 Refuse old calibration records by default; test recreation thresholds end to end
    Records made before 0.1.12 (version 1) carry no hybrid type, and the
    firmware treats them as original. Re-flashing a recreation board with
    its old calib.args therefore succeeded but dropped the recreation
    warning and sleep points. The flash tool now refuses a version-1 record
    unless --v1-is-original is given, and the README and BUILD.md tell
    upgraders to rebuild the record with --hybrid.
    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
2026-10-16 Lower the recreation-hybrid warning levels (6.10 / 6.02 V)
    On a real pack the 0.1.12 recreation levels (6.20 V warning, 6.05 V
    sleep) warned with hours of use left. 0.1.14 uses 6.10 V and 6.02 V,
    still well above the recreation hybrid's ~5.92 V cut-off. Tested on two
    packs and confirmed on a bench-supply step-down: Mac OS warns, then
    puts the machine to sleep itself before the PMGR's own sleep point, and
    the machine resumes and charges normally. Mac OS times its later
    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
2026-10-20 Support the PowerBook 100; fix the PWM output and register $EE
    The PowerBook 100 uses the same M50753 power manager. With the same boards
    and the same firmware it now boots to the Finder, its brightness dial works,
    it sleeps and wakes, and Mac OS shows its whole low-battery sequence. Tested
    on one machine on a bench supply: charging, calibration and a closed case are
    not yet tried.
    Fixes:
    - The PWM output (M50753 pin 57) was never driven: an AVR128DB silicon
    erratum (DS80000915) ignored the write that enables it. On the Portable
    that line is the LCD contrast; on the PowerBook 100 it is the backlight
    brightness. Measured at 926-935 Hz with the original's duty table.
    - Register $EE read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
2026-10-21 PowerBook 100 SCSI Disk Mode; fix the $E2 port bit and the $E8 clock view
    SCSI Disk Mode now works on the PowerBook 100. The SCSI Disk Adapter grounds
    HDI-30 pin 1, which reaches the M50753's pin 48 (about 91 ohm); the ROM
    reads it as bit 5 of register $EE at startup. These boards do not connect
    pin 48, so one hand-added wire carries it through the DF12's unused
    position 50 to the AVR's PF2 (docs/BUILD.md). PF2 has its pull-up on, so a
    board without the wire boots normally and the same firmware still runs a
    Portable. Shown: pin 1 grounded at startup gives the SCSI disk-mode screen
    (ID 1); removed, a normal boot; a Portable without the wire, unchanged.
    Also:
    - $E2 bit 0 (P10) reads 1, as App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
2026-10-26 Add rev B boards: SCSI Disk Mode on the boards, and an MCU board that fits the Portable
    Rev A and rev B now sit side by side, each page saying what it is for and
    what it fixes. Rev B is designed and checked but not yet fabricated; rev A
    is the version that has been built and tested.
    - Interposer rev B: castellation 48 -> DF12 position 50, so the PowerBook
    100's SCSI Disk Mode line is on the board. Castellation numbers on the
    silkscreen; a +5 V trace moved off the edge. Castellations unchanged.
    - MCU board rev B: DF12 position 50 -> PF2, so with the rev B interposer
    disk mode needs no wire. The board sits 5 mm toward its J2 end: rev A
    does not fit the Portable with the case closed (i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
